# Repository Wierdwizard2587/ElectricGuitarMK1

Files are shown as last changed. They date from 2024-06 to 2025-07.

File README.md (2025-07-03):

# Electronic Guitar MK1

> A self-built, digitally-enhanced electric guitar featuring onboard effects, audio output and removable battery supply all integrated within a custom made Guitar.

---

## TL;DR Overview

- DIY portable electric guitar with integrated digital effects and modular power/audio system  
- Final version features Teensy 4.0, onboard FX, rotary encoder UI, OLED display, amp/speaker output, battery or DC power, and RGB lighting  
- Entire build: woodwork, PCBs, 3D prints, firmware, and more  
- Early prototype (Mk0) failed due to poor electrical design and overcomplex hardware, rebuilt from scratch over 12+ months with newly acquired engineering and fabrication skills  



---

## Specs (MK1)

### Hardware Features

- **Microcontroller:** Teensy 4.0 (600 MHz ARM Cortex M7, 1MB RAM)  
- **Audio Codec:** SGTL5000 via Teensy Audio Shield Rev D2  
- **Display:** 2.42" 128x64 OLED  
- **UI:** 4x rotary encoders (Adafruit I2C) with push buttons  
- **Output Options:**
  - 1W LM386 speaker amp + 8Ω speaker  
  - 3.5mm headphone jack  
  - 1/4" AUX output  
- **SD Card:** for saving and loading effect presets  



### Physical Design

- Custom red cedar guitar body with Strat-style neck and 22 frets  
- SSH passive pickup layout with 5-way selector  
- CNC acrylic panels for access and wiring  
- Modular 3D-printed brackets for internals  
- Magnetic battery bay  



### Power System

- **Battery:** 4S 18650 3500mAh Li-ion (16.8V max)  
- **BMS:** With overcharge/discharge protection  
- **Power Switching:** Automatically defaults to DC jack if plugged in  
- **Regulation:** L7805 LDO for logic, raw voltage for amp  
- **Runtime:** ~12 hours full load; much longer with optimized settings  



### RGB Lighting

- 6x WS2812B addressable LEDs  
- Controlled via UI with adjustable patterns and brightness  
- 5V from Teensy board, expandable via breakout  
- Mounted in a custom 3D enclosure with acrylic cover  
- See [Demo](https://github.com/Wierdwizard2587/ElectricGuitarMK1/raw/main/Progress%20Photos/Woodworking/IMG_9428.MOV)

### Design Decisions

- Abandoned analog FX + digipots due to impractical voltage/current handling  
- Digital FX chain implemented using Teensy Audio Library and CODEC  
- Custom single-layer PCB with JST headers for modularity  
- UI system built around I2C rotary encoders and OLED display  
- 3D-printed brackets standardized component mounting across internal assemblies  

### Tools and Processes

#### PCB Manufacturing

- **Chemical Etching:** Photoresist UV method with ferric chloride; scrapped due to accuracy and double-sided complexity  
- **CNC Milling:** Used FlatCAM to generate G-code, 3018 CNC and Candle for trace and drill cuts  

#### SMD Soldering

- **Stencil:** CNC-cut mylar sheets for paste application  
- **Soldering:** SMD components placed and reflowed on hot plate  



#### CAD and Design

- **KiCAD:** For schematic capture and board layout  
- **FreeCAD:** For PCB enclosure, LED mount, Guitar Body, Acrylic Plates/Panels and Router Jigs  

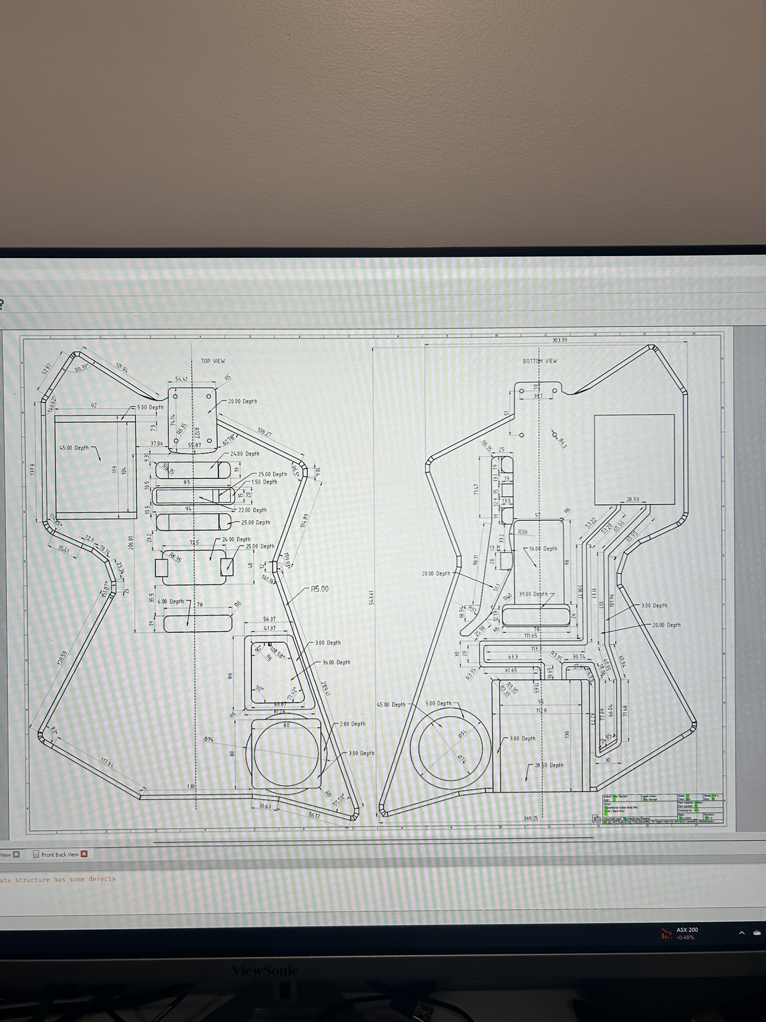
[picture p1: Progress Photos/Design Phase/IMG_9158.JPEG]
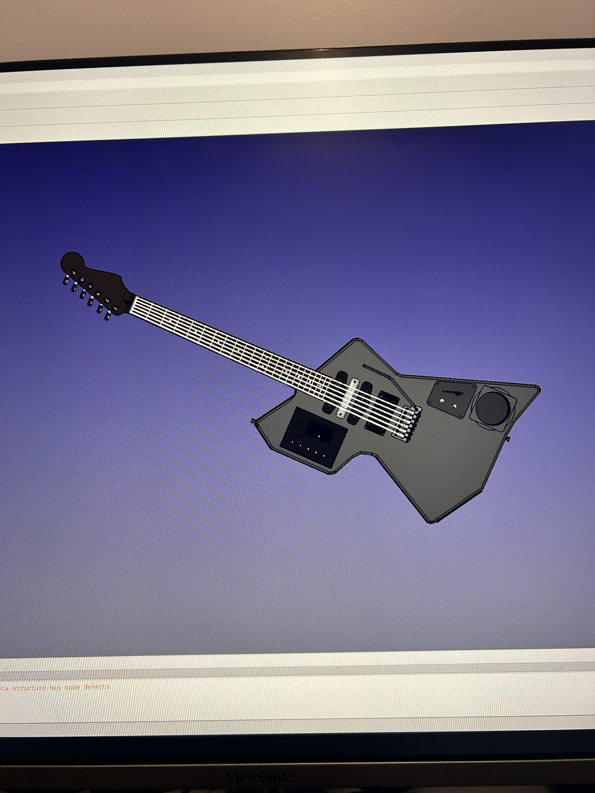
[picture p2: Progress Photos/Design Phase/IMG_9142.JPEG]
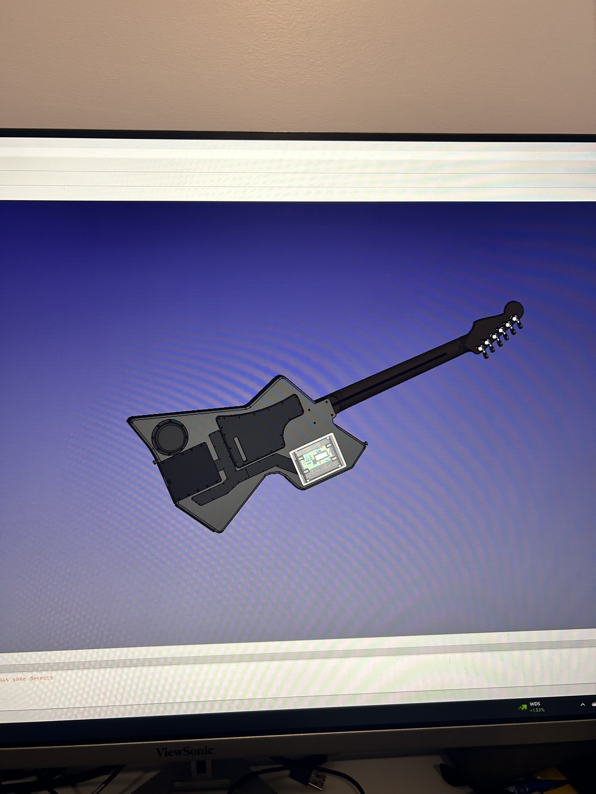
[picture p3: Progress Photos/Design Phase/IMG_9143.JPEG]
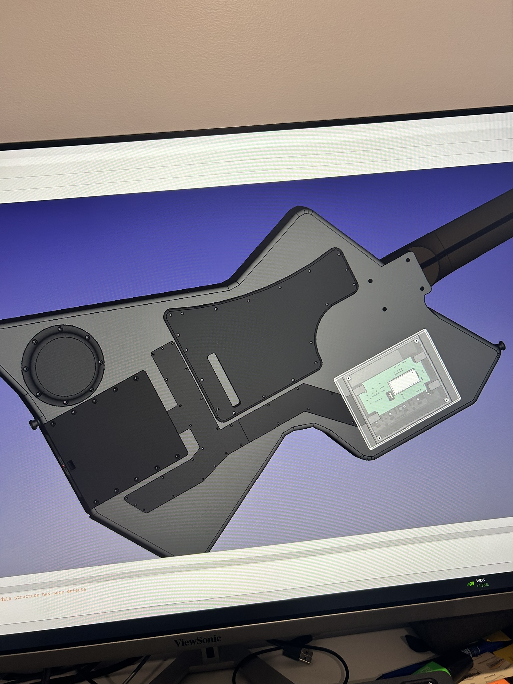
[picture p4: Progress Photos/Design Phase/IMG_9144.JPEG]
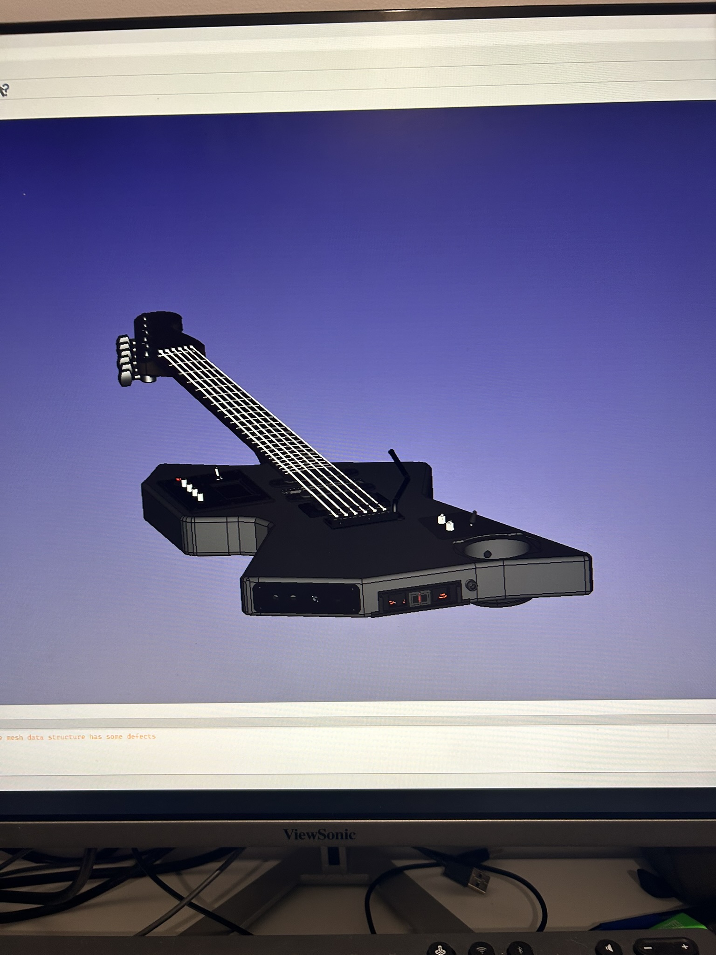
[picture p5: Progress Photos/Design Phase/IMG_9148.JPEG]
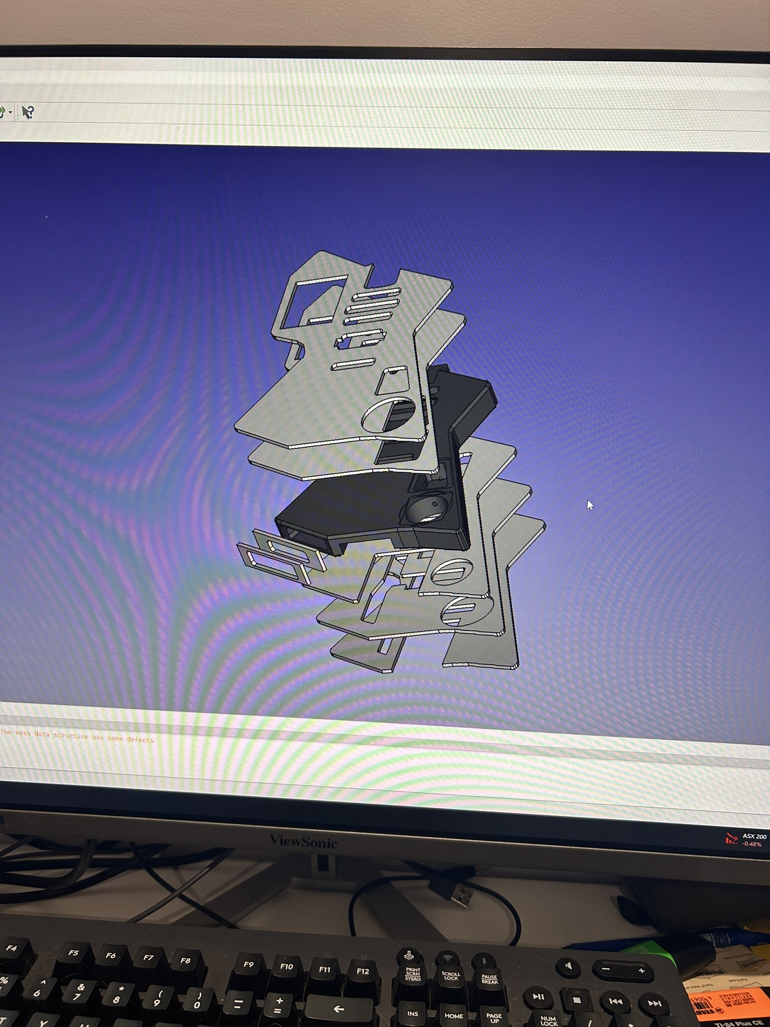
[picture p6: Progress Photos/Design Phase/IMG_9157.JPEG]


---

## Mk0 — The Failed First Attempt

The Mk0 was an ambitious retrofit of a cheap Stratocaster copy, originally sourced second-hand for $20 AUD. At the time, I had no electrical engineering knowledge and was only experienced with basic Arduino and Raspberry Pi projects.

### Body and Structural Work
- The original guitar was re-routed to fit electronics, resulting in reduced structural integrity and balance
- Body was repainted and cleaned up with minor woodworking skills from high school
- Attempted to house a Raspberry Pi, amplifier board, fans, wiring and more. all glued to plywood mounts inside the guitar



### Electronics and Power Mistakes
- Raspberry Pi 3B+ used for DSP software and effects switching via Linux keybinds
- 10x SPST buttons mapped to GPIO pins, wired manually without debounce or shielding
- Cooling: a heatsink and fan were mounted directly into the guitar body, protruding through the top
- Power: attempted to use a Makita 18V battery regulated by a voltage divider made from two 10W resistors (which exploded)
- Eventually switched to an XL6009 buck converter, mounted haphazardly on wood



### Audio and Shielding Failures
- Output sound had constant noise and interference, making the guitar unplayable
- Tried shielding the cavity with copper tape and spray enamel, but issues persisted
- Lack of analog audio knowledge led to poor layout and grounding, introducing hum and feedback

### Realization and Reset
- The experience made clear the importance of proper voltage regulation, shielding, grounding, and modular design
- Mk0 taught me the value of planning, measurement, and using the right components for audio and power
- In October 2023, I decided to scrap the build and committed to rebuilding everything from scratch

---

## The Learning Curve

To succeed with Mk1, I developed and refined skills across multiple disciplines:

- **Electrical theory and circuit design**
  - Learned core principles like Ohm’s Law, impedance, decoupling, signal paths, and analog vs digital tradeoffs by experimenting with breadboarded op-amp FX circuits and 555 timer modules.

- **Breadboarding, debugging, and perfboarding**
  - Built multiple guitar pedal-style analog effects, troubleshooting noise, biasing, and layout issues. Early soldering mistakes taught me good pad heating, proper joint inspection, and signal path discipline.

- **Custom PCB manufacturing**

  - *Chemical etching:* Photoresist and ferric chloride techniques worked for simple single-sided boards, but alignment and etch consistency were poor for complex layouts.

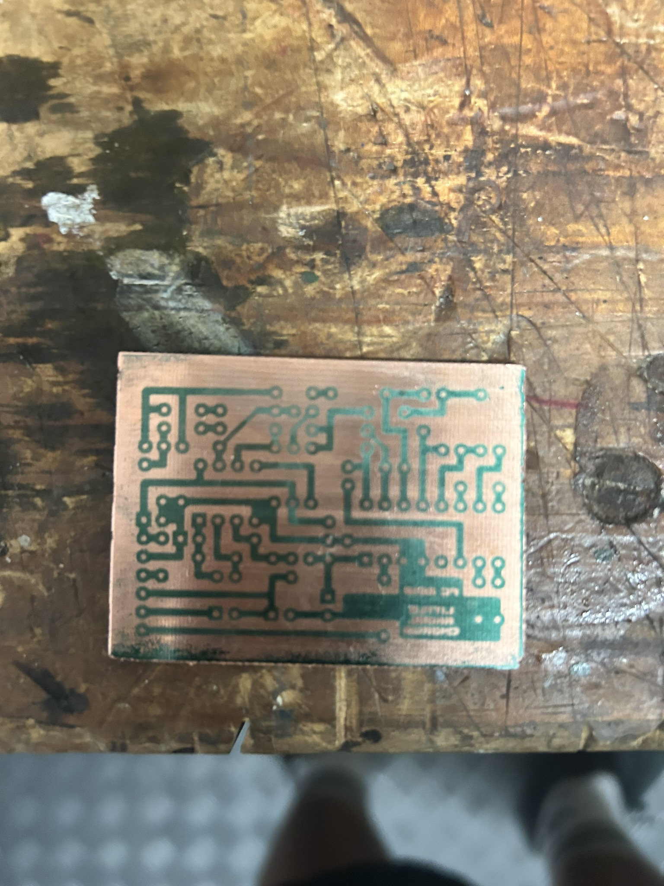
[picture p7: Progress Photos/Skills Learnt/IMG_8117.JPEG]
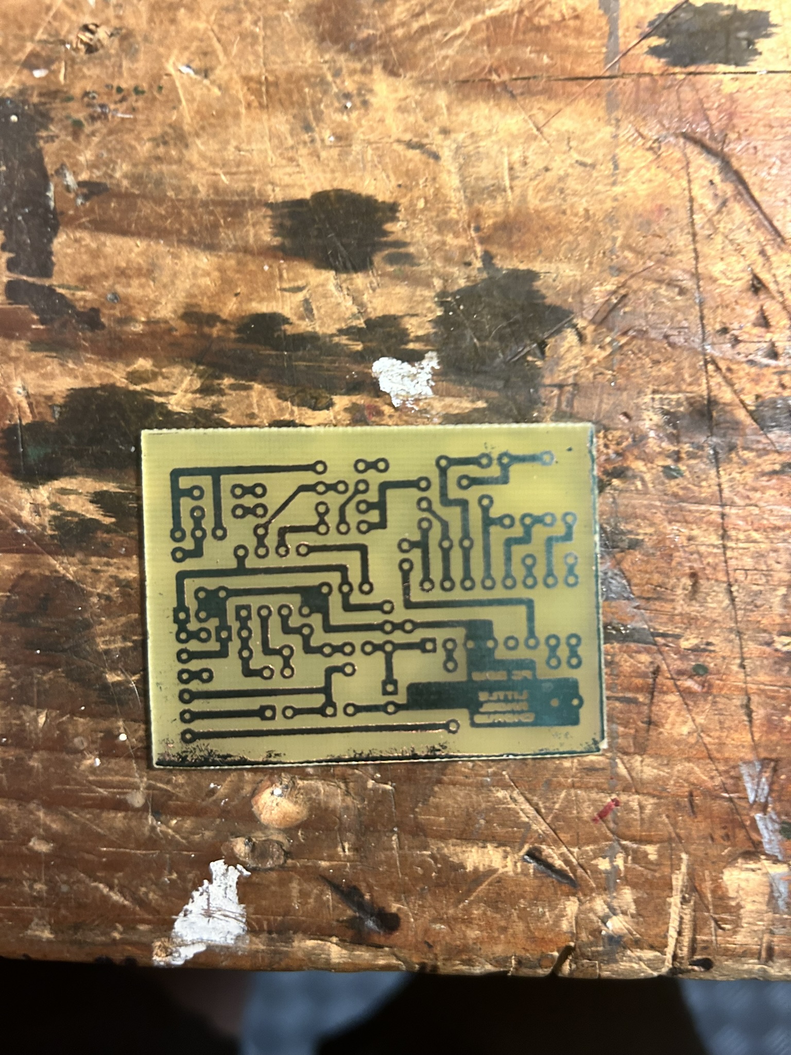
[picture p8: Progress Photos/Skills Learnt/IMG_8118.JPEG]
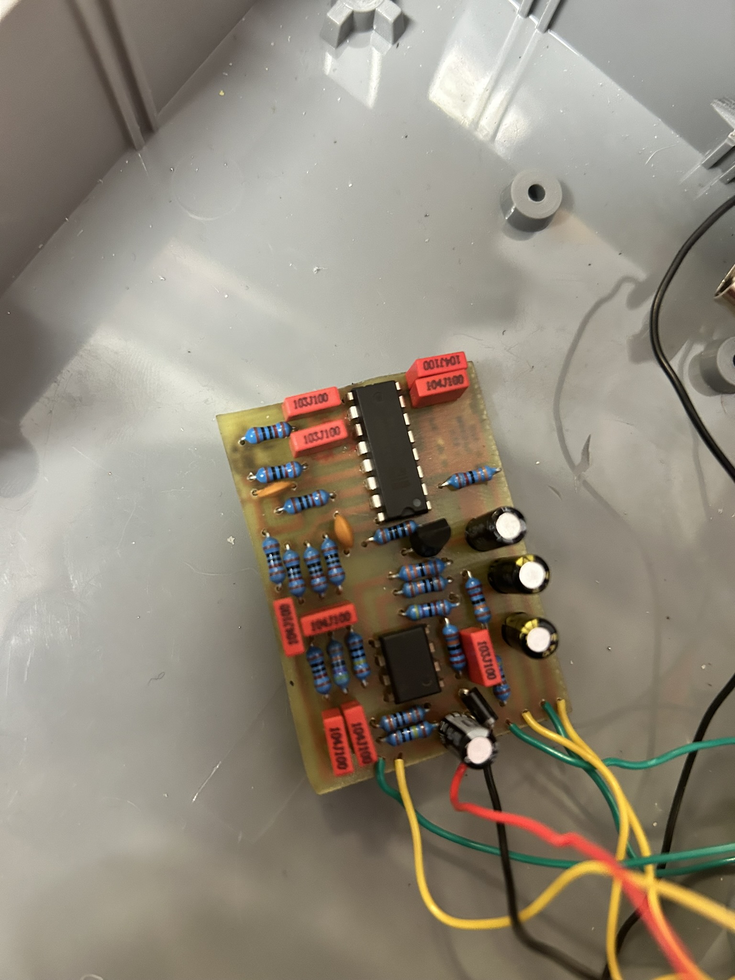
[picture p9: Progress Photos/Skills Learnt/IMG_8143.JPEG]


https://github.com/user-attachments/assets/e00821a1-996f-4fed-b84c-7d602e0a9be1

  - *CNC milling:* FlatCAM used to generate G-code from KiCAD Gerbers. I used a 3018 CNC with Candle to reliably cut traces and drill holes. Ultimately switched to ordered boards for reliability.

https://github.com/user-attachments/assets/3b78b966-fe12-4d0b-8b32-34254987f5ec

- **SMD workflow and hot plate reflow soldering**
  - Designed and cut my own mylar stencils for solder paste, allowing for precise paste application and fast assembly of SMD components on the hot plate.

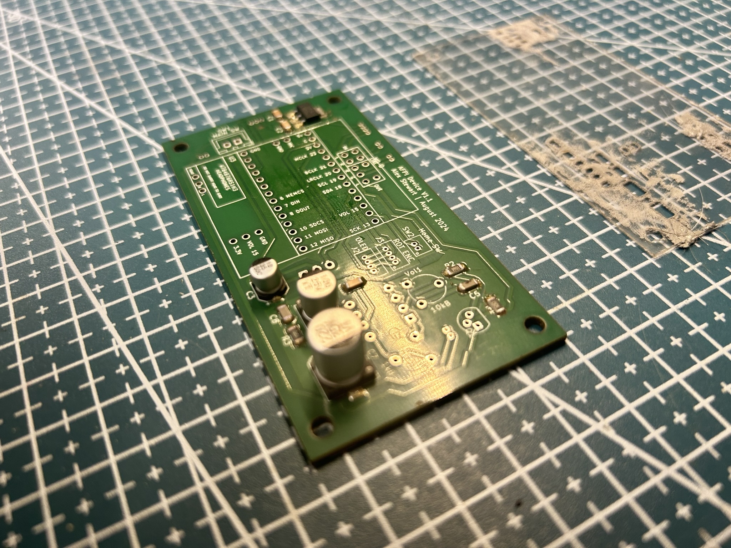
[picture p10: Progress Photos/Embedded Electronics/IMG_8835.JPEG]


- **Power systems and battery safety**
  - Studied Li-ion cell characteristics, pack balancing, protection circuits, and BMS behavior. Designed a 4S pack system with safe cutoff and swappable magnetic connection.

- **CAD and fabrication**
  - *KiCAD:* Used to design full schematics and board layouts with JST headers and part footprints.

  - *FreeCAD:* Modeled body routing templates, control panel shapes, bracket mounting, and tolerance-critical neck fits.

- **CNC woodworking and mechanical precision**
  - Created tight-fitting neck pockets and pickup cutouts with minimal play, ensuring mechanical stability and alignment.
 
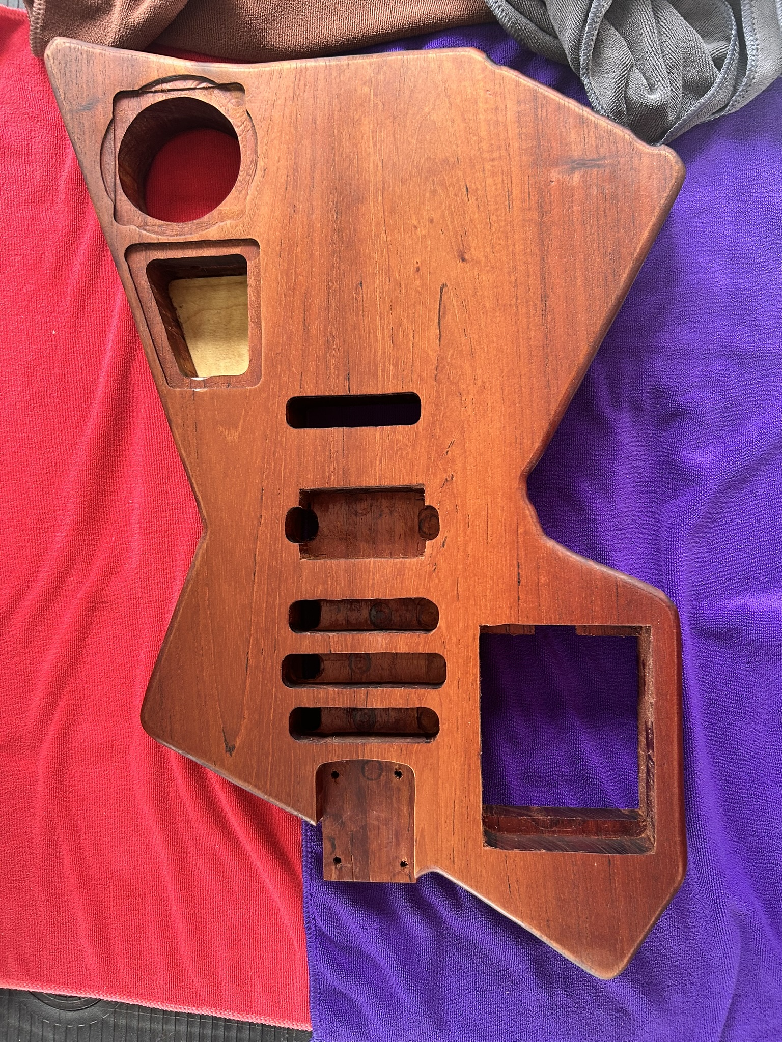
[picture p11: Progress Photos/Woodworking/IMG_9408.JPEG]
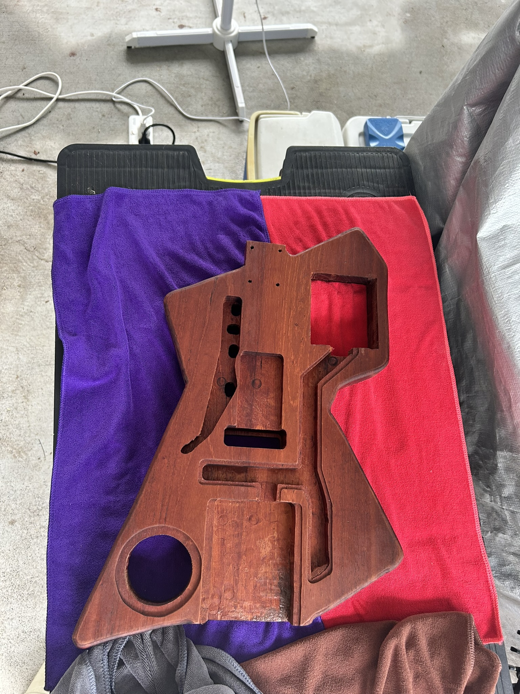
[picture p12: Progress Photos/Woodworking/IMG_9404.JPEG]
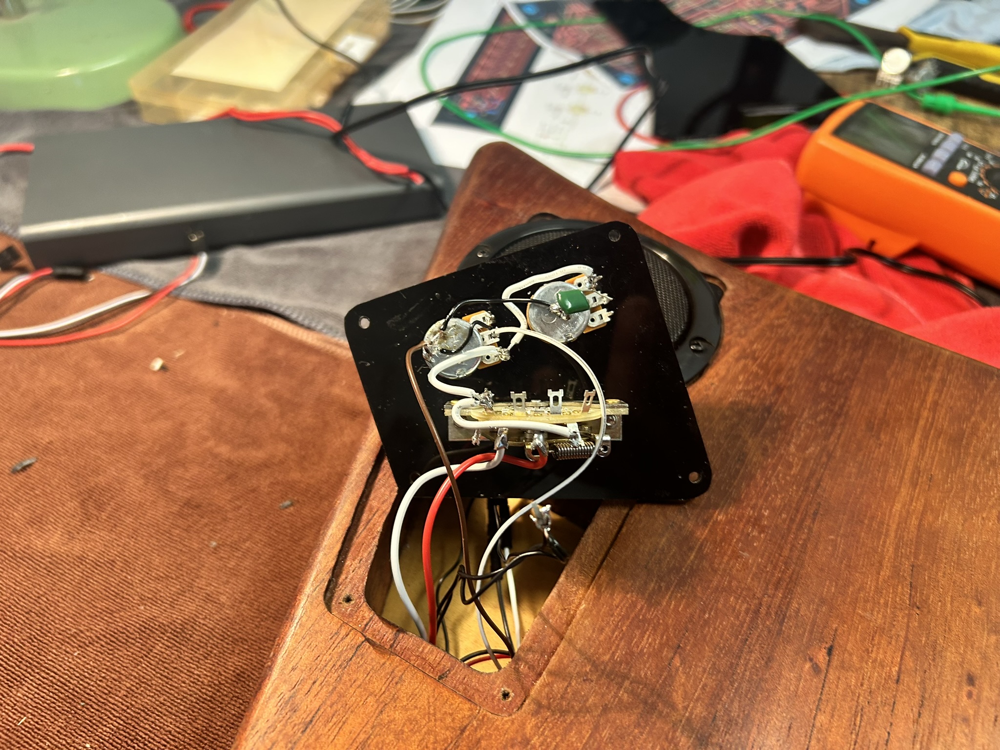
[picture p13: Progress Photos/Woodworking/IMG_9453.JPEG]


Each step of the learning process fed directly into the reliability and performance of the final Mk1 design.

---

## Final Words

This project started with a failed experiment and turned into a comprehensive learning journey in electrical engineering, embedded systems, and digital fabrication. Every element—hardware, software, and mechanical—was designed, built, and tested from scratch with the goal of making a fully integrated, self-contained electric guitar. I am very proud of what I was able to accomplish and am very excited to now use and build this new knowledge and gained abilitys to even bigger and better things!

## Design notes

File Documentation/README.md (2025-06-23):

# The Electronic Guitar MK1

## Introduction
During the second half of 2023, I began experimenting with a concept of an 'all in one portable electric guitar'. The device would contain built in electronics for digital audio effects and signal modulation with an optional audio output between a 1 watt amplifier and speaker, headphone amp with 3.5mm jack, or a 1/4" jack for aux out for further modulation and amplification, all of which powered by either a removable rechargable battery or 2.5mm DC jack. My first attempt at this concept to put it simply was a failure, but a neccesary one. read [here]((#electric-guitar-mk0-first-attempt)) for the full

## My Prior Background
I had started my Computer Science degree at the start of 2023 and before that had fiddled around with arduino and ESP32 Microcontroller projects, creating basic circuits and novice C programming with some very basic electrical theory, however this project was nothing like I had ever attempted. I also had some experience with woodworking through high school and personal jobs in the shed at home, but the craftmanship I needed for this task was also not ready. While my background was rather unimpressive, I was determined to complete this project myself by any means. This of course meant a great deal of learning and problem solving, and over the next 1.5 years (august 2023 - december 2024) I did sought out to do just that. 







## Features
The features of this Guitar are seperated into the following sections:

### AFPI Features:
  - **Teensy 4.0 microcontroller:**
    - ARM Cortex M7 600MHz 
    - 2mB Flash
    - 1mB RAM
    - 40 GPIO pins
    - 100mA @ 5V
   
    <br> 
  - **Teensy Audio Shield Rev D2:**
    - SGTL5000 Audio Codec
    - integrated Headphone Amp
    - SD Card Slot

    <br>
  - **Power regulation**
    - Recieves power input from battery/DC jack
    - L7805 LDO regulator to reduce voltage to 5V for Digital Circuit components
    - uses regular voltage from input for speaker amp for a louder sound

    <br> 
  - **Adafruit IC2 Quad Rotary Encoder Board:**
    - Communication to Microcontroller via IC2 protocol
    - 1x4 20 position rotary encoders with push down buttons
   
     <br> 
  - **2.42 inch 128*64 OLED Display Module:**
    - SSD1306 OLED display library
   
    <br> 
  - **1 watt Speaker amplifier:**
    - lm386 op amp
    - trimmable Volume and Gain for installation
    - based on Ruby Amp design

  - Firmware switchable audio output between Built in speaker, Headphones or Aux out
  - Aux in 3.5mm jack for playing external audio from other devices
  - SD card memory to recall saved user settings for effects and other settings











### Power Supply Features:
  - Power supply from either DC 2.5mm Barrel Connector OR 3500mAh battery
  - switches to wired power supply over the battery automatically when plugged in

  - **DC Input:**
    - 2.5mm DC 
    - 7V to 18V input

  - **Removable 3500mAh Battery:**
    - 4S 18650 3.7V Li ion Battery cell arrangement
    - 16.8 Nominal Voltage
    - 10.5V over-discharge and 17V over-charge protection
    - magnetic connecting pins between battery casing and built-in battery slot in guitar
    - ~12hrs run time when operating speaker on maximum volume, full LED brightness and OLED brightness.
    - Run time increases greatly when limiting brightness and audio settings slightly
    - Capability to provide Battery charge to Microcontroller in future modifications



### RGB Lighting Features:
  - 1x6 row of WS2812B 5050 SMD NeoPixel RGB LED's
  - each LED uniquely addressable via IC2 Protocol, allowing for any colour and brightness on each LED
  - Control the LEDs settings and the preset effect styles selectable through the User Interface
  - 5V operating Voltage and data supplied from AFPI to RGB lighting PCB
  - RGB PCB including extra Data Output for modular expansion of lighting to other areas of the Guitar
  - RGB PCB encased in a 3d printed mounting bracket to fit in the body, as well as to attach clear acrylic cover plate

https://github.com/Wierdwizard2587/ElectricGuitarMK1/raw/refs/heads/main/Progress%20Photos/Woodworking/IMG_9428.MOV

### Physical Design Features:
  - Custom designed Body shape
  - Red Ceder wood for body
  - CNC milled Acrylic Top and Back plates for switch plates and wire route coverings
  - 3D printed Components for mounting electrical components into Body as modular sections



### Guitar specific Features:
  - SSH passive pickup layout, with pins available for active pickups
  - 22 Fret stratocaster syle neck
  - 5 way pickup selector switch layout
  - 1x master Volume potentiometer
  - 1x master Gain potentiometer

## Electric Guitar MK0 (first attempt) 
I first came up with this concept around July 2023, where a regeular guitar could be retro fitted with electronics to create a cheap, simple portable electric guitar. Oh how wrong i was. With some moderate experience in playing with arduino's and Raspberry Pi's, a good bit of wood working experience with dad, and no electrical engineering experience, I set out on accomplishing my goal.



For the Guitar itself i had a chinese strat laying around that i found second hand at an Op shop for 20$ that i never used, because obviously it sounded terrible. The electronics were barely working, it was missing a tuning peg and just sounded terrible! but after cleaning it up, re wiring it with new cheap pickups and new tuning pegs, it was somewhat playable. i then totally destroyed the guitar by then routing out long wire tracks and spots for components among other things. I reckon it was less then half the weight of its former self when i was done with it. I repainted The boddy and neck Black and moved on to the electronics.




For the Audio processing and effect portion of the guitar i chose a raspberry Pi 3 B+, not for any spec reasons, but because it was just laying around. after fiddling around with some DSP applications for linux i chose one that had multiple effect presets and keybinded them each. I then got 10 SPST buttons and wired each individual one to 10 different GPIO pins very inefficiently. these buttons then used a simple script to map each button to a key press to toggle the presets, that was the entire interface portion of the Guitar. The processing requirements for the DSP really created a cooling problem for the guitar which i 'solved' by mounting a large heatsink and fan to the processor, which required a large hole to be cut out of the guitar body, not only to accomodate the Pi itself, but also to fit the fan raised by the large heat pipes. 



For power delivery, about the only thing to stay remotely similar to the final guitar was to have a DC jack and a Battery, however instead of a custom battery, I made use of a makita 18v tool battery and just got a mount from ebay, which wasnt a terrible idea as using a pre existing battery would make it easier, however we are a ryobi family! i had to borrow a mates battery which got definetly annoying when he needed it for work. 

Now this is where it gets really embarrasing. my lack of electrical engineering knowledge led me down the research path of how i can regulate the voltage down to 5v for the Raspberry Pi, and i discovered the voltage divider circuit which obviously is not the way to solve my problem due to the incredible inneficiency and the lack of any actual regulation of voltage, but 18yr old me thought it did. so strapped 2x 10Watt resistors into a very poor arrangement to lower the voltage, which most definetely wasn't done correctly and one of them blew up. this lead me to try the DCDC converter XL6009 which was better. But again, I was mounting all this on bare ply wood with hot glue, it was such a poor design approach from me. I included an audio amplifier module for 2 speakers at 5w 4ohm each.

After testing it out together, all i got was terrible noise from the pickups, resulting in an unplayable device. I wrapped the interior with copper tape and sprayed in with a non conductive enamel coat to prevent shorts. This was done to prevent EMI which i though was the issue, however looking back on it, there were definetely other issues at play relating to my poor designing techniques and a million other things. 




This all took place between July 2023 to October 2023 and after repeated failures to get the guitar to sound remotely like a guitar, I decided to remember what worked, what didnt and i scrapped my current progress and started from scratch. I vowed to create as much of the guitar myself so i could fully grasp what was taking place within the product. whether it be circuit boards, programming, woodworking and CNC work, I then embarked on a 1 year long journey to create the Electronic Guitar no matter the cost, and no matter what problems stood in my way as this became personal. I would take my time researching not only different components, tools, techniques and practises, but also the basis of managing a project. From the design progress, cost management and other essential skills, I used my determination to succeed (My goal was to get it finished by July 2024, I was far off).

## Skills learnt

## Technical In Depth

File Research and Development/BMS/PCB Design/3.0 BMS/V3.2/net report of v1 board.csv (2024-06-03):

Net Code | Net Name | Pad Count | Via Count | Via Length | Track Length | Die Length | Net Length | F.Cu | B.Cu
001 | Batt + | 11 | 2 | 3.2000 mm | 93.7471 mm | 0.0000 mm | 96.9471 mm | 72.3739 mm | 21.3732 mm
002 | Batt - | 4 | 0 | 0.0000 mm | 42.4740 mm | 0.0000 mm | 42.4740 mm | 42.4740 mm | 0.0000 mm
003 | Chgr operating 12V+ | 4 | 0 | 0.0000 mm | 34.8560 mm | 0.0000 mm | 34.8560 mm | 34.8560 mm | 0.0000 mm
004 | Chgr sgl 15V+ | 3 | 0 | 0.0000 mm | 49.2855 mm | 0.0000 mm | 49.2855 mm | 49.2855 mm | 0.0000 mm
005 | 5v attiny out | 6 | 0 | 0.0000 mm | 93.5043 mm | 0.0000 mm | 93.5043 mm | 93.5043 mm | 0.0000 mm
006 | Net-(Q2-B) | 2 | 0 | 0.0000 mm | 4.3180 mm | 0.0000 mm | 4.3180 mm | 4.3180 mm | 0.0000 mm
007 | DCG SW VCC | 2 | 0 | 0.0000 mm | 2.9492 mm | 0.0000 mm | 2.9492 mm | 2.9492 mm | 0.0000 mm
008 | Reg Batt 9v | 4 | 2 | 3.2000 mm | 74.9748 mm | 0.0000 mm | 78.1748 mm | 50.0106 mm | 24.9642 mm
009 | CGE SW VCC | 2 | 2 | 3.2000 mm | 65.4986 mm | 0.0000 mm | 68.6986 mm | 20.7501 mm | 44.7485 mm
010 | Net-(Q7-B) | 2 | 0 | 0.0000 mm | 4.6160 mm | 0.0000 mm | 4.6160 mm | 4.6160 mm | 0.0000 mm
011 | Battery Vref | 3 | 0 | 0.0000 mm | 37.4979 mm | 0.0000 mm | 37.4979 mm | 37.4979 mm | 0.0000 mm
012 | Batt SW VCC | 2 | 0 | 0.0000 mm | 35.3685 mm | 0.0000 mm | 35.3685 mm | 35.3685 mm | 0.0000 mm
013 | Net-(R12-Pad2) | 3 | 2 | 3.2000 mm | 40.3498 mm | 0.0000 mm | 43.5498 mm | 11.4621 mm | 28.8877 mm
014 | Net-(U4-P2) | 2 | 0 | 0.0000 mm | 12.9343 mm | 0.0000 mm | 12.9343 mm | 12.9343 mm | 0.0000 mm
015 | 15v+ CHG VCC | 8 | 0 | 0.0000 mm | 45.5027 mm | 0.0000 mm | 45.5027 mm | 45.5027 mm | 0.0000 mm
016 | Net-(U4-P1) | 2 | 0 | 0.0000 mm | 12.1084 mm | 0.0000 mm | 12.1084 mm | 12.1084 mm | 0.0000 mm
017 | Net-(D1-A) | 3 | 0 | 0.0000 mm | 13.4361 mm | 0.0000 mm | 13.4361 mm | 13.4361 mm | 0.0000 mm
018 | Net-(U3-FB) | 4 | 0 | 0.0000 mm | 17.9684 mm | 0.0000 mm | 17.9684 mm | 17.9684 mm | 0.0000 mm
020 | OUT 9V+ | 2 | 0 | 0.0000 mm | 15.4306 mm | 0.0000 mm | 15.4306 mm | 15.4306 mm | 0.0000 mm
021 | Net-(B1-B1+) | 3 | 1 | 1.6000 mm | 119.5845 mm | 0.0000 mm | 121.1845 mm | 7.5880 mm | 111.9964 mm
022 | Net-(B1-B1-) | 5 | 1 | 1.6000 mm | 203.4040 mm | 0.0000 mm | 205.0040 mm | 8.1461 mm | 195.2580 mm
023 | Net-(B2-B1-) | 5 | 1 | 1.6000 mm | 73.8197 mm | 0.0000 mm | 75.4197 mm | 49.6937 mm | 24.1261 mm
024 | Net-(B3-B1-) | 5 | 0 | 0.0000 mm | 223.5093 mm | 0.0000 mm | 223.5093 mm | 223.5093 mm | 0.0000 mm
025 | Net-(B4-B1-) | 3 | 0 | 0.0000 mm | 151.4014 mm | 0.0000 mm | 151.4014 mm | 151.4014 mm | 0.0000 mm
028 | Charge supplied VCC | 2 | 0 | 0.0000 mm | 28.0132 mm | 0.0000 mm | 28.0132 mm | 28.0132 mm | 0.0000 mm
032 | Net-(U4-P0) | 2 | 2 | 3.2000 mm | 82.4156 mm | 0.0000 mm | 85.6156 mm | 61.7874 mm | 20.6282 mm
033 | GND | 19 | 10 | 16.0000 mm | 304.4670 mm | 0.0000 mm | 320.4670 mm | 182.9421 mm | 121.5249 mm
034 | charger GND bypass | 2 | 0 | 0.0000 mm | 2.3711 mm | 0.0000 mm | 2.3711 mm | 2.3711 mm | 0.0000 mm
035 | Net-(Q1-G) | 4 | 2 | 3.2000 mm | 45.6061 mm | 0.0000 mm | 48.8061 mm | 15.3627 mm | 30.2434 mm
036 | Net-(SW1A-B) | 2 | 0 | 0.0000 mm | 18.6588 mm | 0.0000 mm | 18.6588 mm | 18.6588 mm | 0.0000 mm

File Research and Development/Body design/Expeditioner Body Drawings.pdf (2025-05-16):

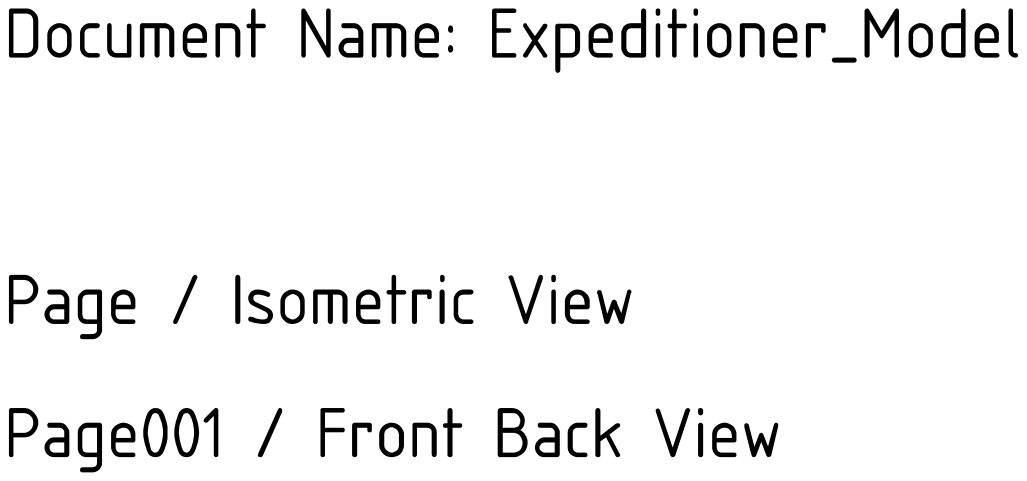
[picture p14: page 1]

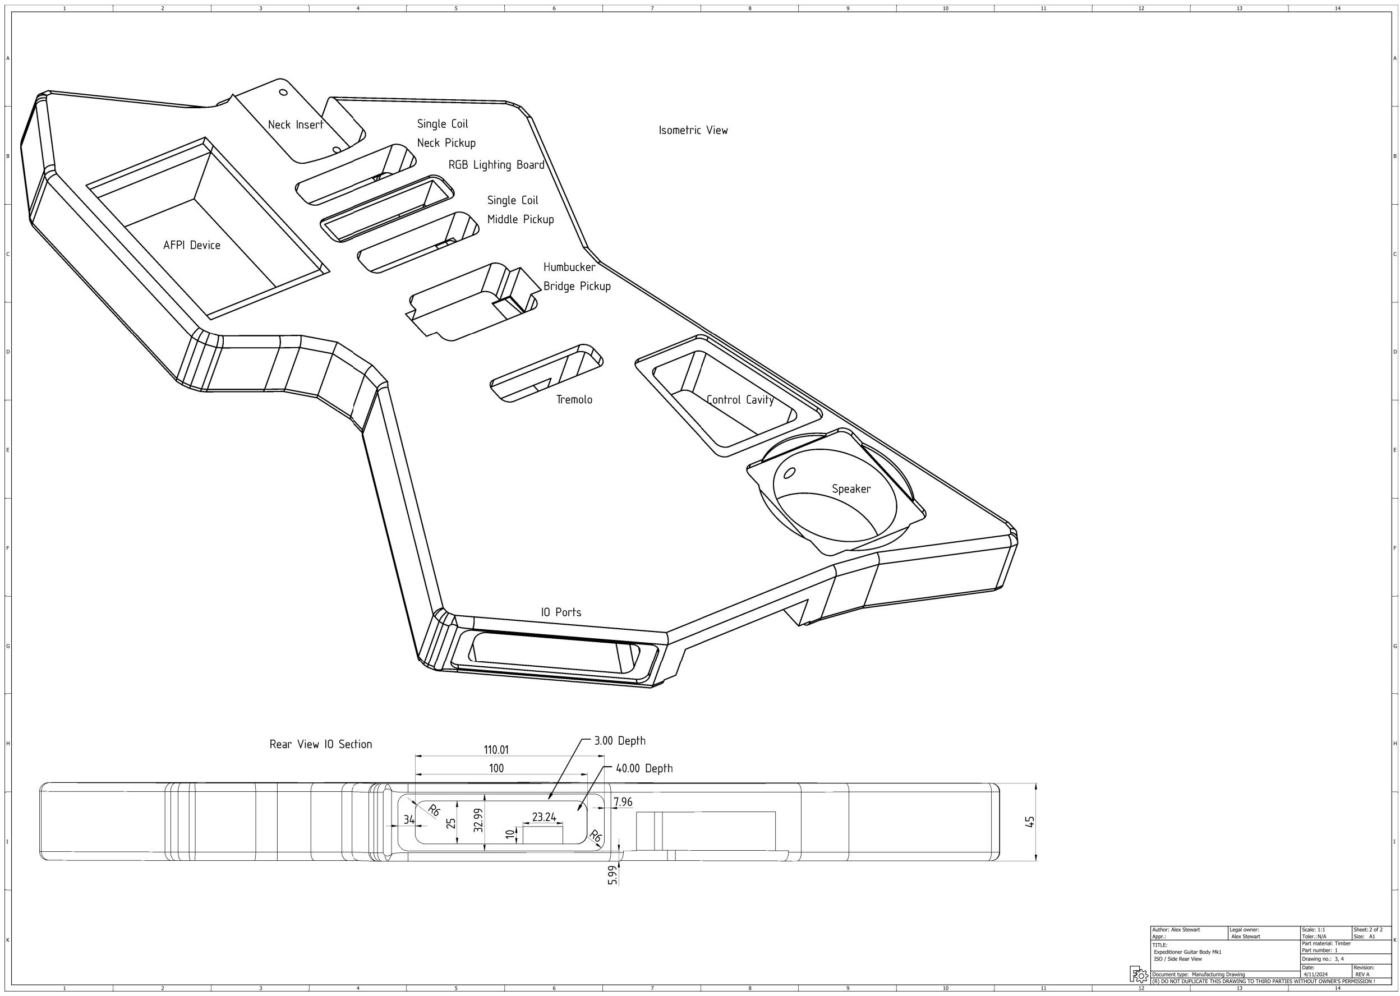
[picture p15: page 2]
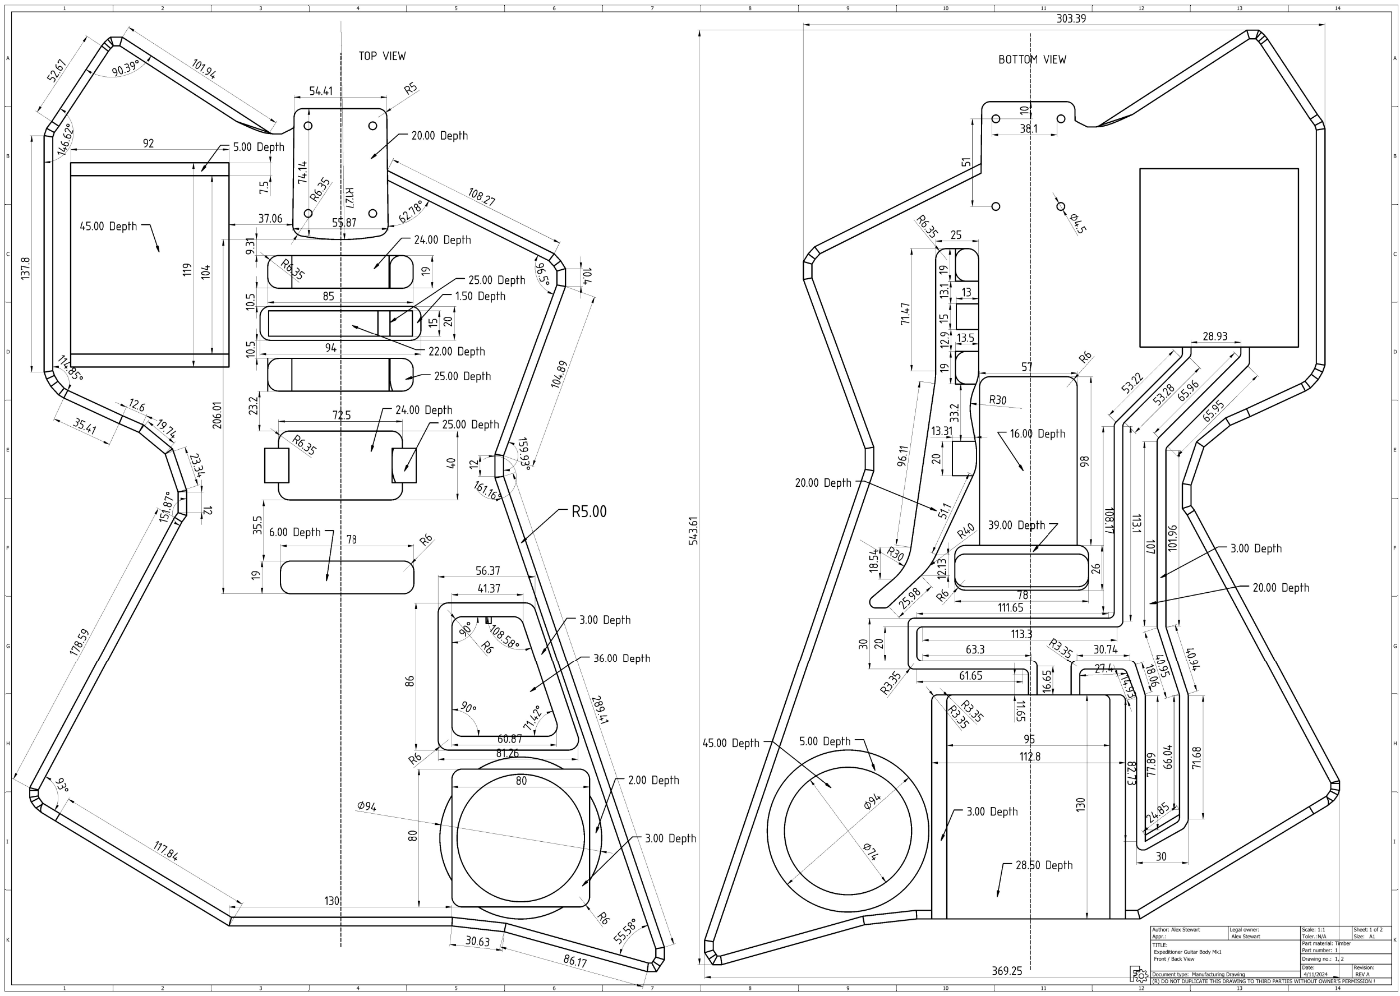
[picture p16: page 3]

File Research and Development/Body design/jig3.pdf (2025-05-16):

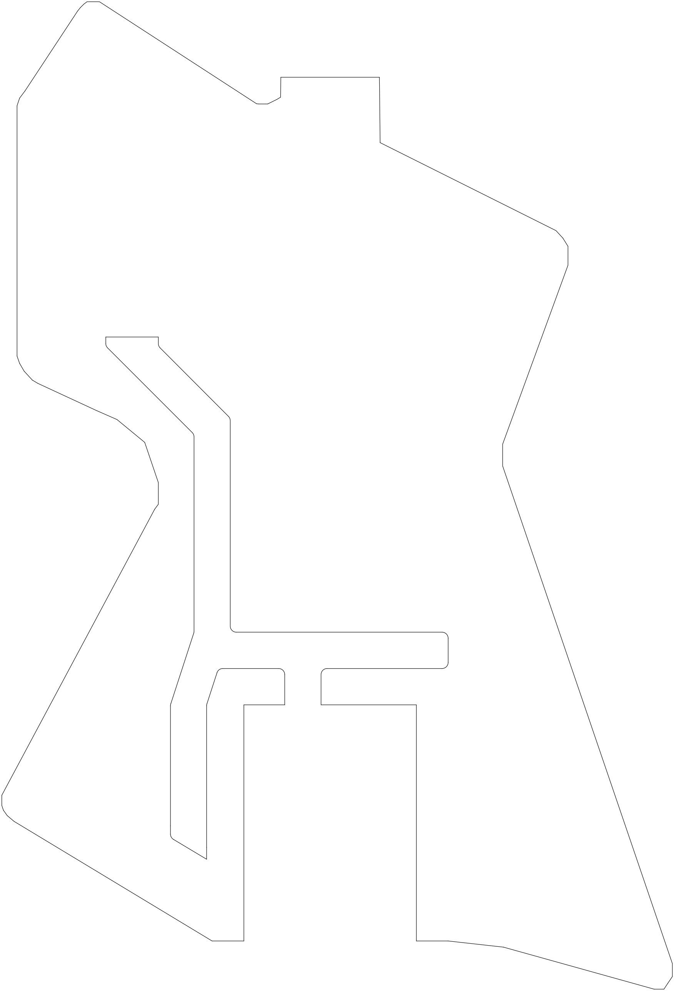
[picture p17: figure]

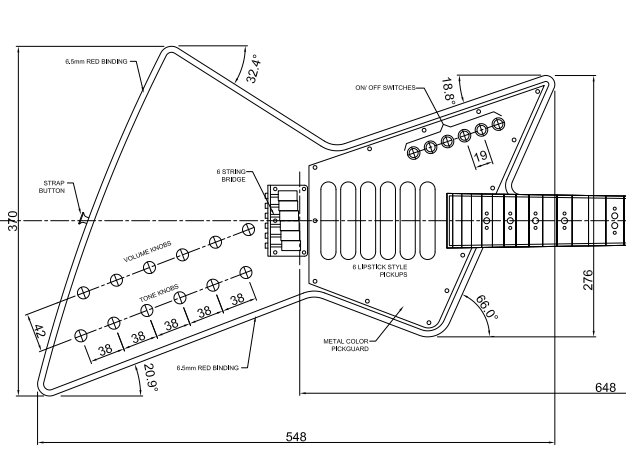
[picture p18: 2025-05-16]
Research and Development/Body design/3d models and docs/bettie model doc snippet.png

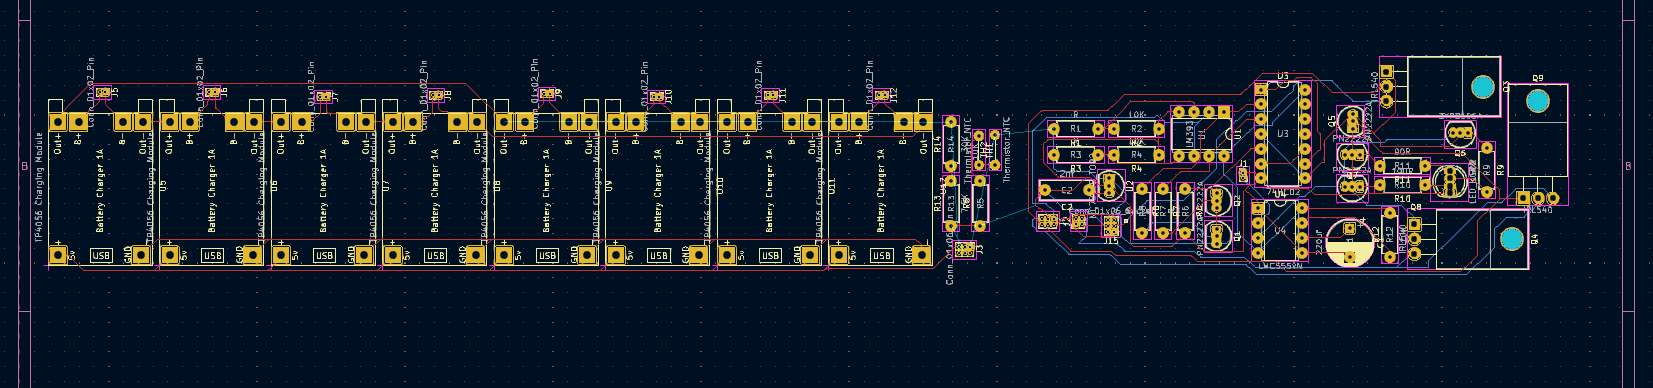
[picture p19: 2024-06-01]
Research and Development/BMS/PCB Design/1.0 BMS/1ST attempt bms pcb layout.png

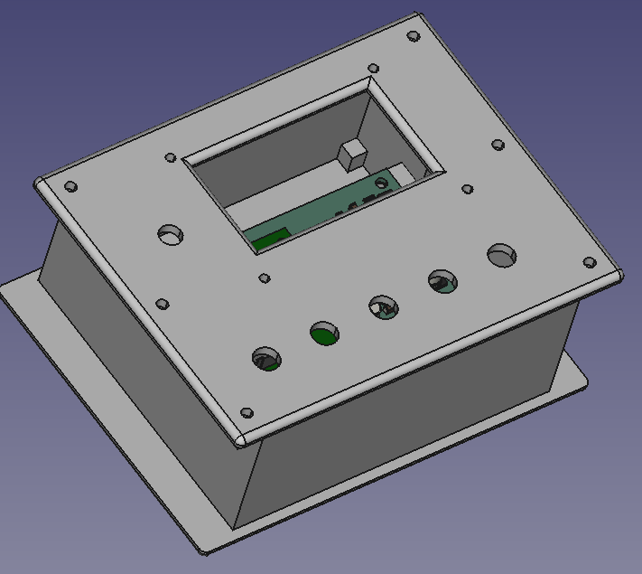
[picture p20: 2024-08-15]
Research and Development/Interface Section/AFPI/Enclosure Design/AFPI Final Documents/Enclosure Images/top view without peripherals.png

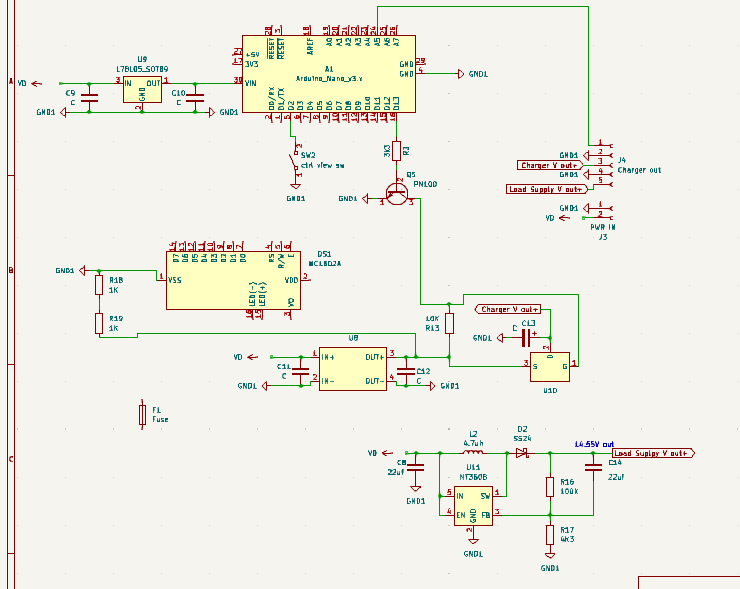
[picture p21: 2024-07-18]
Research and Development/BMS/PCB Design/3.0 BMS/V3.2/charger design v1.png

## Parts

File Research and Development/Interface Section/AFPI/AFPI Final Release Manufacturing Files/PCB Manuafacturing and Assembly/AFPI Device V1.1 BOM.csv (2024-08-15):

Id | Designator | Footprint | Quantity | Designation | Supplier and ref
1 | C1 | C_1206_3216Metric | 1 | 330nf
2 | C5,C8 | C_1206_3216Metric | 2 | 47n
3 | C2 | C_1206_3216Metric | 1 | 100nf
4 | Gain1 | Potentiometer_Piher_PT-6-V_Vertical | 1 | 1kB
5 | SW1 | JST_XH_B2B-XH-A_1x02_P2.50mm_Vertical | 1 | MAIN SW
6 | J2 | JST 1.25mm THT 01x04 | 1 | OLED
7 | Vol1 | Potentiometer_Piher_PT-6-V_Vertical | 1 | 10kB
8 | R1 | R_1206_3216Metric | 1 | 1M5
9 | C6 | CP_Elec_6.3x7.7 | 1 | 100u
10 | J3 | JST 1.25mm THT 01x04 | 1 | ROT ENC
11 | C3 | CP_Elec_5x5.4 | 1 | 10uf 35V
12 | U1 | SOT-223 | 1 | L7805
13 | C7 | CP_Elec_8x10.5 | 1 | 220u
14 | R2 | R_1206_3216Metric | 1 | 3k9
15 | R3 | R_1206_3216Metric | 1 | 10R
16 | SW2 | JST 1.25mm THT 01x02 | 1 | Home SW
17 | U3 | Teensy 4.0 audioshield | 1 | Teensy4.0_AudioShield_REVD
18 | U2 | DIP-8_W7.62mm | 1 | LM386
19 | C4 | C_1206_3216Metric | 1 | 100n
20 | Q1 | TO-92 | 1 | MPF102
21 | J9 | JST 1.25mm THT 01x02 | 1 | BACK I
22 | J6 | JST 1.25mm THT 01x02 | 1 | SP O
23 | J1 | JST_XH_B3B-XH-A_1x03_P2.50mm_Vertical | 1 | Batt I
24 | J5 | JST 1.25mm THT 01x02 | 1 | HP O
25 | J8 | JST 1.25mm THT 01x04 | 1 | LINE I/PKP V
26 | J7 | JST 1.25mm THT 01x02 | 1 | AU O
27 | J4 | JST 1.25mm THT 01x03 | 1 | RGB O

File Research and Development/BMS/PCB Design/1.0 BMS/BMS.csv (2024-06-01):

Source: | C:\Users\acste\Desktop\BMS\BMS\BMS.kicad_sch
Date: | 2/04/2024 11:28:19 AM
Tool: | Eeschema 7.0.9
Generator: | C:\Program Files\KiCad\7.0\bin\scripting\plugins/bom_csv_grouped_by_value.py
Component Count: | 35
Collated Components:
Item | Qty | Reference(s) | Value | LibPart | Footprint | Datasheet | DNP
1 | 1 | C1 | 220uf | Device:C_Polarized | Capacitor_THT:CP_Radial_D8.0mm_P5.00mm | ~
2 | 1 | C2 | 2nf | Device:C |  | ~
3 | 1 | D1 | LED_KGRB | Device:LED_KGRB | LED_THT:LED_D5.0mm-4_RGB | ~
4 | 1 | J1 | Screw_Terminal_01x02 | Connector:Screw_Terminal_01x02 |  | ~
5 | 1 | J2 | Conn_01x04_Pin | Connector:Conn_01x04_Pin |  | ~
6 | 1 | J3 | Conn_01x03_Pin | Connector:Conn_01x03_Pin |  | ~
7 | 1 | J4 | Conn_01x06_Pin | Connector:Conn_01x06_Pin |  | ~
8 | 1 | K1 | SANYOU_SRD_Form_C | Relay:SANYOU_SRD_Form_C | Relay_THT:Relay_SPDT_SANYOU_SRD_Series_Form_C | http://www.sanyourelay.ca/public/products/pdf/SRD.pdf
9 | 5 | Q1, Q2, Q5, Q7, Q8 | PN2222A | Transistor_BJT:PN2222A | Package_TO_SOT_THT:TO-92_Inline | https://www.onsemi.com/pub/Collateral/PN2222-D.PDF
10 | 1 | Q3 | IRL540 | Transistor_FET:IRF540N | Package_TO_SOT_THT:TO-220-3_Vertical | http://www.irf.com/product-info/datasheets/data/irf540n.pdf
11 | 1 | Q6 | ZVP2106A | Transistor_BJT:PN2222A | Package_TO_SOT_THT:TO-92_Inline | https://www.onsemi.com/pub/Collateral/PN2222-D.PDF
12 | 5 | R1, R3, R6, R7, R8 | R | Device:R | Resistor_THT:R_Axial_DIN0207_L6.3mm_D2.5mm_P7.62mm_Horizontal | ~
13 | 4 | R2, R4, R5, R12 | 10K | Device:R | Resistor_THT:R_Axial_DIN0207_L6.3mm_D2.5mm_P7.62mm_Horizontal | ~
14 | 1 | R9 | 150R | Device:R | Resistor_THT:R_Axial_DIN0207_L6.3mm_D2.5mm_P7.62mm_Horizontal | ~
15 | 1 | R10 | 100R | Device:R | Resistor_THT:R_Axial_DIN0207_L6.3mm_D2.5mm_P7.62mm_Horizontal | ~
16 | 1 | R11 | 90R | Device:R | Resistor_THT:R_Axial_DIN0207_L6.3mm_D2.5mm_P7.62mm_Horizontal | ~
17 | 1 | R13 | 30K | Device:R | Resistor_THT:R_Axial_DIN0207_L6.3mm_D2.5mm_P7.62mm_Horizontal | ~
18 | 1 | R14 | 7.5K | Device:R | Resistor_THT:R_Axial_DIN0207_L6.3mm_D2.5mm_P7.62mm_Horizontal | ~
19 | 2 | TH1, TH2 | Thermistor_NTC | Device:Thermistor_NTC | Resistor_THT:R_Axial_DIN0204_L3.6mm_D1.6mm_P5.08mm_Vertical | ~
20 | 1 | U1 | LM393 | Comparator:LM393 | Package_DIP:DIP-8_W7.62mm | http://www.ti.com/lit/ds/symlink/lm393.pdf
21 | 1 | U2 | MC78L05_TO92 | Regulator_Linear:MC78L05_TO92 | Package_TO_SOT_THT:TO-92_Inline | https://www.onsemi.com/pub/Collateral/MC78L00A-D.PDF
22 | 1 | U3 | 74HC02 | 74xx:74HC02 | Package_DIP:DIP-14_W7.62mm | http://www.ti.com/lit/gpn/sn74hc02
23 | 1 | U4 | LMC555xN | Timer:LMC555xN | Package_DIP:DIP-8_W7.62mm | http://www.ti.com/lit/ds/symlink/lmc555.pdf

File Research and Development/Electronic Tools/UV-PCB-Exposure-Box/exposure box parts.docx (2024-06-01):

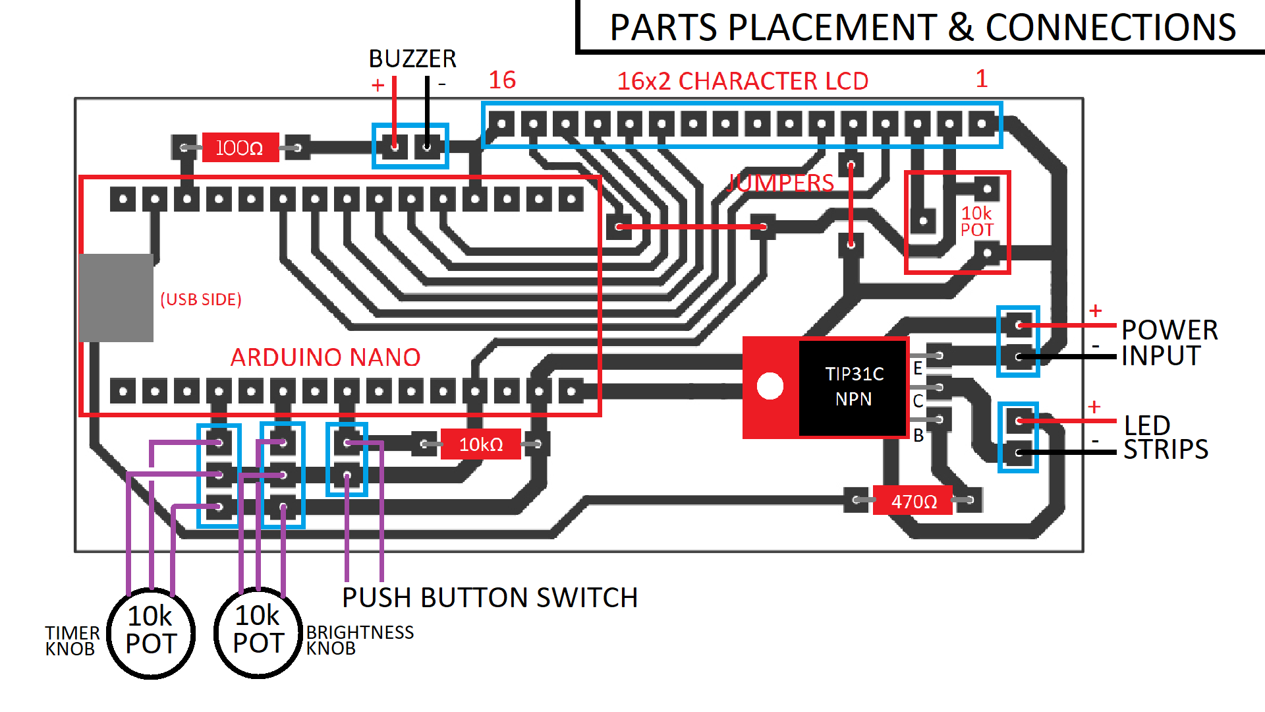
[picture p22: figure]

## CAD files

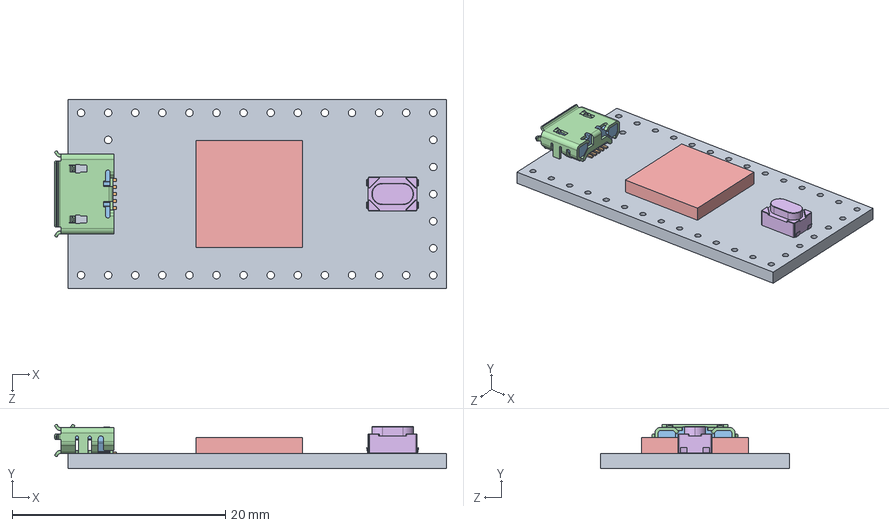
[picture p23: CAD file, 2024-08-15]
Research and Development/Interface Section/AFPI/Enclosure Design/3D Models/Teensy 4.0/Teensy_4.0_Assembly.STEP
36.8 x 4.12 x 17.7 mm
Teensy_4.0_PCB
Micro USB-B Female 5Pin SMD
NXP iMXRT1062
SKRPACE010 v4

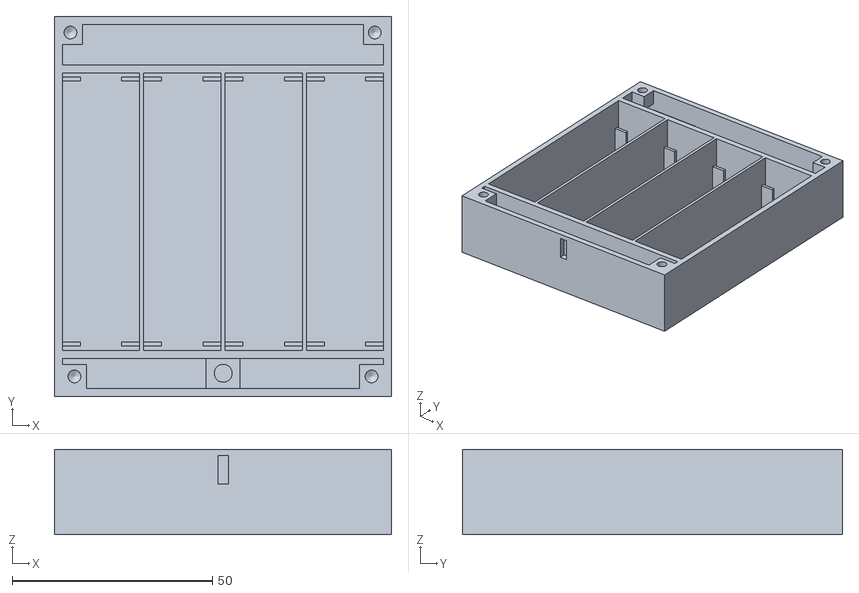
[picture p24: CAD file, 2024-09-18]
Research and Development/BMS/FInal Battery Design/battery design stl files/Tests/main body test.stl
84.2 x 94.9 x 21.3

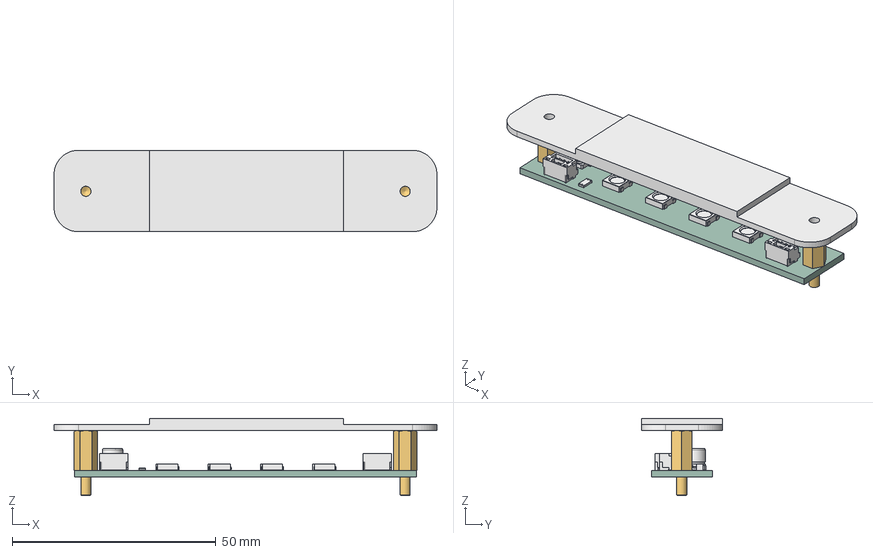
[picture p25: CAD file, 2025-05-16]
Research and Development/Interface Section/RGB Lighting comps/Lighting board and cover Plate assembly.FCStd
94.0 x 20.0 x 19.0 mm
_autosave-RGB LED Mounting Board PCB003
M2.5_MF_TORRETTA
M2.5_MF_TORRETTA001

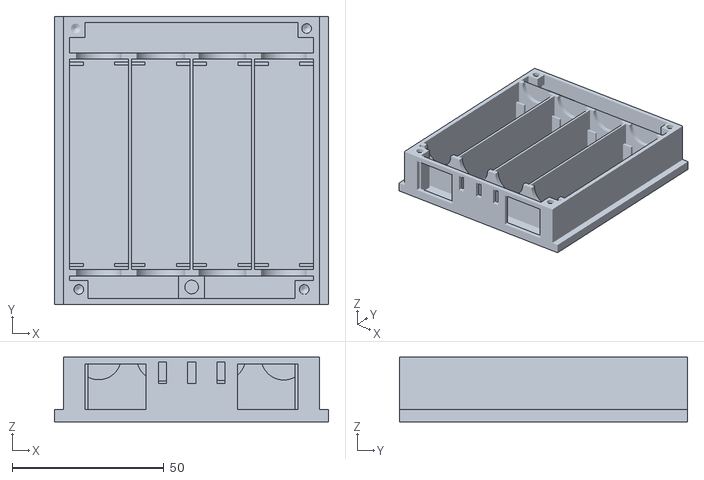
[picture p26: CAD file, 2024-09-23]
Research and Development/BMS/FInal Battery Design/battery design stl files/Battery v1.1/Final Battery Design v1.1-Batterymain enclosure.stl
90.2 x 94.9 x 21.3

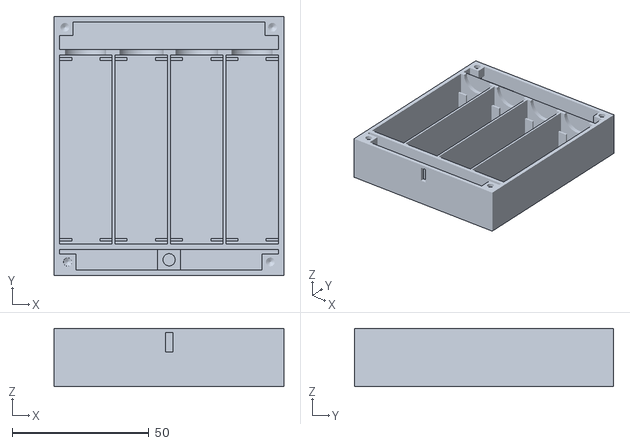
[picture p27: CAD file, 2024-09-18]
Research and Development/BMS/FInal Battery Design/battery design stl files/Tests/main body test 2.stl
84.2 x 94.9 x 21.3

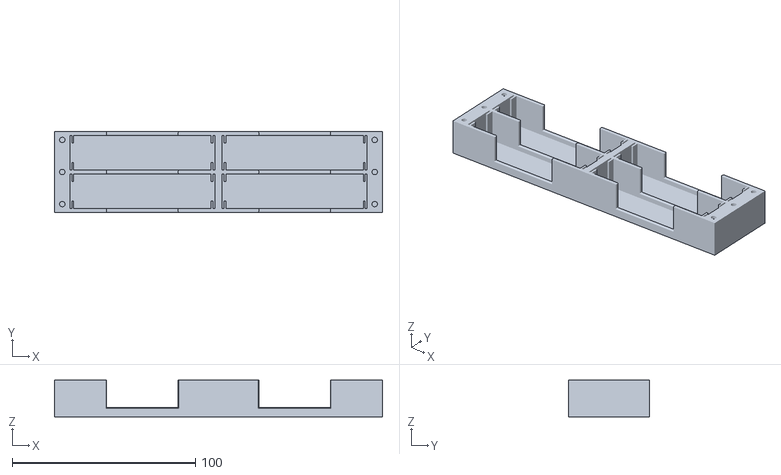
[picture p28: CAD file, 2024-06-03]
Research and Development/BMS/enclosure modelling/Battery Cell Mount Designs - not-utilised-Anymore/Battery holder initial designing/First base layer print attempt.stl
179.0 x 44.0 x 20.0

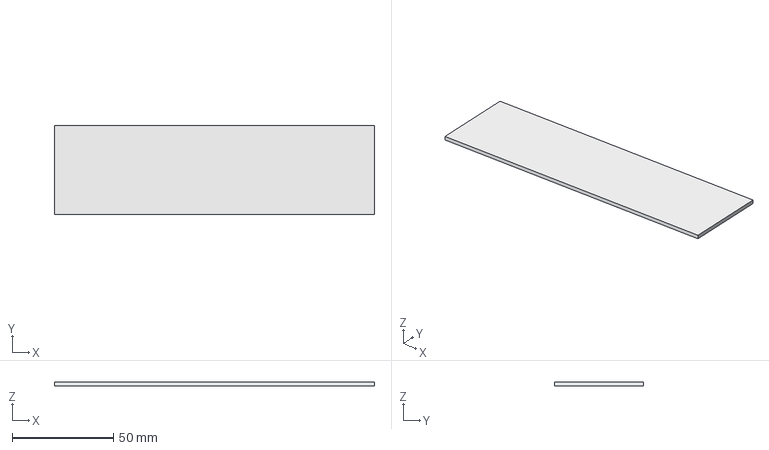
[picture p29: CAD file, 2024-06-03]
Research and Development/BMS/enclosure modelling/Battery Cell Mount Designs - not-utilised-Anymore/design attempt 1/design attempt 1.1.FCStd
158.0 x 44.0 x 2.00 mm

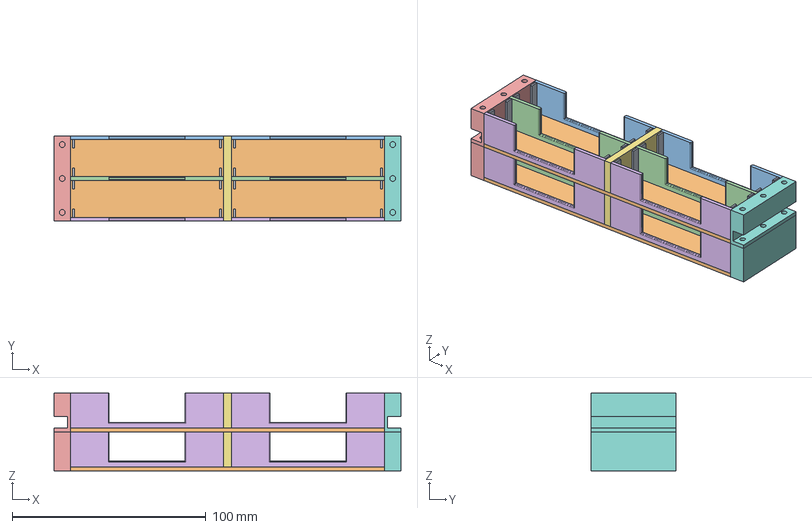
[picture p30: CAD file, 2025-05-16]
Research and Development/BMS/enclosure modelling/Battery Cell Mount Designs - not-utilised-Anymore/Design attempt 2 - final/battery design.FCStd
179.0 x 44.0 x 40.0 mm
Terminal walls
BASE
back row
middle row
floor and Sides
front row
central divider
RHS and heat holes
Terminal walls001
BASE001
back row001
middle row001
floor and Sides001
front row001
central divider001
RHS and heat holes001

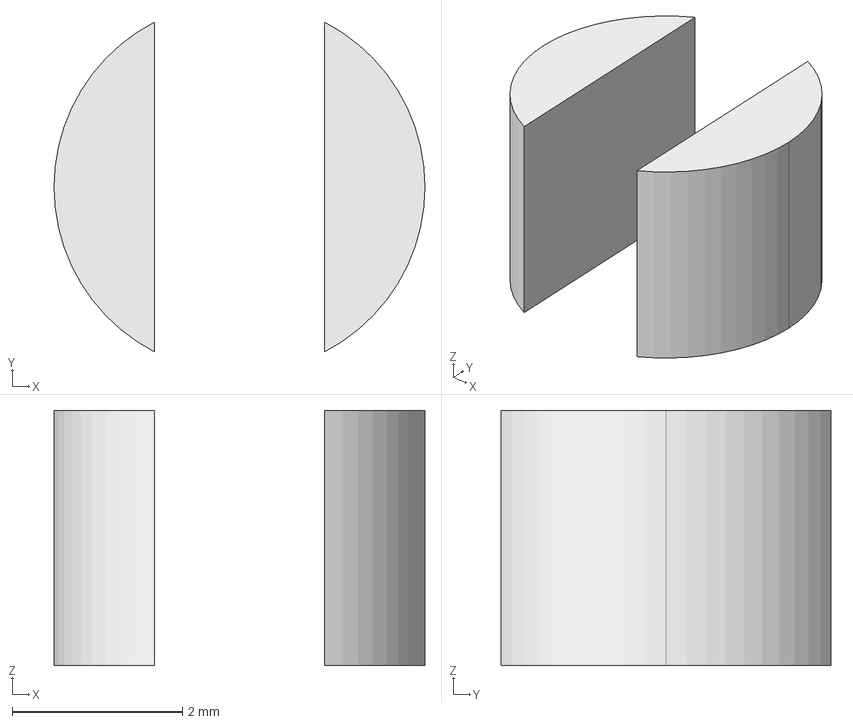
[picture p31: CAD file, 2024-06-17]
Research and Development/BMS/enclosure modelling/rocker switch head V2.FCStd
4.36 x 3.87 x 3.00 mm

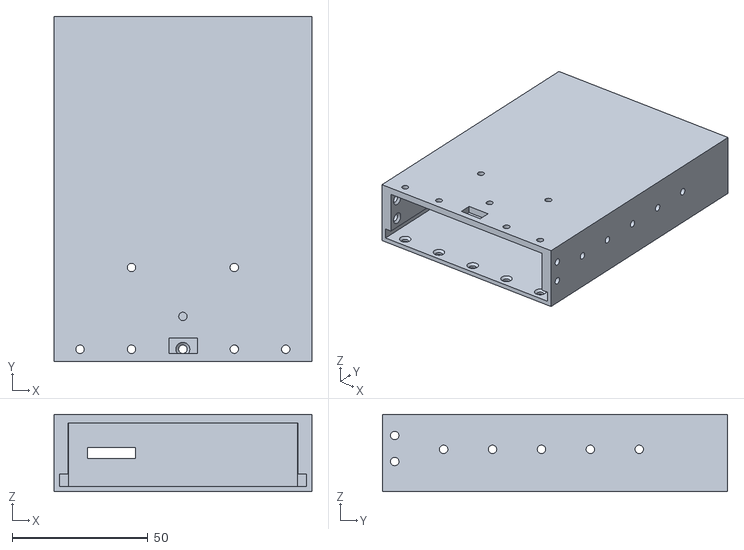
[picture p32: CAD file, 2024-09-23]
Research and Development/BMS/FInal Battery Design/battery design stl files/Batt Sleeve v1/batt guitar internal sleeve v1.stl
94.8 x 127.0 x 28.5

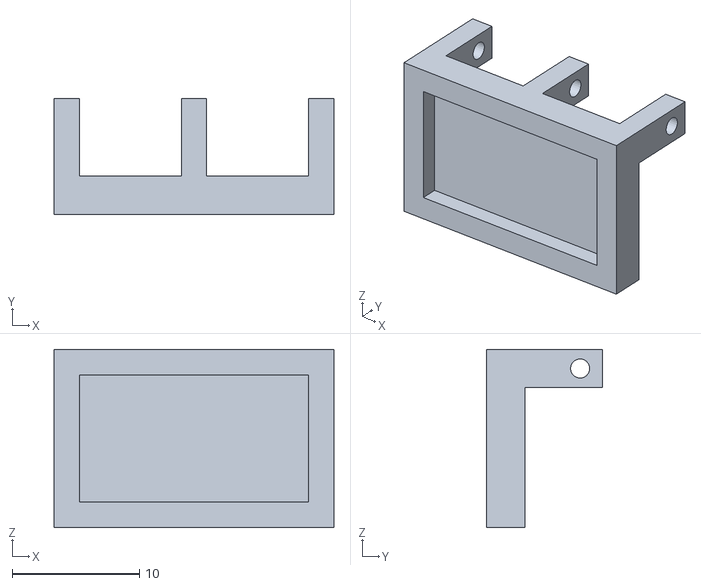
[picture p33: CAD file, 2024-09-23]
Research and Development/BMS/FInal Battery Design/battery design stl files/Battery v1.1/handle lock.stl
22.0 x 9.10 x 14.0

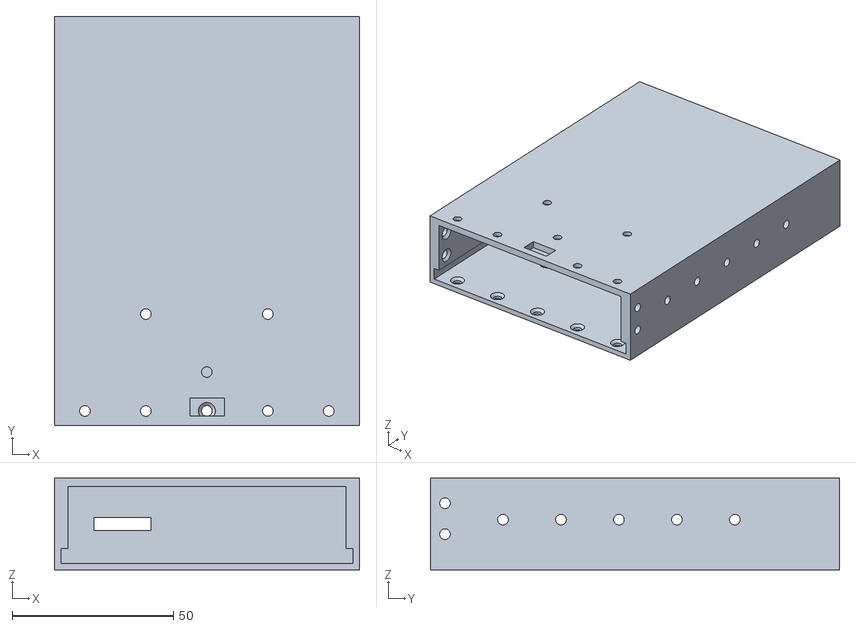
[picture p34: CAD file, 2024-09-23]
Research and Development/BMS/FInal Battery Design/battery design stl files/sleeve v1.1/batt sleeve v1.1.stl
94.8 x 127.0 x 28.5

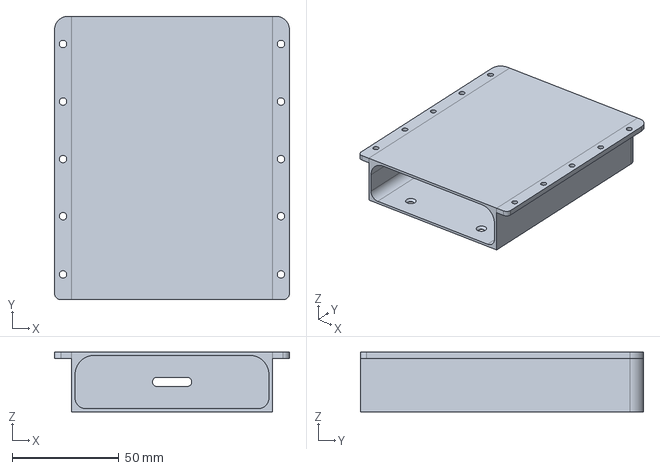
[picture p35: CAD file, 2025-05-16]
Research and Development/BMS/FInal Battery Design/Battery V2.FCStd
110.3 x 133.0 x 28.0 mm

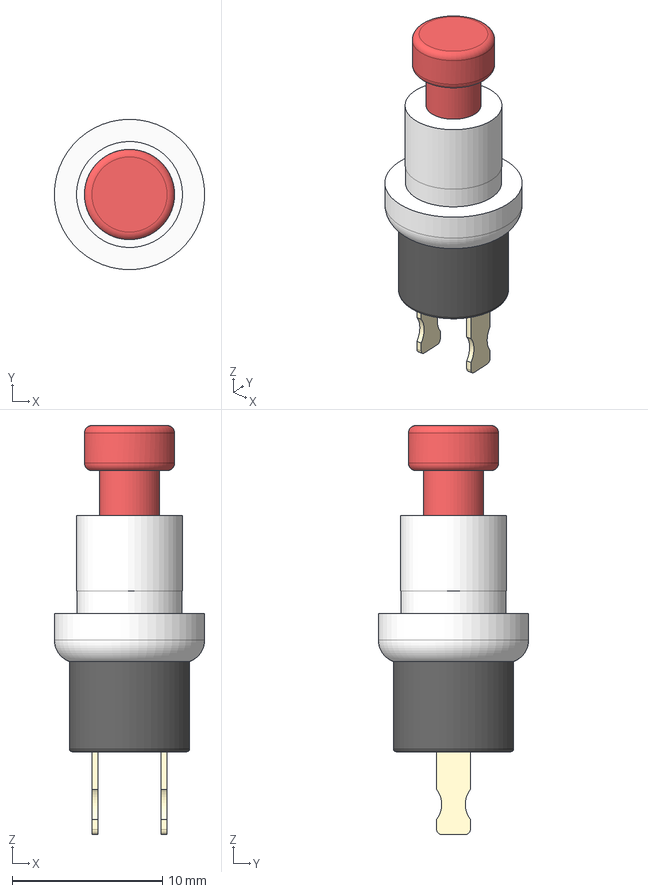
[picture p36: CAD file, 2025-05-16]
Research and Development/Body design/3d models and docs/spst button/Push Button.stp
10.0 x 10.0 x 27.2 mm

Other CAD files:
Research and Development/BMS/FInal Battery Design/battery design stl files/Tests/batt internal sleeve test.stl
Research and Development/BMS/FInal Battery Design/Final Design V2/Battery V2-Battery Sleeve V2Body018.stl
Research and Development/Body design/body and neck scaled 3d models/Expeditioner Model-Body Mk 1.stl
Research and Development/Body design/body Components Tool Paths/Back plate 1 tool path.FCStd
Research and Development/BMS/FInal Battery Design/Final Battery Design-batt sleeve v2sleeve enclosure top plate.step
Research and Development/BMS/FInal Battery Design/Final Battery Design-batt sleeve v2sleeve enclosure top plate.stl
Research and Development/BMS/FInal Battery Design/Final Battery Design-batt sleeve v2sleeve enclosure v2.step
Research and Development/BMS/FInal Battery Design/Final Battery Design-batt sleeve v2sleeve enclosure v2.stl
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

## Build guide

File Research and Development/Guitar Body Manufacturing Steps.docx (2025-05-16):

# Guitar Body Manufacturing Steps

# 1.0 Cut Rough Body Shape

1. Wood Slab Cut it to 600x450mm with 45mm thickness
2. Place Jig 2 over body and trace out shape
3. Use Band Saw to cut out shape
4. Sand any major irregularities on body edge

# 2.0 Jig 1

1. Clamp Down Jig 1 onto Body Blank and prepare router, its bits and chisels, ensure chisels are sharpened. Readjust clamps when necessary ensuring continuity of Jig Placement
2. Route Out Neck Pocket 20mm deep
3. Route out AFPI mounting Lip Pocket 5mm deep
4. Use chisel to finish corners of the mounting lip
5. Route out Pickups main pocket 24mm deep
6. Route Out RGB Board Cover Plate Pocket 1.5mm Deep
7. Route Out Tremelo Top Side 6mm deep
8. Route Out speaker Grille lip 2mm Deep
9. Route Out Control Cavity 36mm Deep

# 3.0 Jig 2

1. Clamp Down Jig 2 after Jig 1 is completed, ensuring the jig holes line up as they should
2. Route out pickup wire holes 25mm deep
3. Route out speaker mounting plate Pocket 3mm Deep
4. Route out control cavity plate mounting lip pocket 3mm Deep
5. Route RGB board Pocket Hole 22mm Deep
6. Route out AFPI main Pocket Through the other side
7. Use chisel to clean up corners of AFPI pocket

# 4.0 Jig 3

1. Clamp Down Jig 3 on the underside after Jig 2 is completed.
2. Route exterior edges of neck pocket to fit jig.
3. Drill neck pocket holes
4. Route Battery Plate pocket 3mm depth
5. Route Speaker Magnet Hole through
6. Route Pickup wire channel 20mm deep
7. Route Tremolo underside 39mm deep

# 5.0 Jig 4

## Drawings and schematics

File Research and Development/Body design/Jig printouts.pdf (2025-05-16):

Document Name: Expeditioner_Model

Page / Isometric View
Page001 / Front Back View
Page002 / Page002
Page003 / Page003
Page004 / Page004

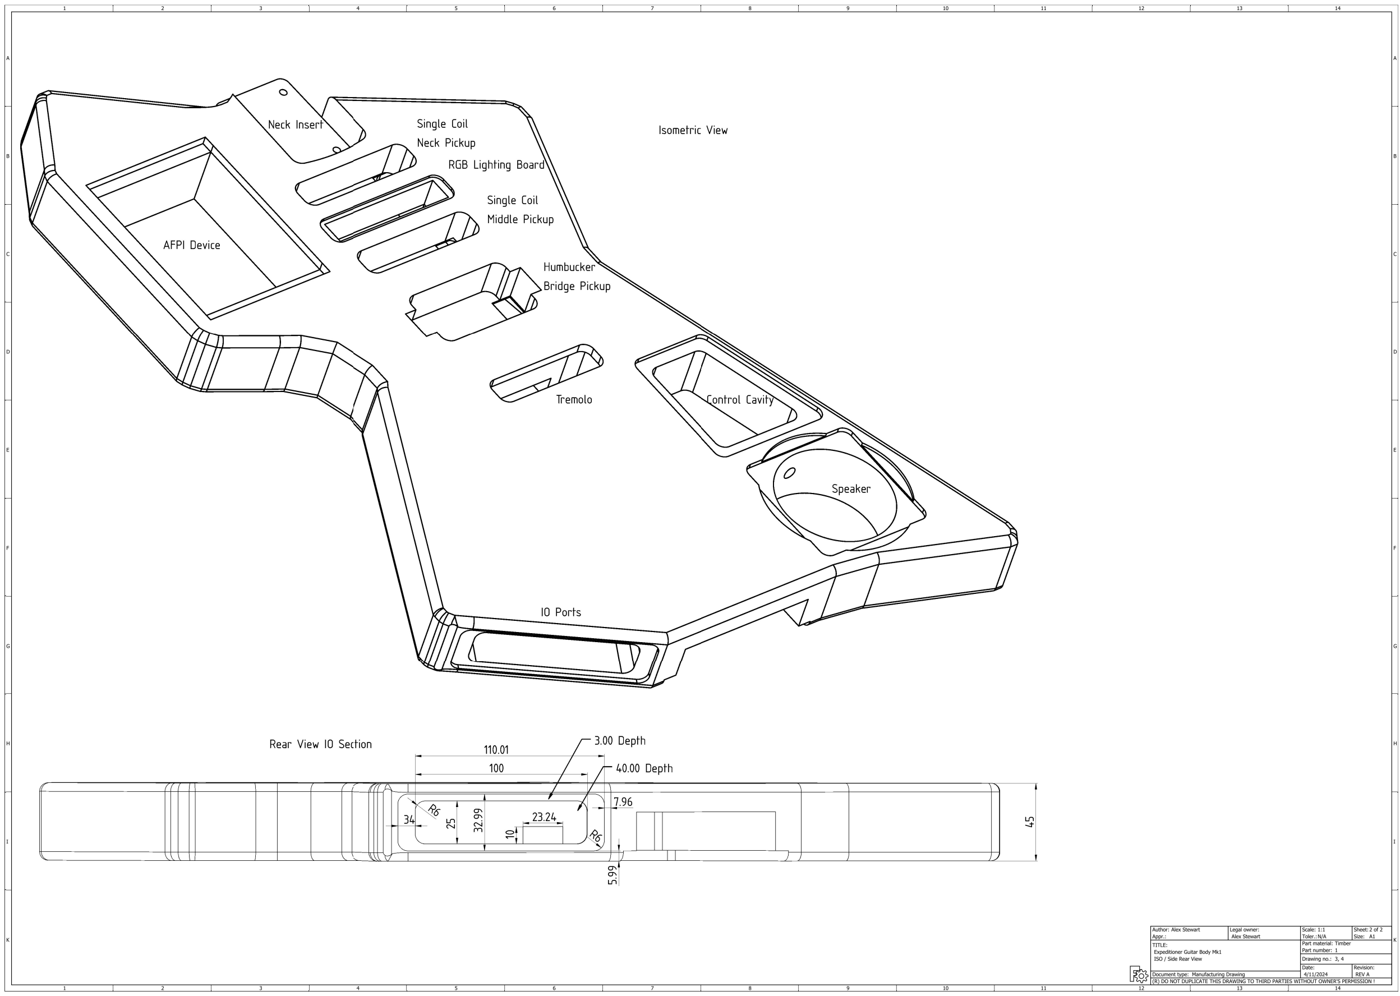
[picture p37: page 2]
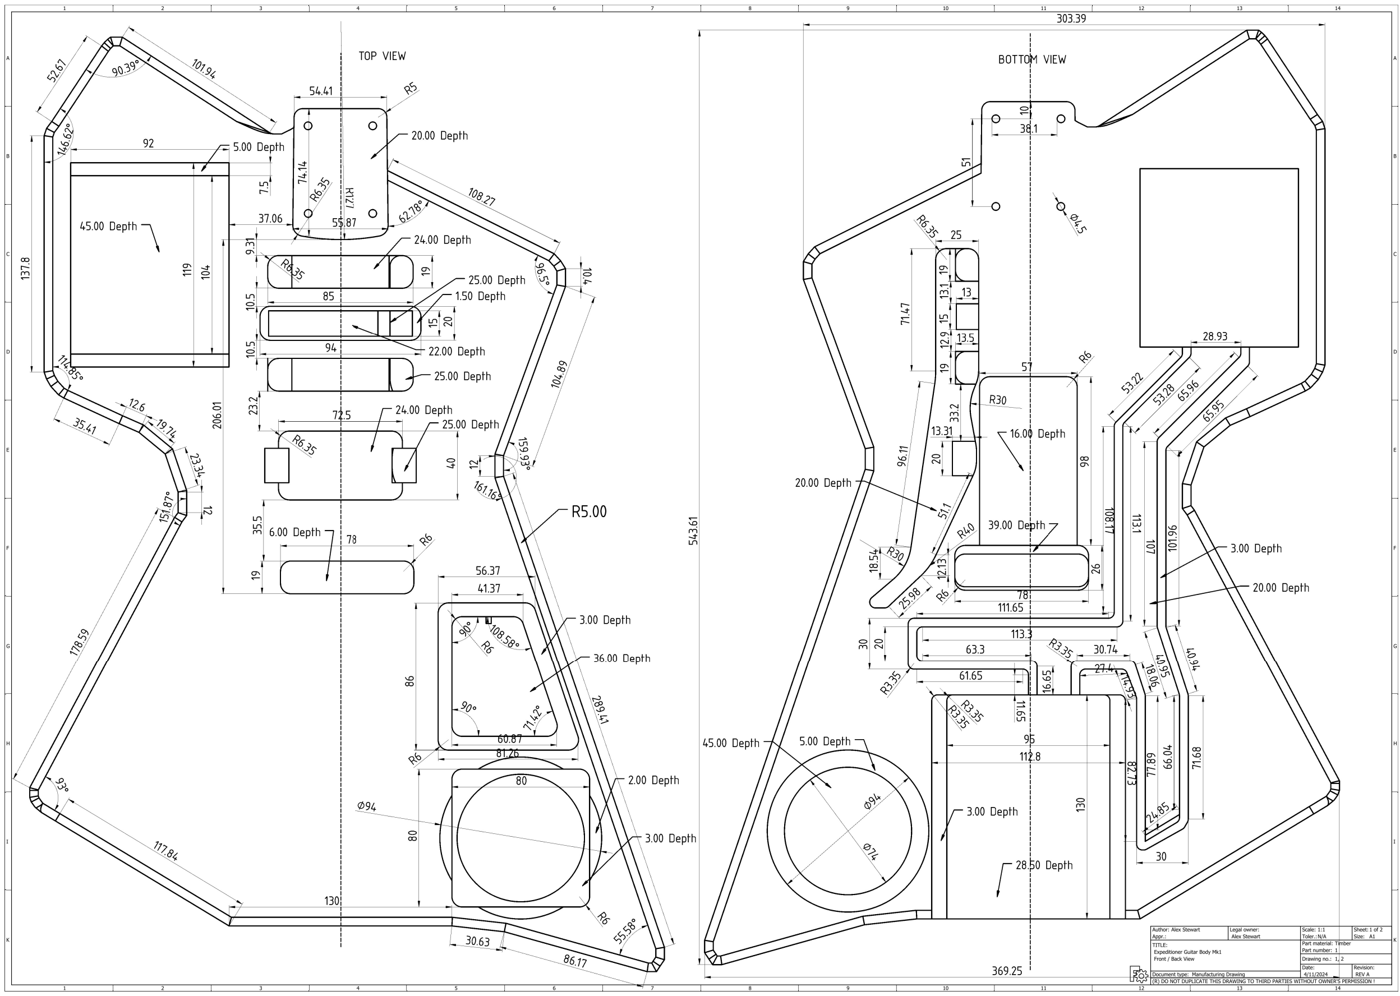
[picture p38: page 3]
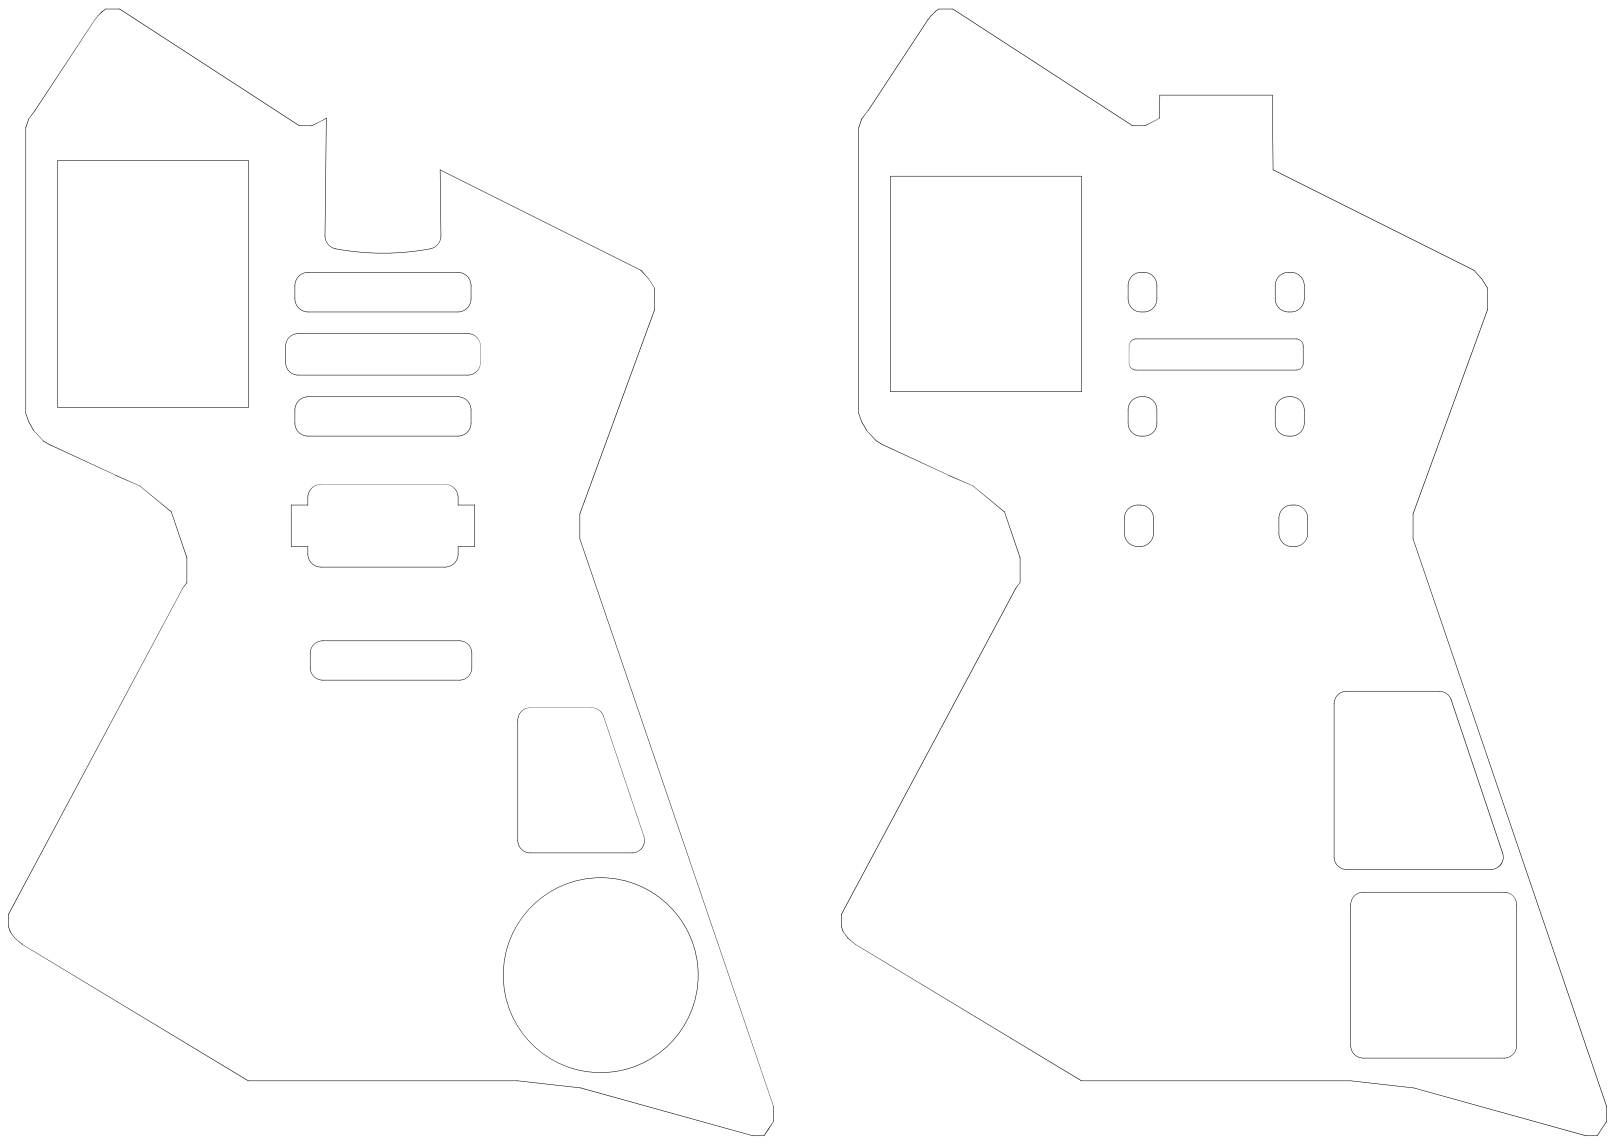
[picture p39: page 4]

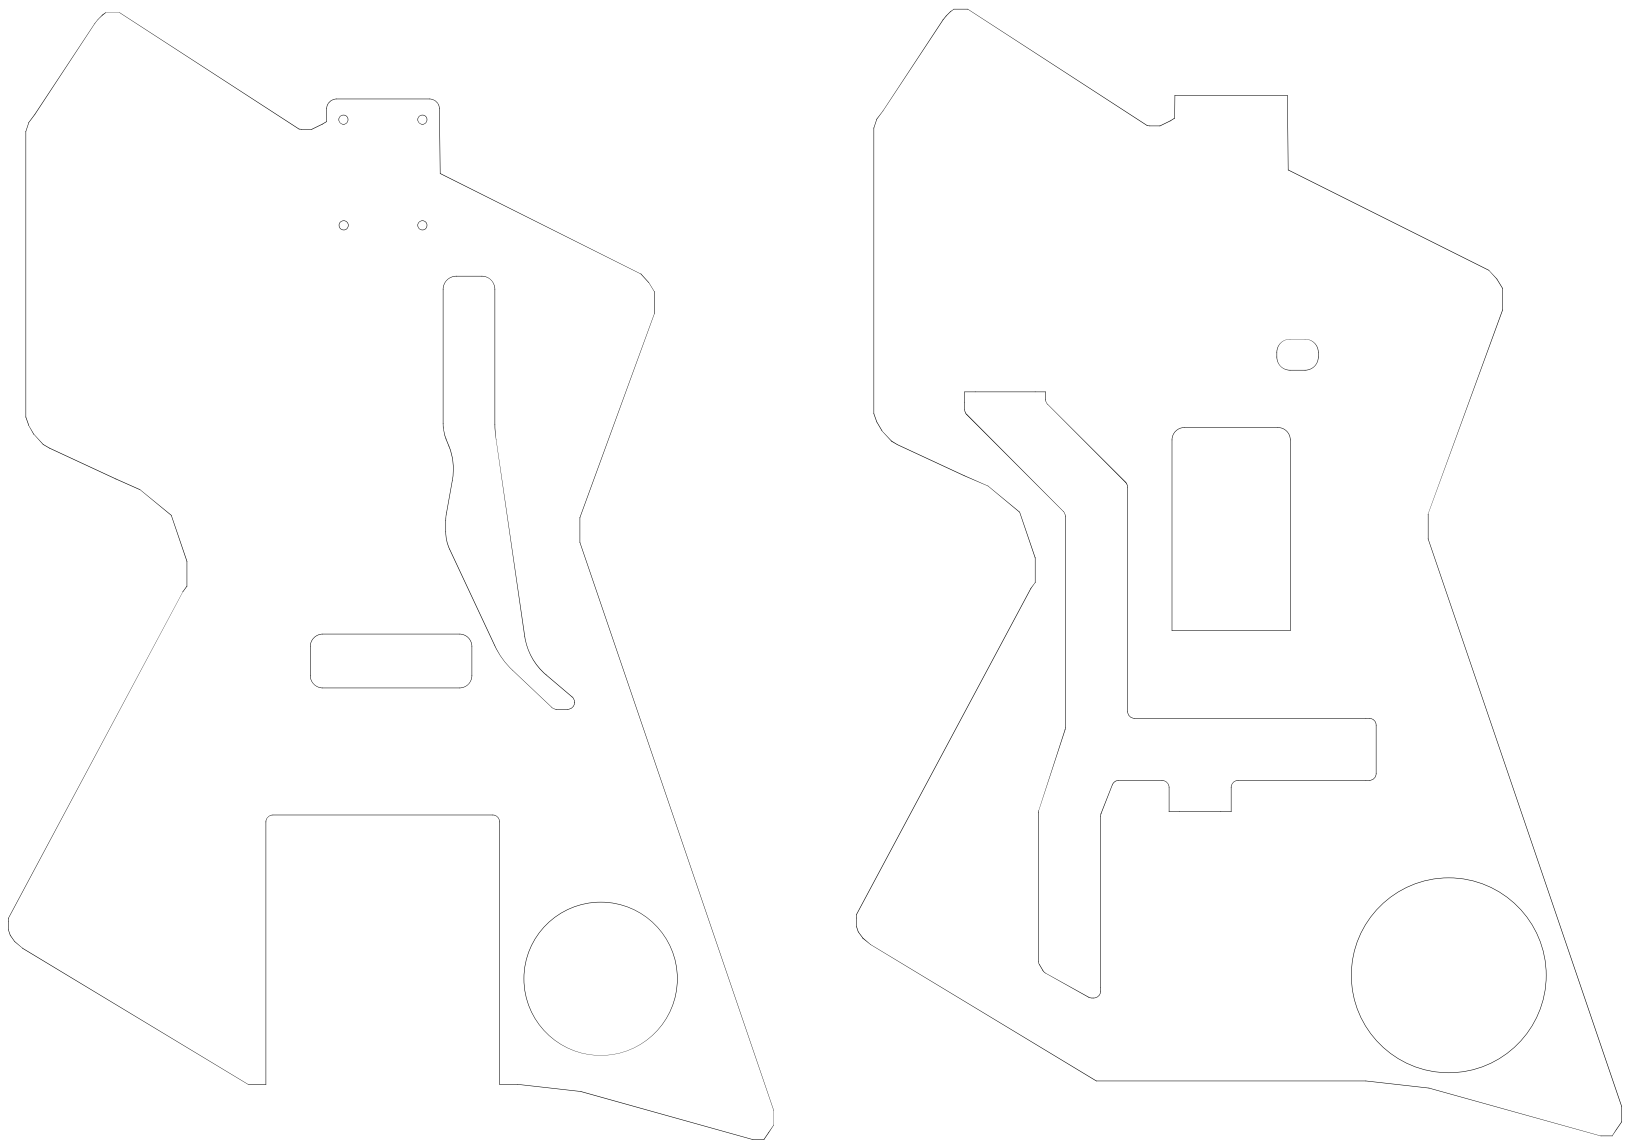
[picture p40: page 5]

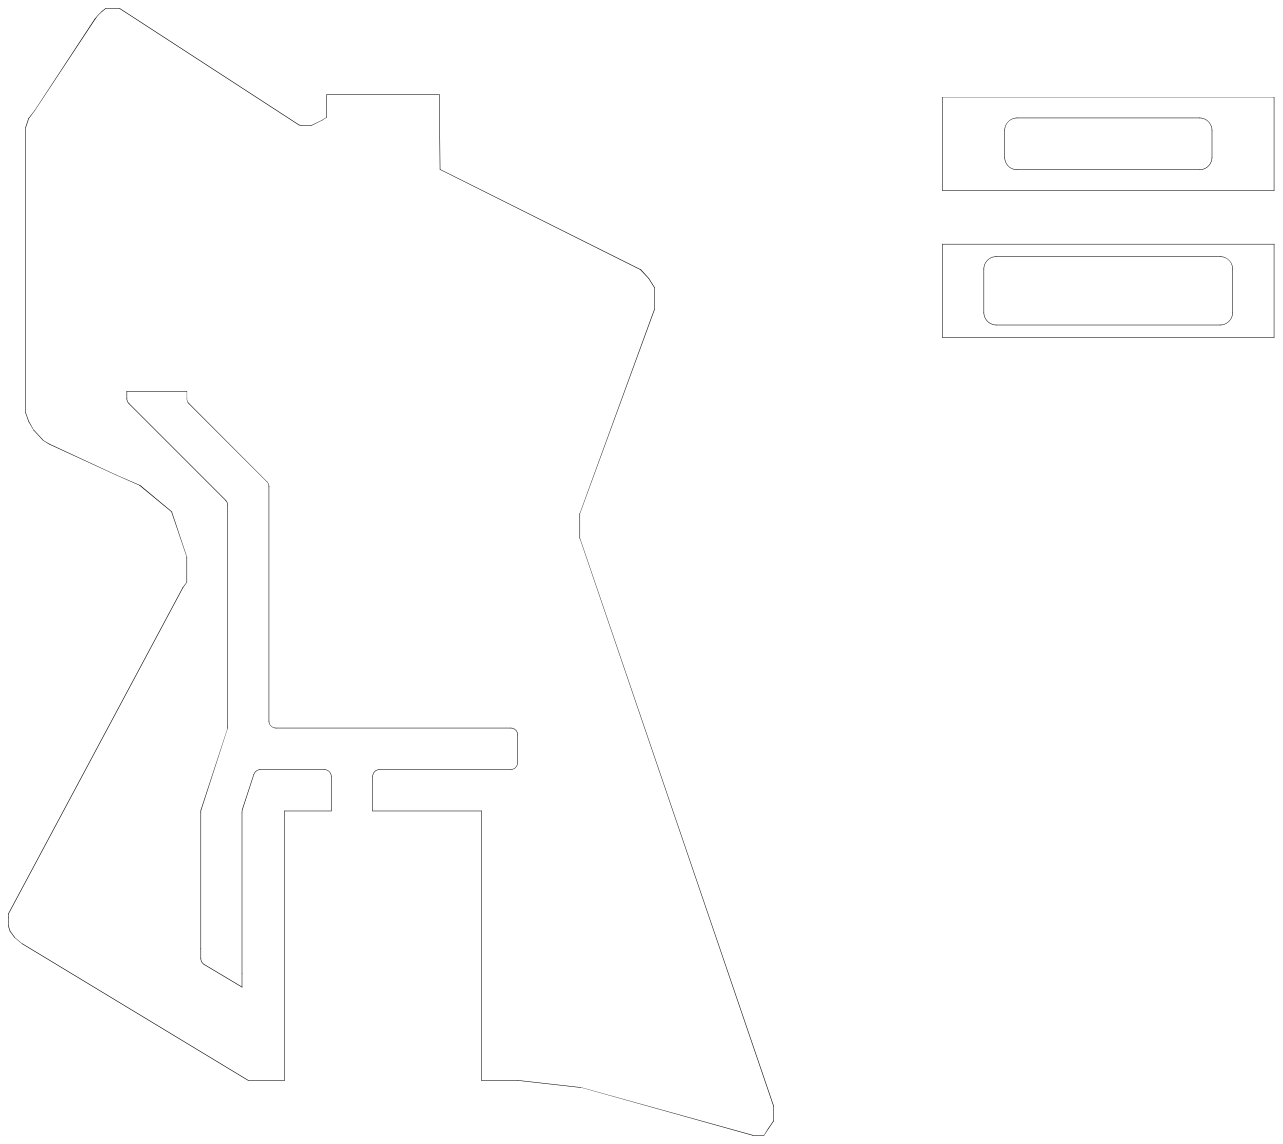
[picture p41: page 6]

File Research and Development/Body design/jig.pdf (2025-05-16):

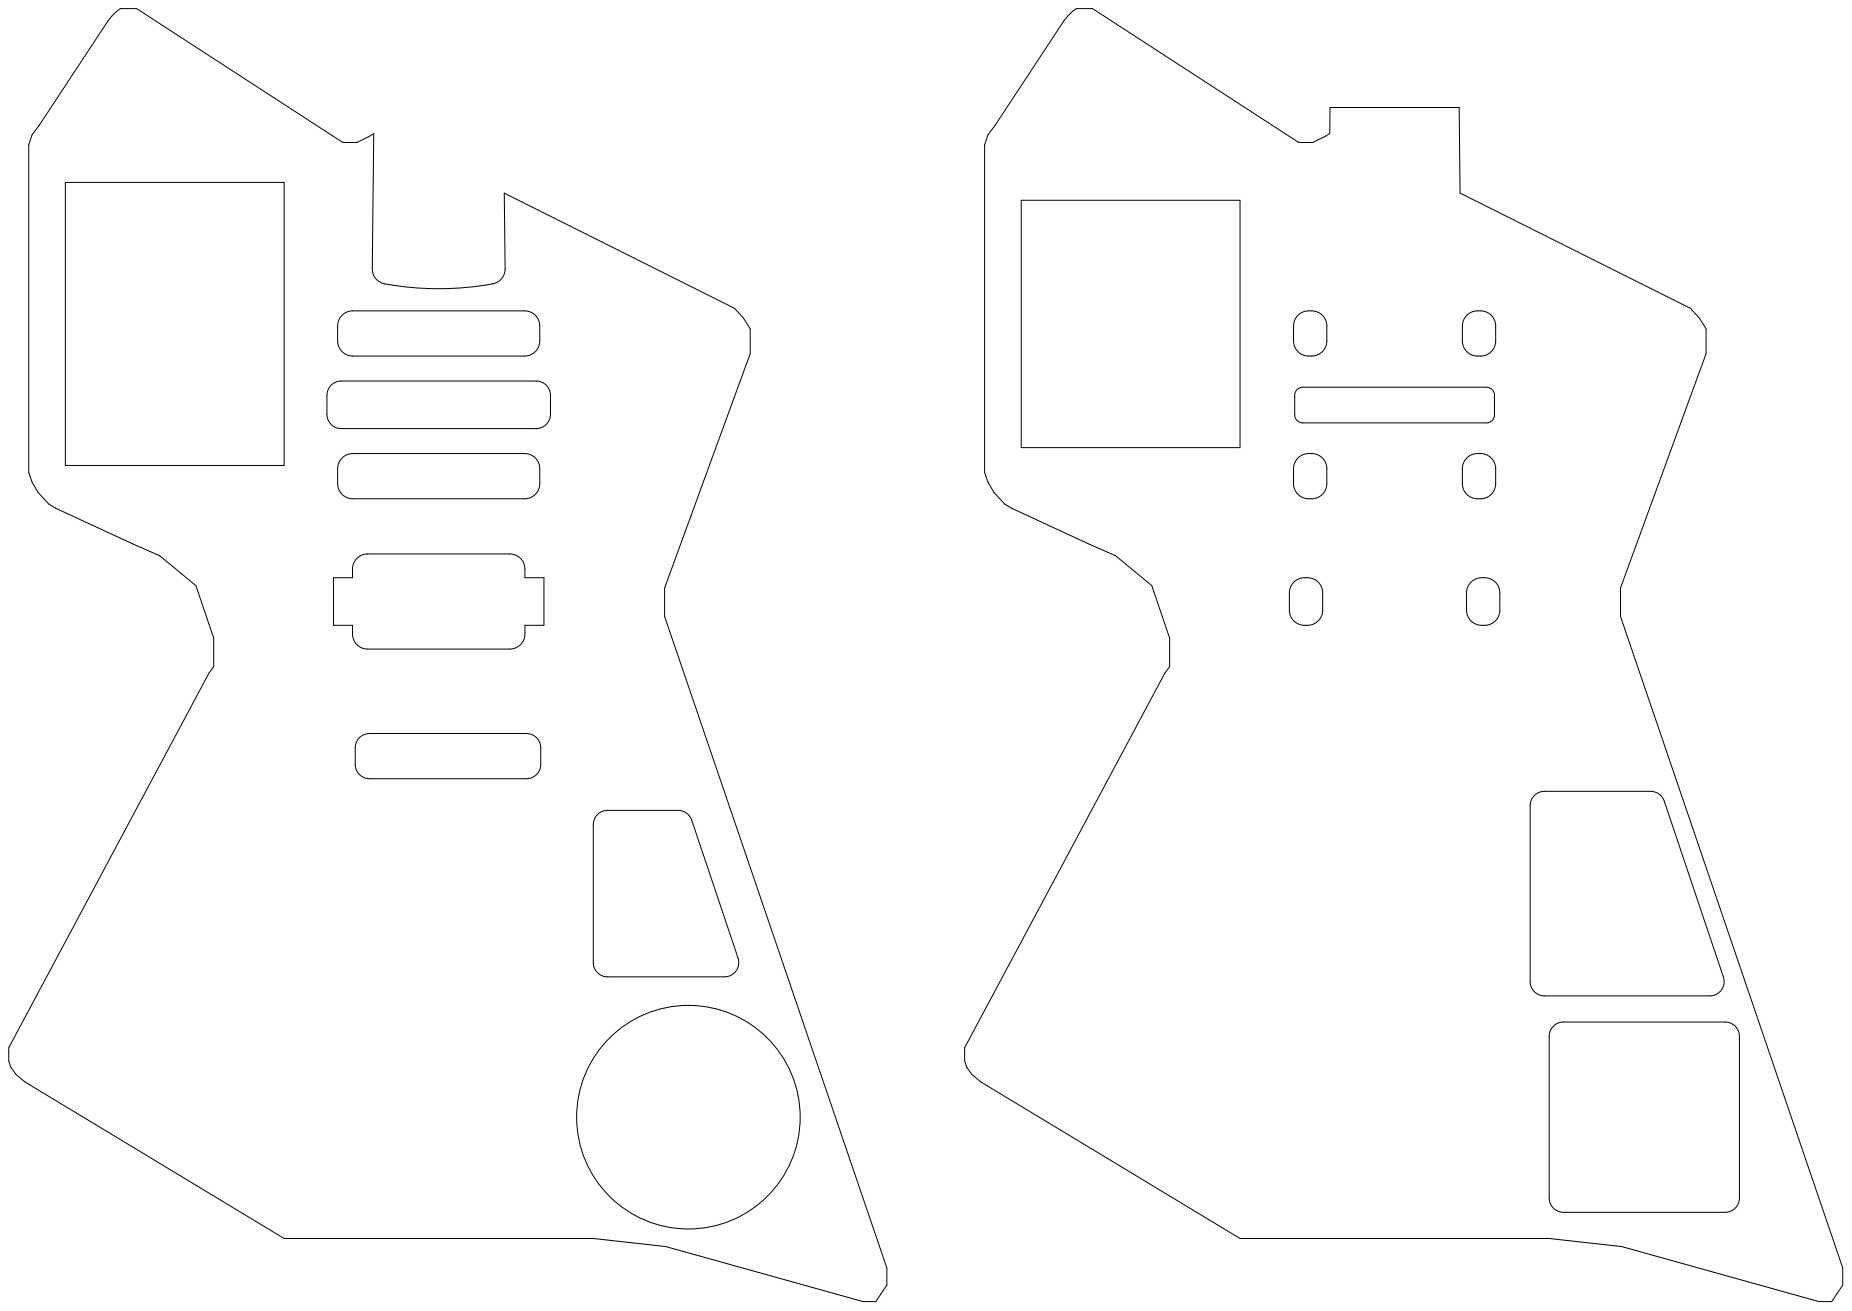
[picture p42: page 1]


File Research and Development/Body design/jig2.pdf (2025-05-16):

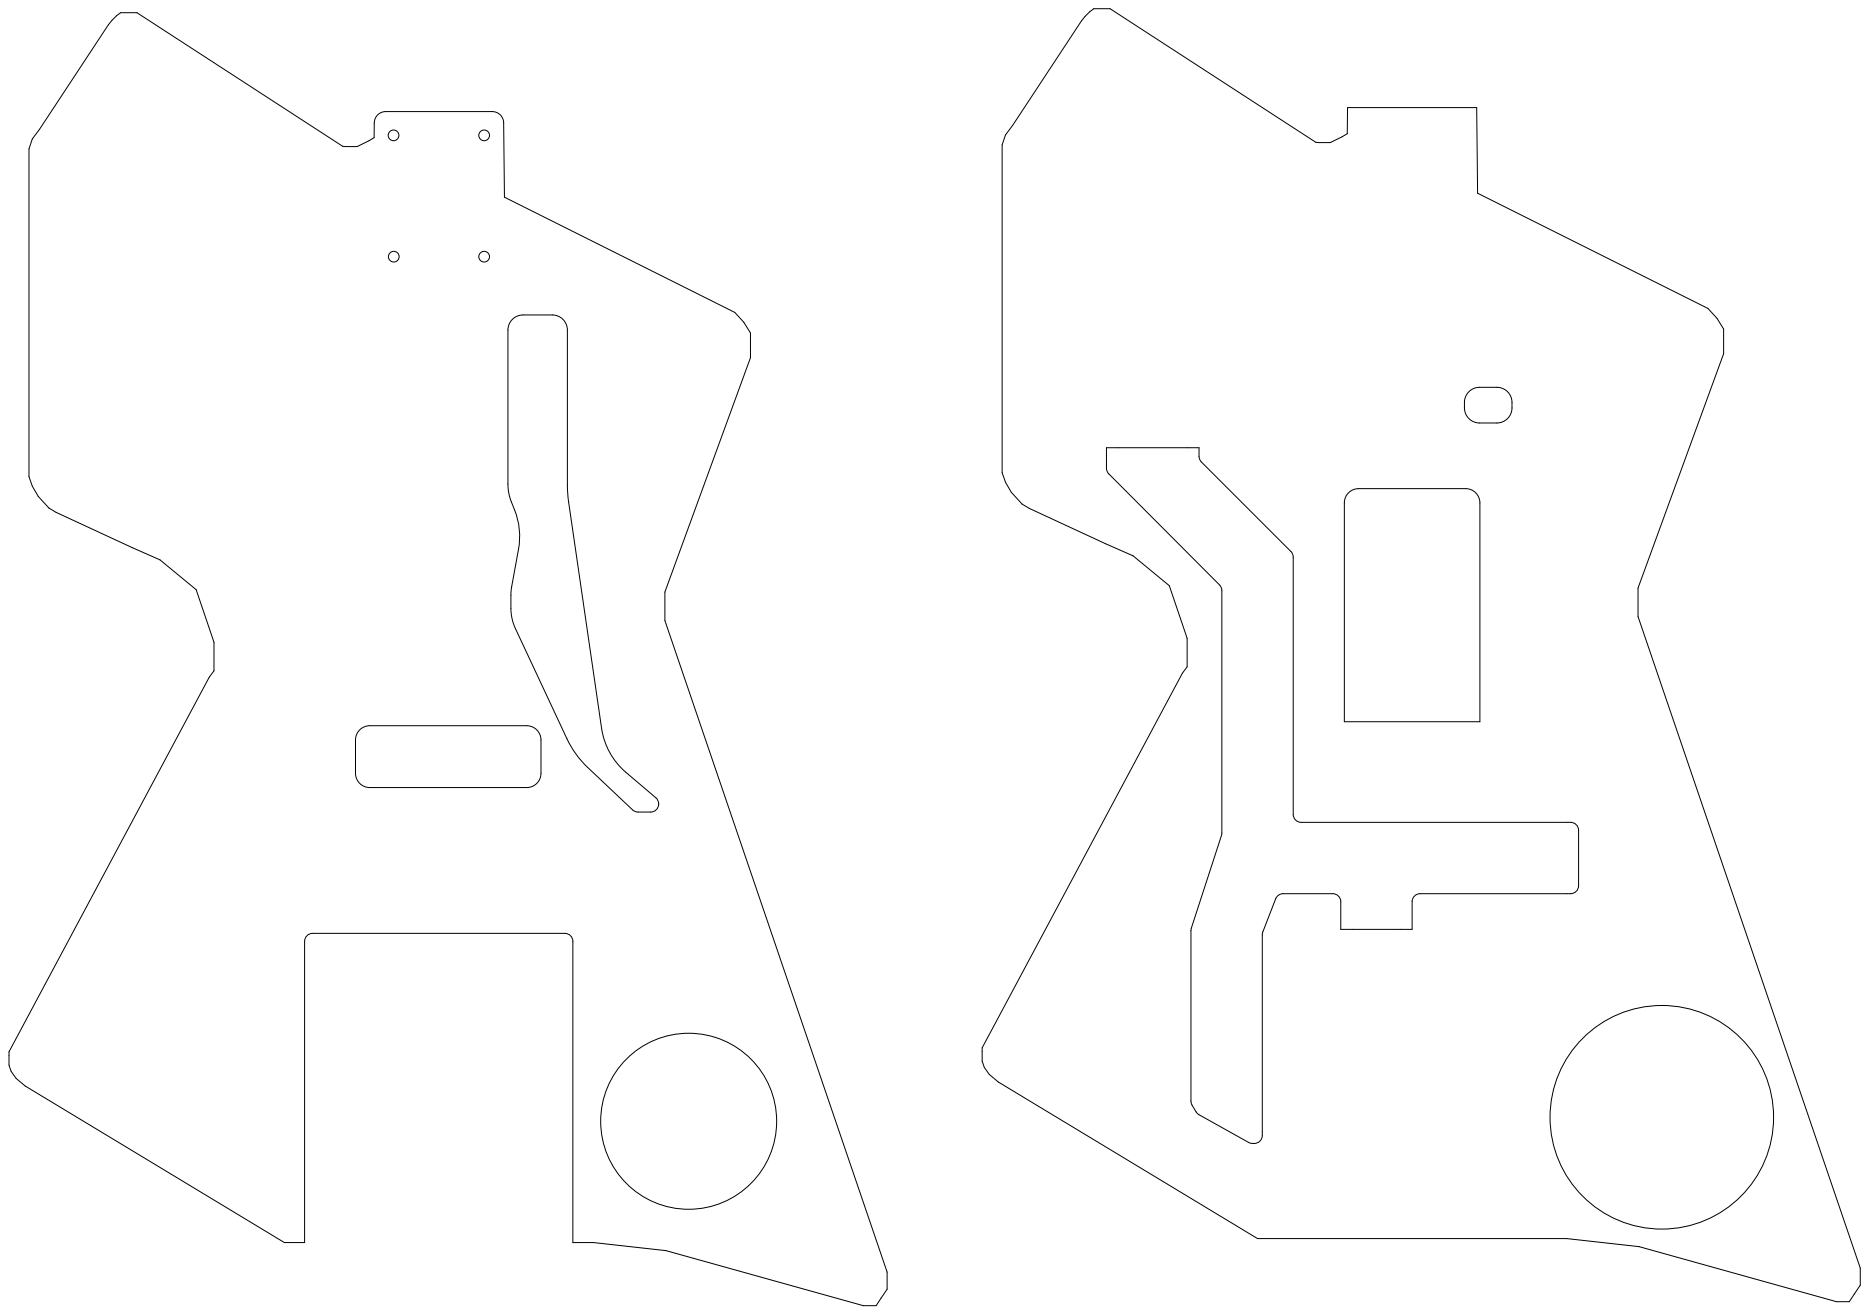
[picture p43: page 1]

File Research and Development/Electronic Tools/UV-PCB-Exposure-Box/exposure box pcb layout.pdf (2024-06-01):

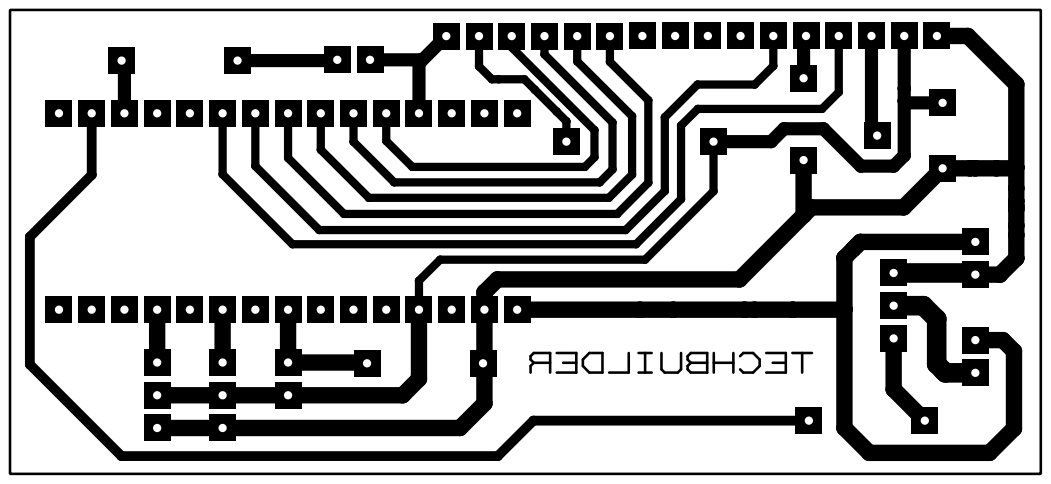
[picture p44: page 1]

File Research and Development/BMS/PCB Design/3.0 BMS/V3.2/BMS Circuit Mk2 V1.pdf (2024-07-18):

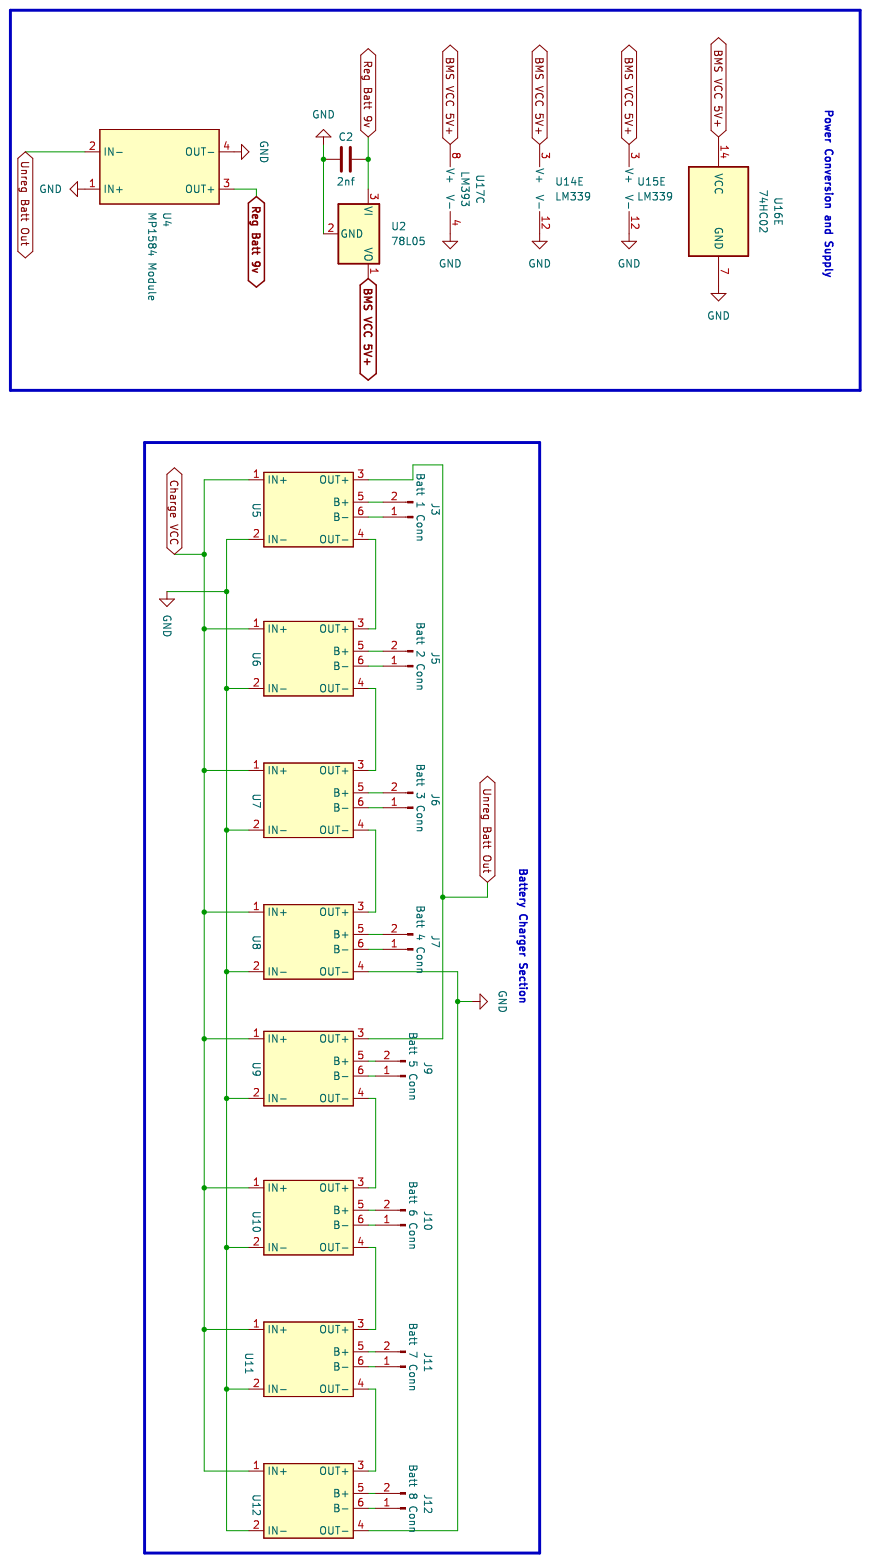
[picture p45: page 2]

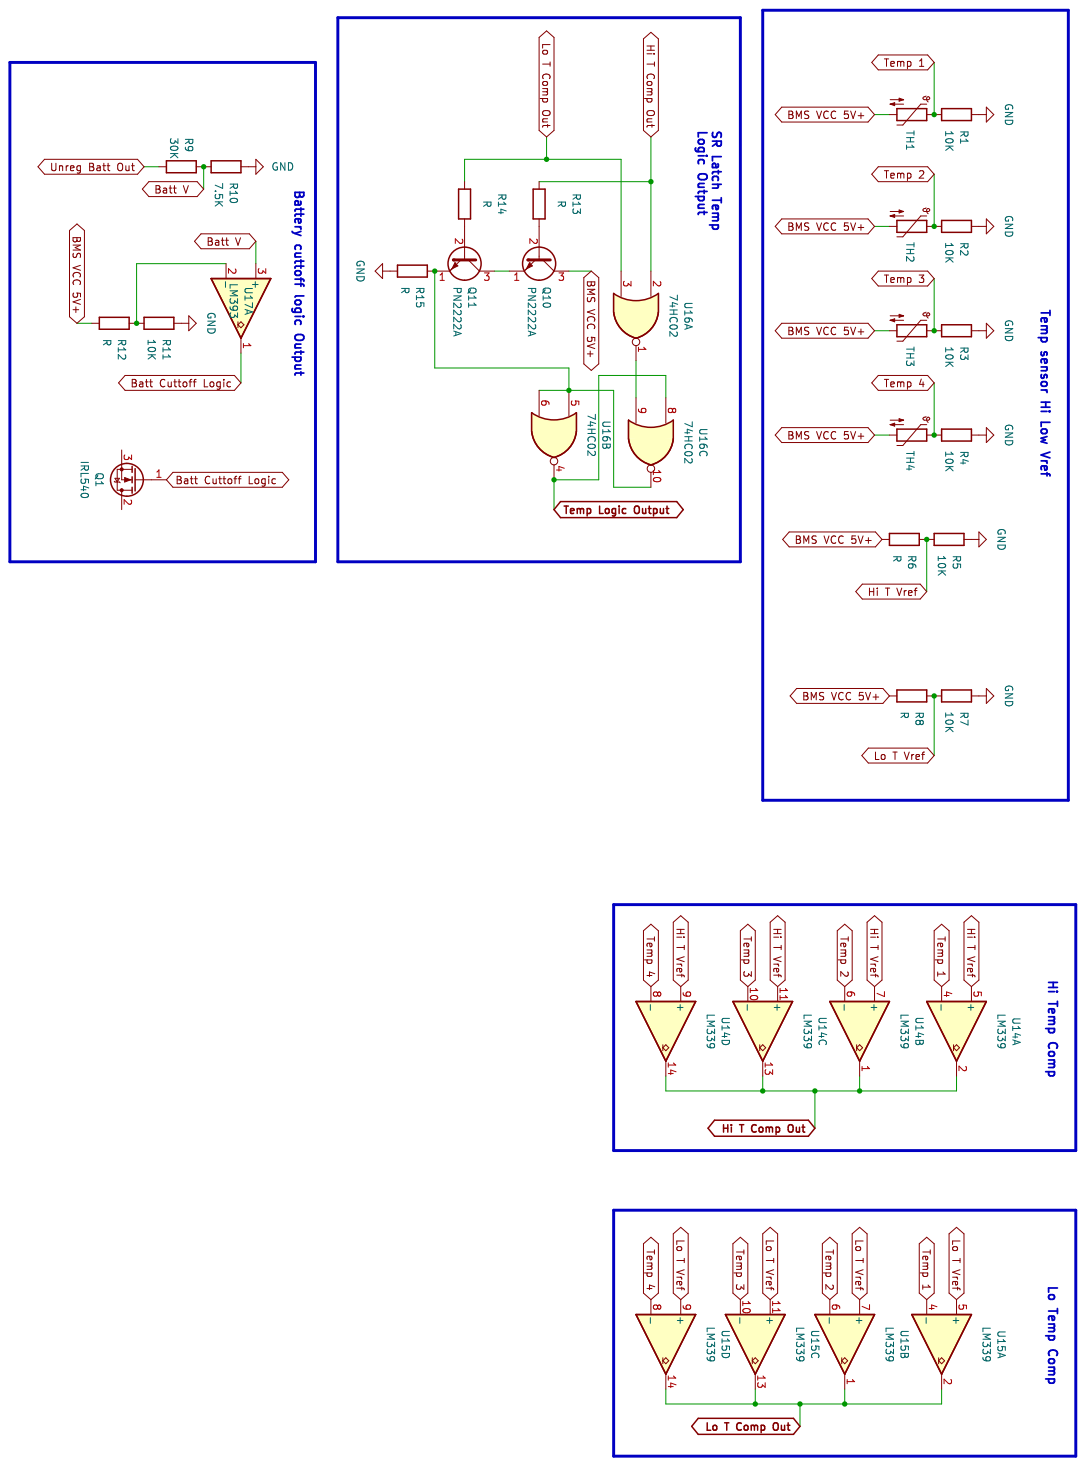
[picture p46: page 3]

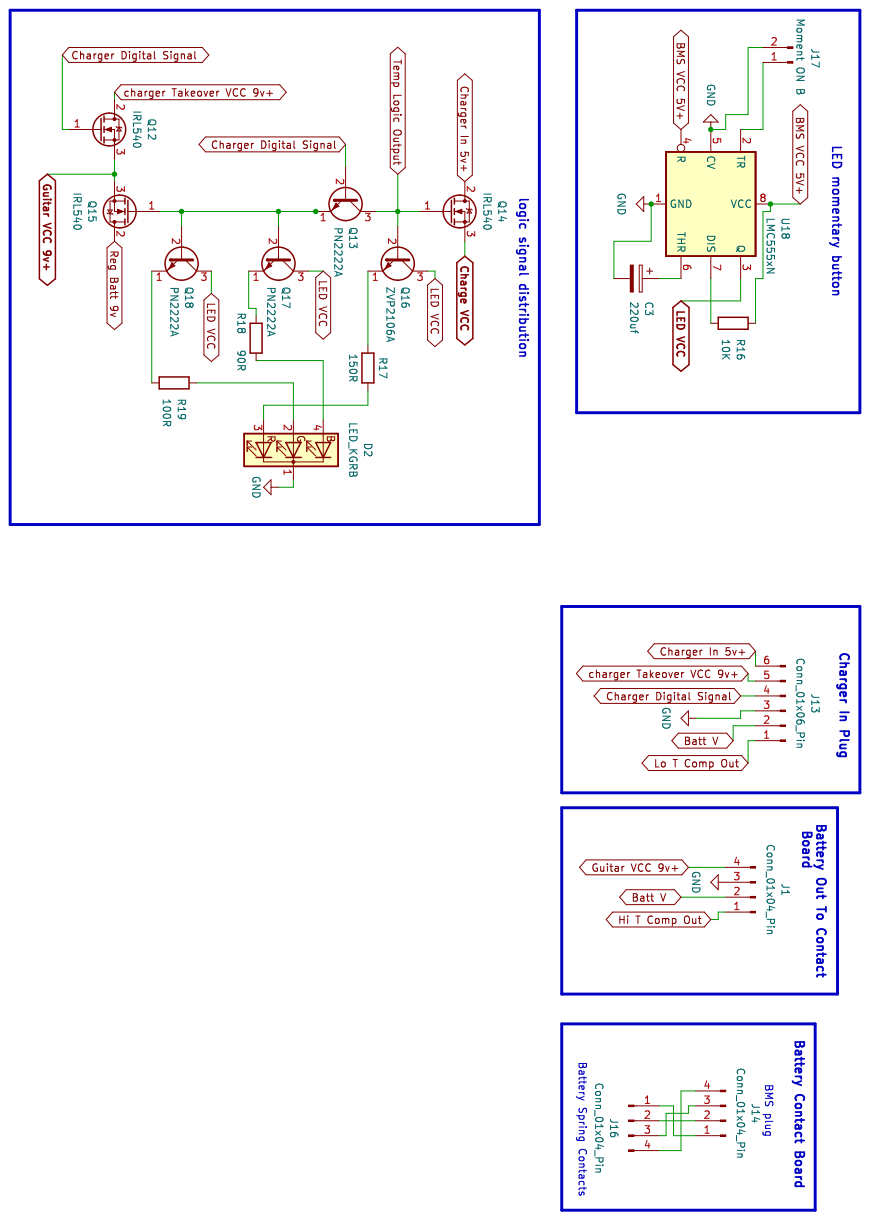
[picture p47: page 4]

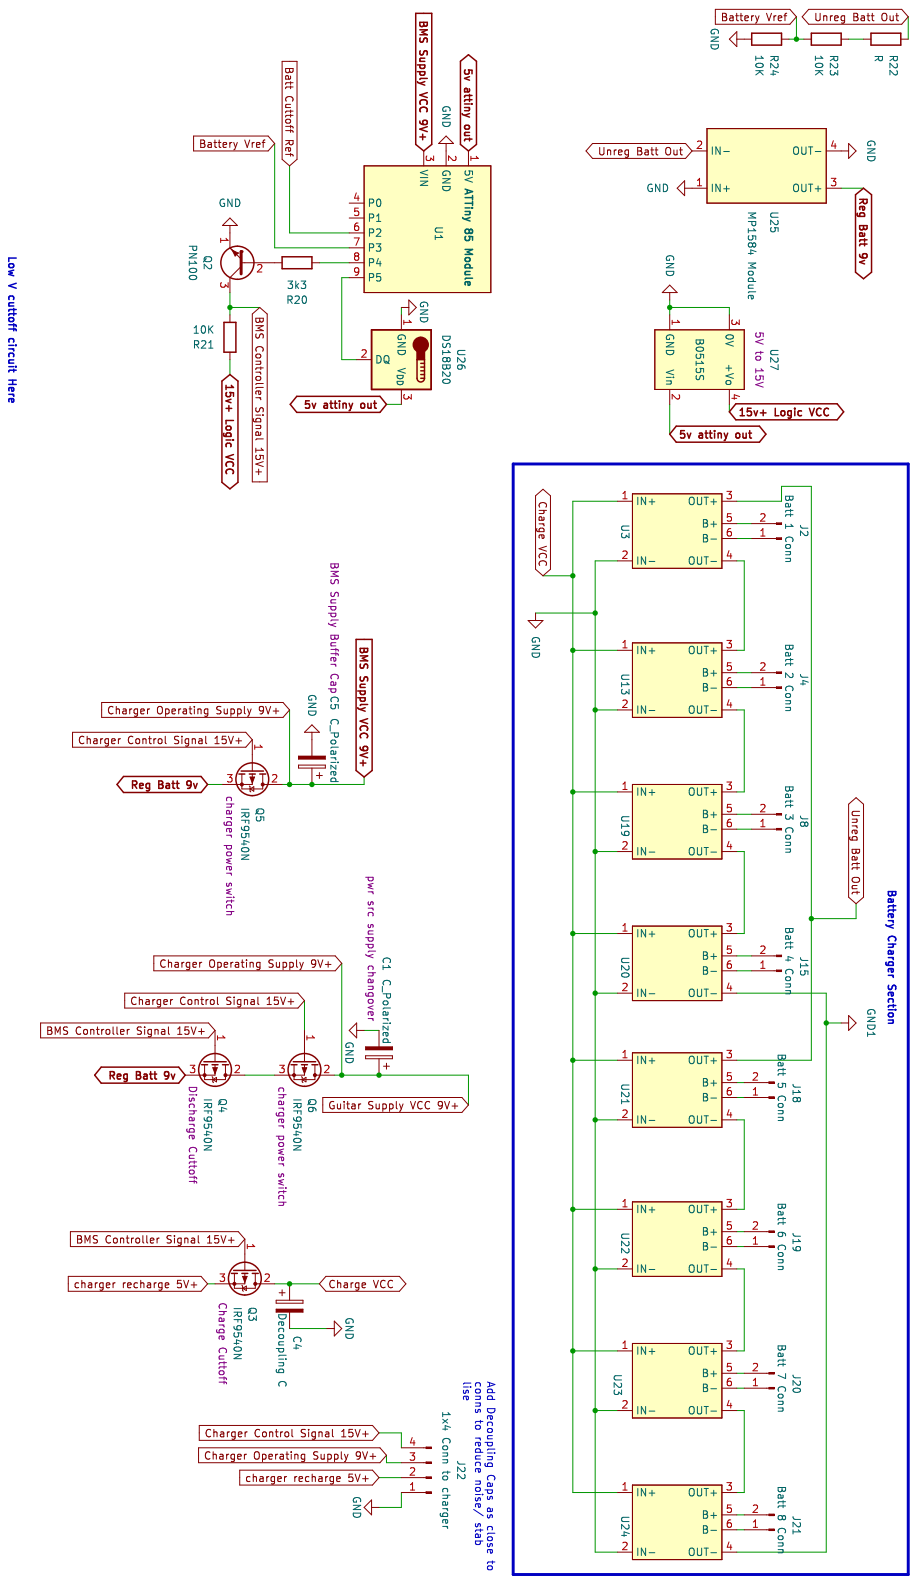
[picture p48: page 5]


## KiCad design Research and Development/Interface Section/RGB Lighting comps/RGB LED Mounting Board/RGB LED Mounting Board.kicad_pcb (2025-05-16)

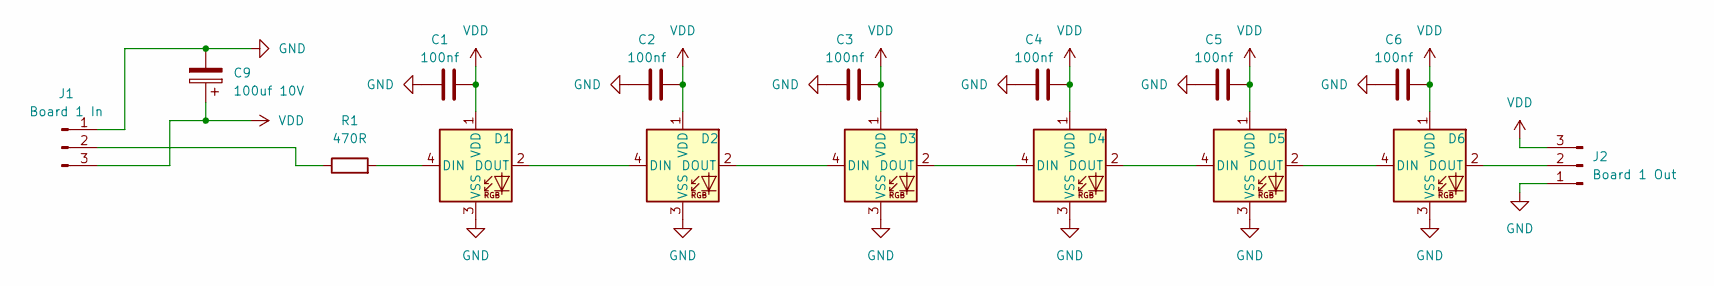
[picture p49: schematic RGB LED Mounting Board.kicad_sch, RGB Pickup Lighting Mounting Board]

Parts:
C1, C2, C3, C4, C5, C6: 100nf; C_1206_3216Metric
C9: 100uf 10V; CP_Elec_5x5.4
D1, D2, D3, D4, D5, D6: WS2812B; LED_WS2812B_PLCC4_5.0x5.0mm_P3.2mm
J1: Board 1 In; JST_GH_BM03B-GHS-TBT_1x03-1MP_P1.25mm_Vertical
J2: Board 1 Out; JST_GH_BM03B-GHS-TBT_1x03-1MP_P1.25mm_Vertical
R1: 470R; R_1206_3216Metric

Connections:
GND: C1.1, C2.1, C3.1, C4.1, C5.1, C6.1, C9.2, D1.3 (VSS), D2.3 (VSS), D3.3 (VSS), D4.3 (VSS), D5.3 (VSS), D6.3 (VSS), J1.1, J2.1
unnamed: D1.4 (DIN), R1.2
unnamed: D1.2 (DOUT), D2.4 (DIN)
unnamed: D2.2 (DOUT), D3.4 (DIN)
unnamed: D3.2 (DOUT), D4.4 (DIN)
unnamed: D4.2 (DOUT), D5.4 (DIN)
unnamed: D5.2 (DOUT), D6.4 (DIN)
unnamed: D6.2 (DOUT), J2.2
unnamed: J1.2, R1.1
VDD: C1.2, C2.2, C3.2, C4.2, C5.2, C6.2, C9.1, D1.1 (VDD), D2.1 (VDD), D3.1 (VDD), D4.1 (VDD), D5.1 (VDD), D6.1 (VDD), J1.3, J2.3

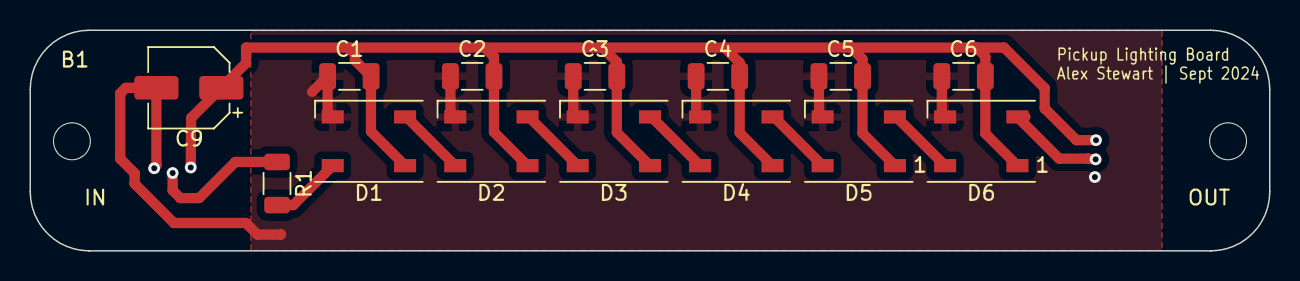
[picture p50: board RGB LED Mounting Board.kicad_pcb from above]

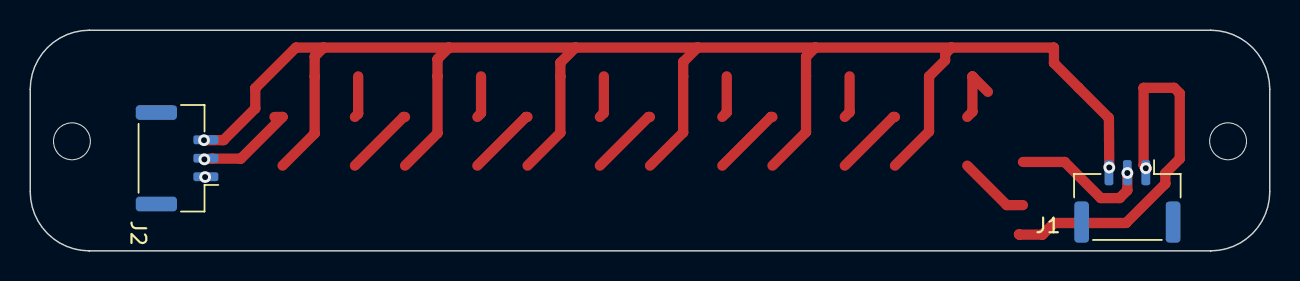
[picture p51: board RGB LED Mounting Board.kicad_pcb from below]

Board: 2 copper layers, 84.0 x 14.9 mm, 16 parts (2 on the bottom side), 10 nets.

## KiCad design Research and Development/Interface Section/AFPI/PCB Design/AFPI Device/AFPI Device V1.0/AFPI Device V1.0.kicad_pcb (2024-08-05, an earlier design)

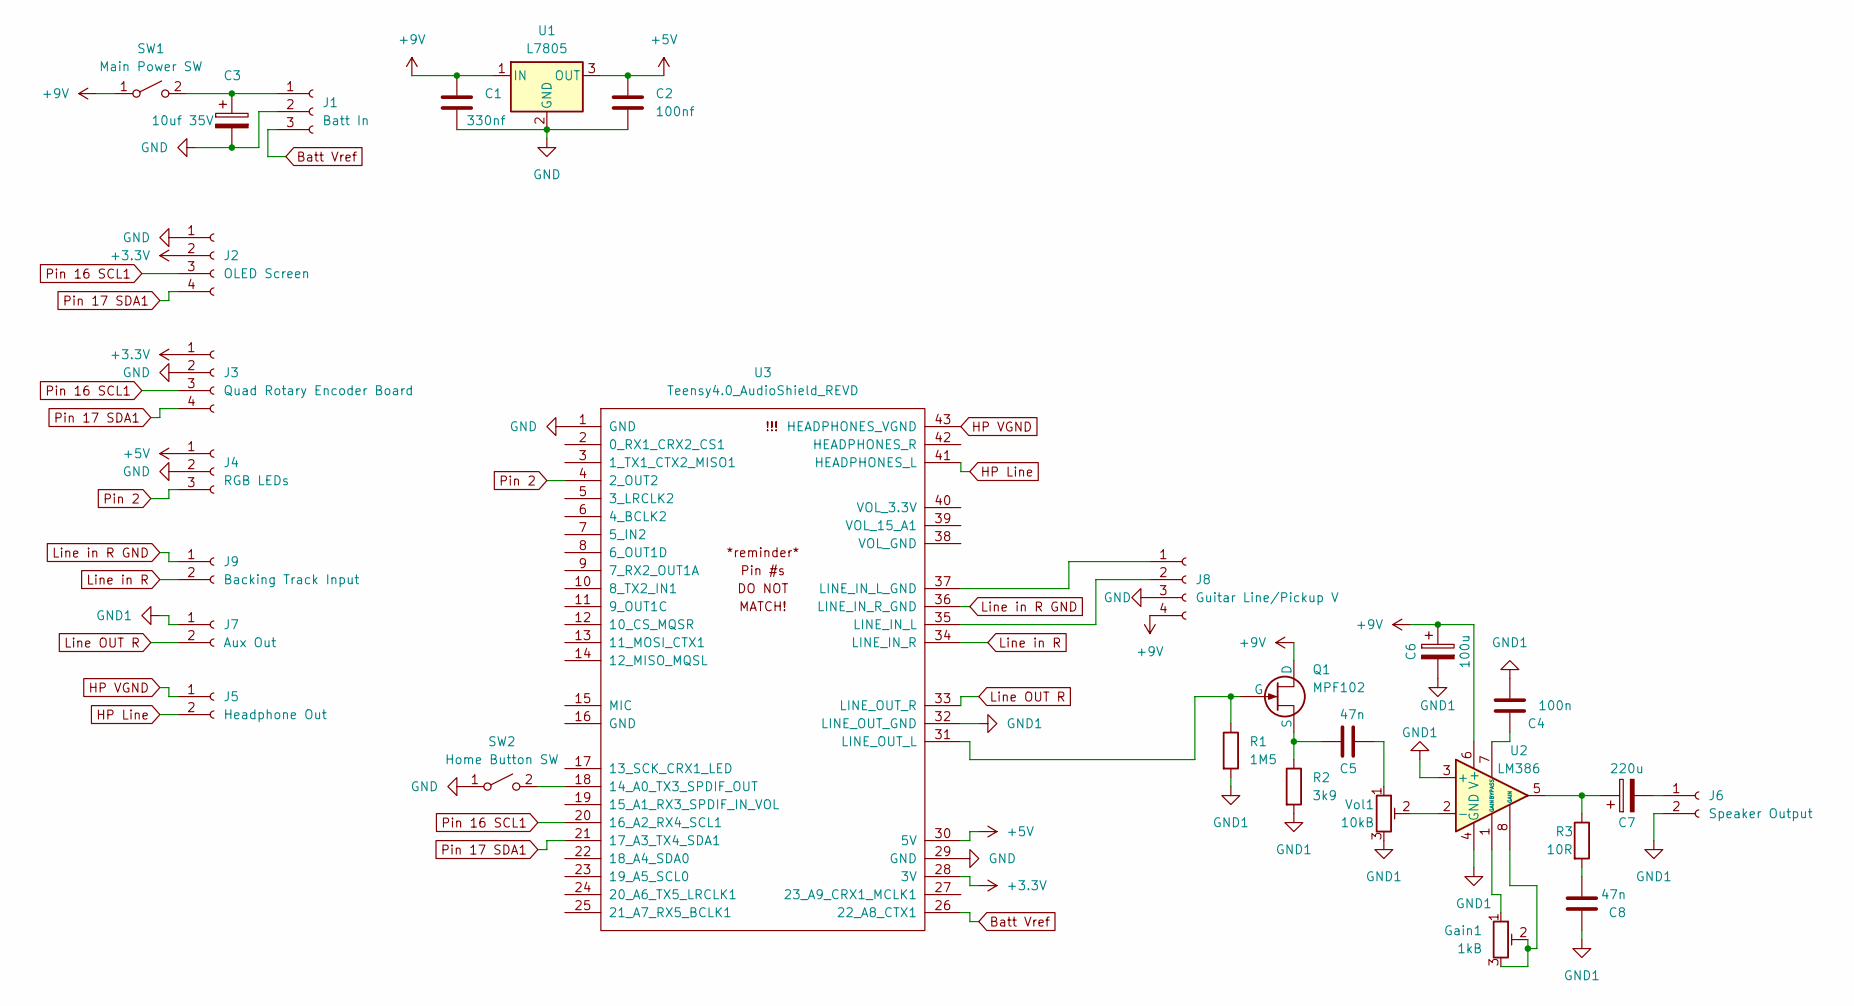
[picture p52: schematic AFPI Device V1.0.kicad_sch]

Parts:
C1: 330nf; C_1206_3216Metric
C2: 100nf; C_1206_3216Metric
C3: 10uf 35V; CP_Elec_5x5.4
C4: 100n; C_1206_3216Metric
C5, C8: 47n; C_1206_3216Metric
C6: 100u; CP_Elec_6.3x7.7
C7: 220u; CP_Elec_8x10.5
Gain1: 1kB; Potentiometer_Piher_PT-6-V_Vertical
J1: Batt In; JST_XH_B3B-XH-A_1x03_P2.50mm_Vertical
J2: OLED Screen; JST_GH_BM04B-GHS-TBT_1x04-1MP_P1.25mm_Vertical
J3: Quad Rotary Encoder Board; JST_GH_BM04B-GHS-TBT_1x04-1MP_P1.25mm_Vertical
J4: RGB LEDs; JST_GH_BM03B-GHS-TBT_1x03-1MP_P1.25mm_Vertical
J5: Headphone Out; JST_GH_BM02B-GHS-TBT_1x02-1MP_P1.25mm_Vertical
J6: Speaker Output; JST_GH_BM02B-GHS-TBT_1x02-1MP_P1.25mm_Vertical
J7: Aux Out; JST_GH_BM02B-GHS-TBT_1x02-1MP_P1.25mm_Vertical
J8: Guitar Line/Pickup V; JST_GH_BM04B-GHS-TBT_1x04-1MP_P1.25mm_Vertical
J9: Backing Track Input; JST_GH_BM02B-GHS-TBT_1x02-1MP_P1.25mm_Vertical
Q1: MPF102; TO-92
R1: 1M5; R_1206_3216Metric
R2: 3k9; R_1206_3216Metric
R3: 10R; R_1206_3216Metric
SW1: Main Power SW; JST_XH_B2B-XH-A_1x02_P2.50mm_Vertical
SW2: Home Button SW; JST_GH_BM02B-GHS-TBT_1x02-1MP_P1.25mm_Vertical
U1: L7805; TO-220-3_Horizontal_TabDown
U2: LM386; DIP-8_W7.62mm
U3: Teensy4.0_AudioShield_REVD; Teensy 4.0 audioshield
Vol1: 10kB; Potentiometer_Piher_PT-6-V_Vertical

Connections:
+3.3V: J2.2, J3.1, U3.28 (3V)
+5V: C2.1, J4.1, U1.3 (OUT), U3.30 (5V)
+9V: C1.1, C6.1, J8.4, Q1.1 (D), SW1.1 (A), U1.1 (IN), U2.6 (V+)
Batt Vref: J1.3, U3.26 (22_A8_CTX1)
GND: C1.2, C2.2, C3.2, J1.2, J2.1, J3.2, J4.2, J8.3, SW2.1 (A), U1.2 (GND), U3.1 (GND), U3.29 (GND)
GND1: C4.2, C6.2, C8.1, J6.2, J7.1, R1.2, R2.2, U2.3 (+), U2.4 (GND), U3.32 (LINE_OUT_GND), Vol1.3
HP Line: J5.2, U3.41 (HEADPHONES_L)
HP VGND: J5.1, U3.43 (HEADPHONES_VGND)
Line OUT R: J7.2, U3.33 (LINE_OUT_R)
Line in R: J9.2, U3.34 (LINE_IN_R)
Line in R GND: J9.1, U3.36 (LINE_IN_R_GND)
unnamed: C5.1, Vol1.1
unnamed: C7.1, R3.1, U2.5
unnamed: C8.2, R3.2
unnamed: Gain1.1, U2.1 (GAIN)
unnamed: Gain1.2, Gain1.3, U2.8 (GAIN)
unnamed: C3.1, J1.1, SW1.2 (B)
unnamed: C7.2, J6.1
unnamed: J8.1, U3.37 (LINE_IN_L_GND)
unnamed: J8.2, U3.35 (LINE_IN_L)
unnamed: Q1.2 (G), R1.1, U3.31 (LINE_OUT_L)
unnamed: C5.2, Q1.3 (S), R2.1
unnamed: SW2.2 (B), U3.18 (14_A0_TX3_SPDIF_OUT)
unnamed: U2.2 (-), Vol1.2
unnamed: C4.1, U2.7 (BYPASS)
Pin 2: J4.3, U3.4 (2_OUT2)
Pin 16 SCL1: J2.3, J3.3, U3.20 (16_A2_RX4_SCL1)
Pin 17 SDA1: J2.4, J3.4, U3.21 (17_A3_TX4_SDA1)

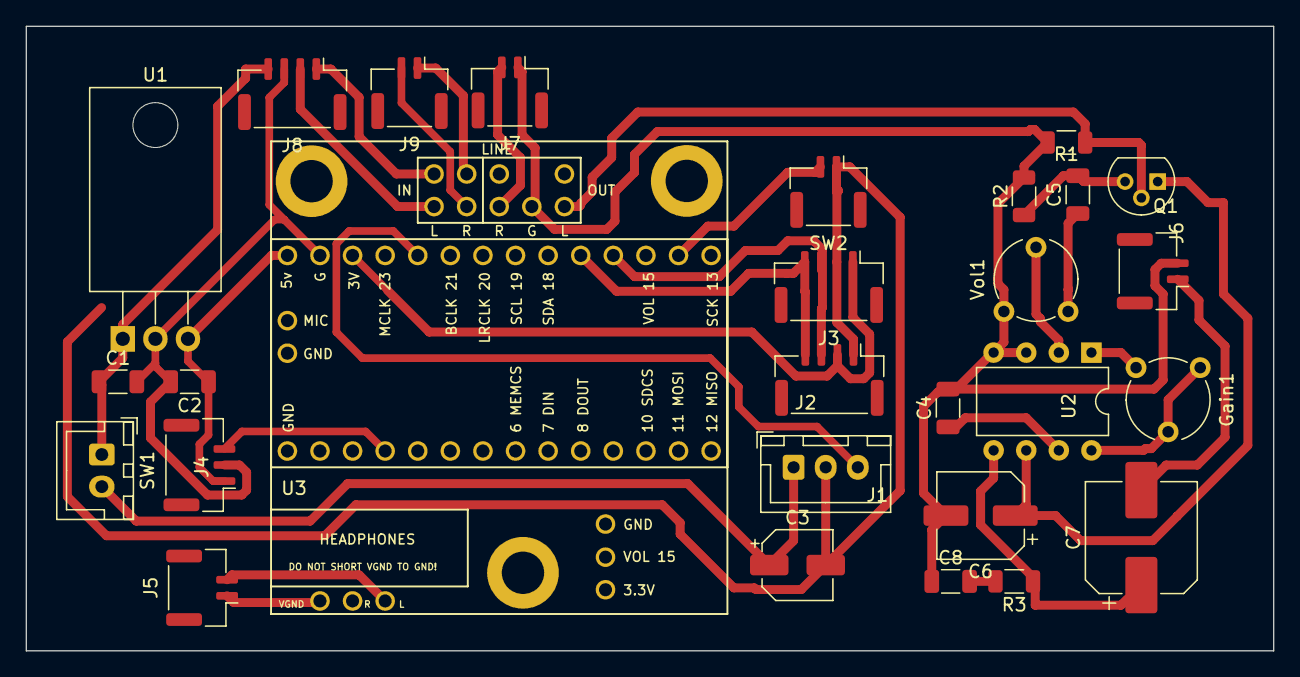
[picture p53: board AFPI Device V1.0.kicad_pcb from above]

Board: 2 copper layers, 97.2 x 48.7 mm, 28 parts (0 on the bottom side), 28 nets.

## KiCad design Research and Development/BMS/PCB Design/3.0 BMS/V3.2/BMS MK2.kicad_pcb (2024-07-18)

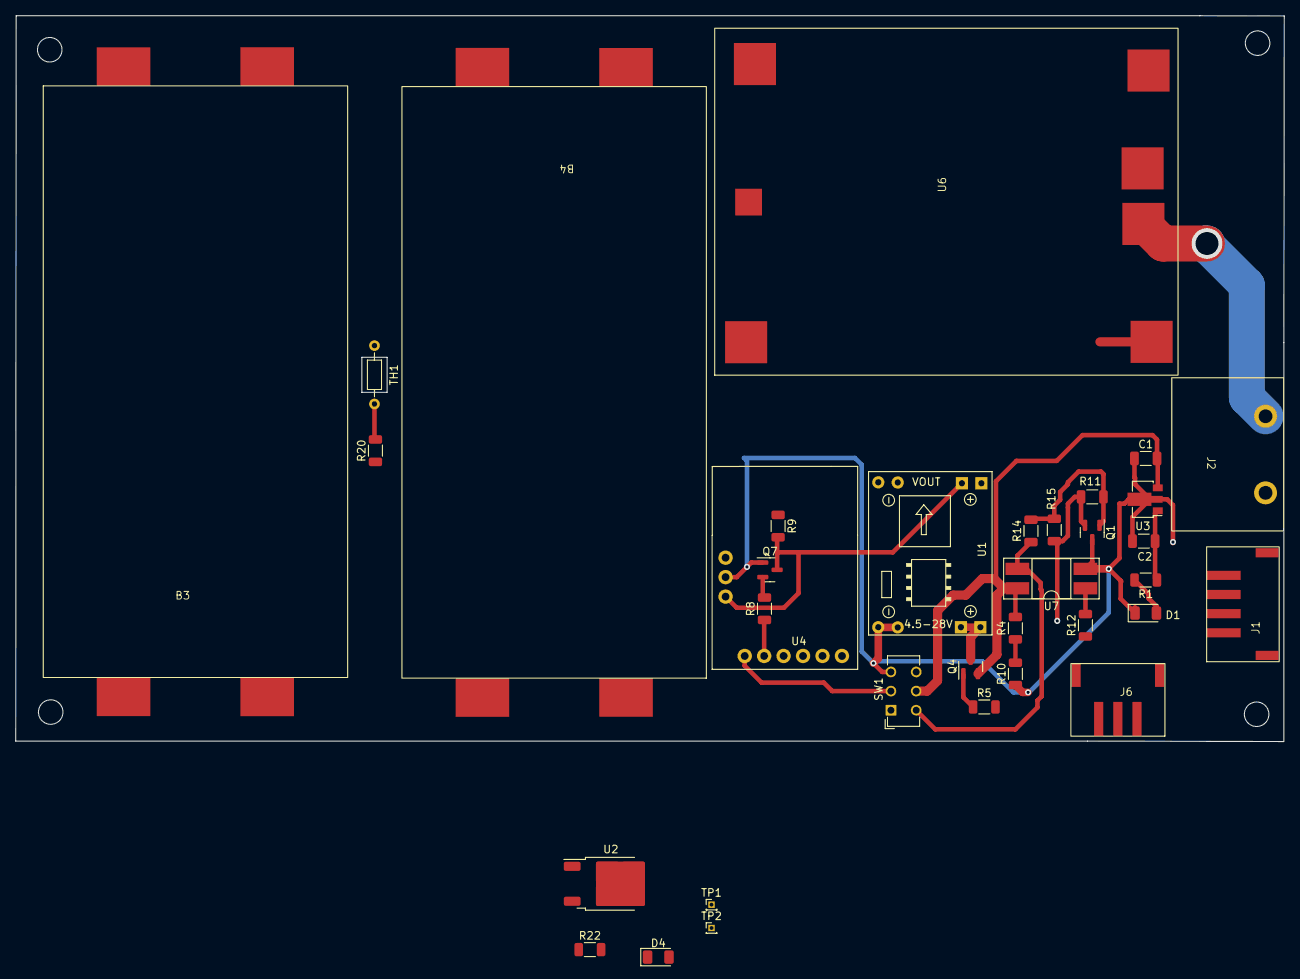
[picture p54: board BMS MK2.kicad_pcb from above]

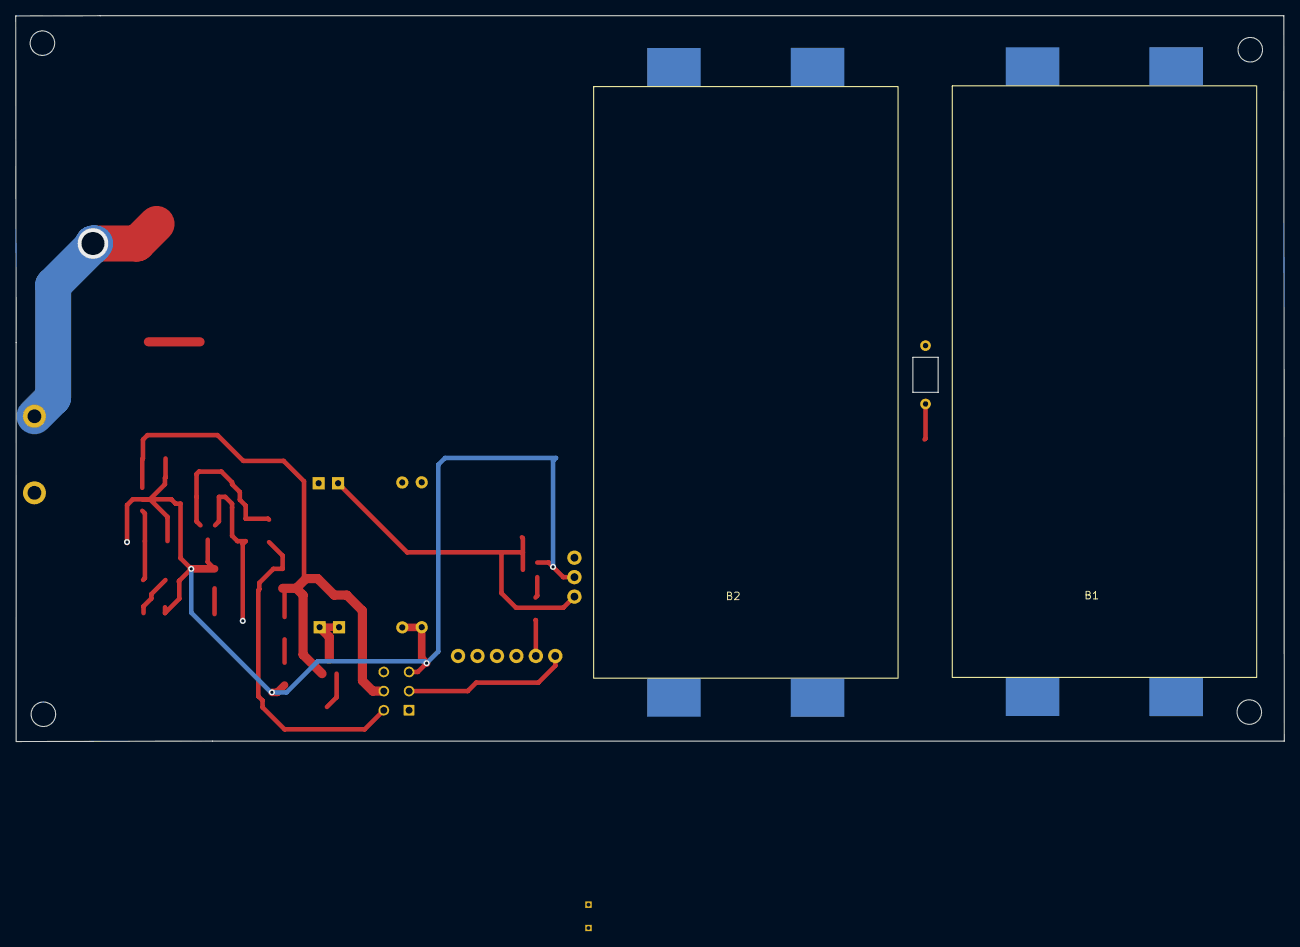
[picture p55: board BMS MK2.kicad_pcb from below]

Board: 2 copper layers, 165.7 x 94.8 mm, 36 parts (2 on the bottom side), 26 nets.

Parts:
B1, B2, B3, B4: 18650 Batt 2S Holder
C1, C2: C; C_1206_3216Metric
D1: ON LED; LED_1206_3216Metric
D4: CHG LED; LED_1206_3216Metric
J1: PWR LOAD OUT; XH 2.54mm 4p vertical header
J2: B CHG IN; kf1000 screw terminal
J6: load chg in; XH 2.54mm 3p smd vertical header
Q1: AO3400A; SOT-23
Q4: AO3407; SOT-23
Q7: PN100; SOT-23
R1, R22: R; R_1206_3216Metric
R4, R9, R10, R14, R15, R20: 10K; R_1206_3216Metric
R5: 1.2K; R_1206_3216Metric
R8: 3k3; R_1206_3216Metric
R11: 100K; R_1206_3216Metric
R12: 430R; R_1206_3216Metric
SW1: SW_DPDT_x2; SW_CuK_JS202011CQN_DPDT_Straight
TH1: Thermistor; R_Axial_DIN0204_L3.6mm_D1.6mm_P7.62mm_Horizontal
TP1: B+; PinHeader_1x01_P1.00mm_Vertical
TP2: B-; PinHeader_1x01_P1.00mm_Vertical
U1: MP1584; SRT_MPT1584EN_Module
U2: AOD409; TO-252-2
U3: L78L05_SOT89; SOT-89-3
U4: ATTiny 85 Module; Digispark attiny85 board
U6: 4s Batt Protect Module; BMS 4S Module
U7: PC817; DIP-4_W8.89mm_SMDSocket_LongPads

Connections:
5v attiny out: R20.1, U4.1 (5V)
+9V: Q7.3 (C), R9.2, U1.3 (OUT+), U4.3 (VIN)
+12V: J6.3, Q4.3 (D), R5.2, U1.1 (IN+)
+BATT: C1.2, Q4.2 (S), R4.2, R22.1, SW1.5 (B), TP1.1, U2.2 (D), U3.3 (IN), U6.1 (P+), U7.4
+VDC: J2.2, U2.3 (S)
-12V: C1.1, C2.1, D1.1 (K), J1.1, J6.2, Q1.3 (D), Q7.1 (E), R10.1, SW1.3 (C), TH1.1, U1.2 (IN-), U1.4 (OUT-), U3.2 (GND), U4.2 (GND), U7.2
-BATT: D4.1 (K), J2.1, Q1.2 (S), R11.1, R15.2, TP2.1, U6.2 (P-)
Batt SW VCC: R12.1, U4.8 (P4)
Battery Vref: J1.3, J6.1, R4.1, R10.2, U4.7 (P3)
CGE SW V+: R9.1, U2.1 (G)
unnamed: B1.1 (B1+), B1.3 (B2+), B2.2 (B1-), B2.4 (B2-), U6.4 (4.2V)
unnamed: B1.2 (B1-), B1.4 (B2-), U6.3 (0V)
unnamed: B2.1 (B1+), B2.3 (B2+), B3.2 (B1-), B3.4 (B2-), U6.5 (8.4V)
unnamed: B3.1 (B1+), B3.3 (B2+), B4.2 (B1-), B4.4 (B2-), U6.6 (12.6V)
unnamed: B4.1 (B1+), B4.3 (B2+), U6.7 (16.8V)
unnamed: D1.2 (A), R1.2
unnamed: D4.2 (A), R22.2
unnamed: Q1.1 (G), R11.2, R14.2, R15.1
unnamed: Q7.2 (B), R8.2
unnamed: R12.2, U7.1
unnamed: SW1.2 (B), U4.4 (P0)
unnamed: R14.1, SW1.4 (A), U7.3
unnamed: C2.2, R1.1, U3.1 (OUT)
unnamed: R8.1, U4.5 (P1)
unnamed: R20.2, TH1.2, U4.6 (P2)
VD: J1.4, Q4.1 (G), R5.1

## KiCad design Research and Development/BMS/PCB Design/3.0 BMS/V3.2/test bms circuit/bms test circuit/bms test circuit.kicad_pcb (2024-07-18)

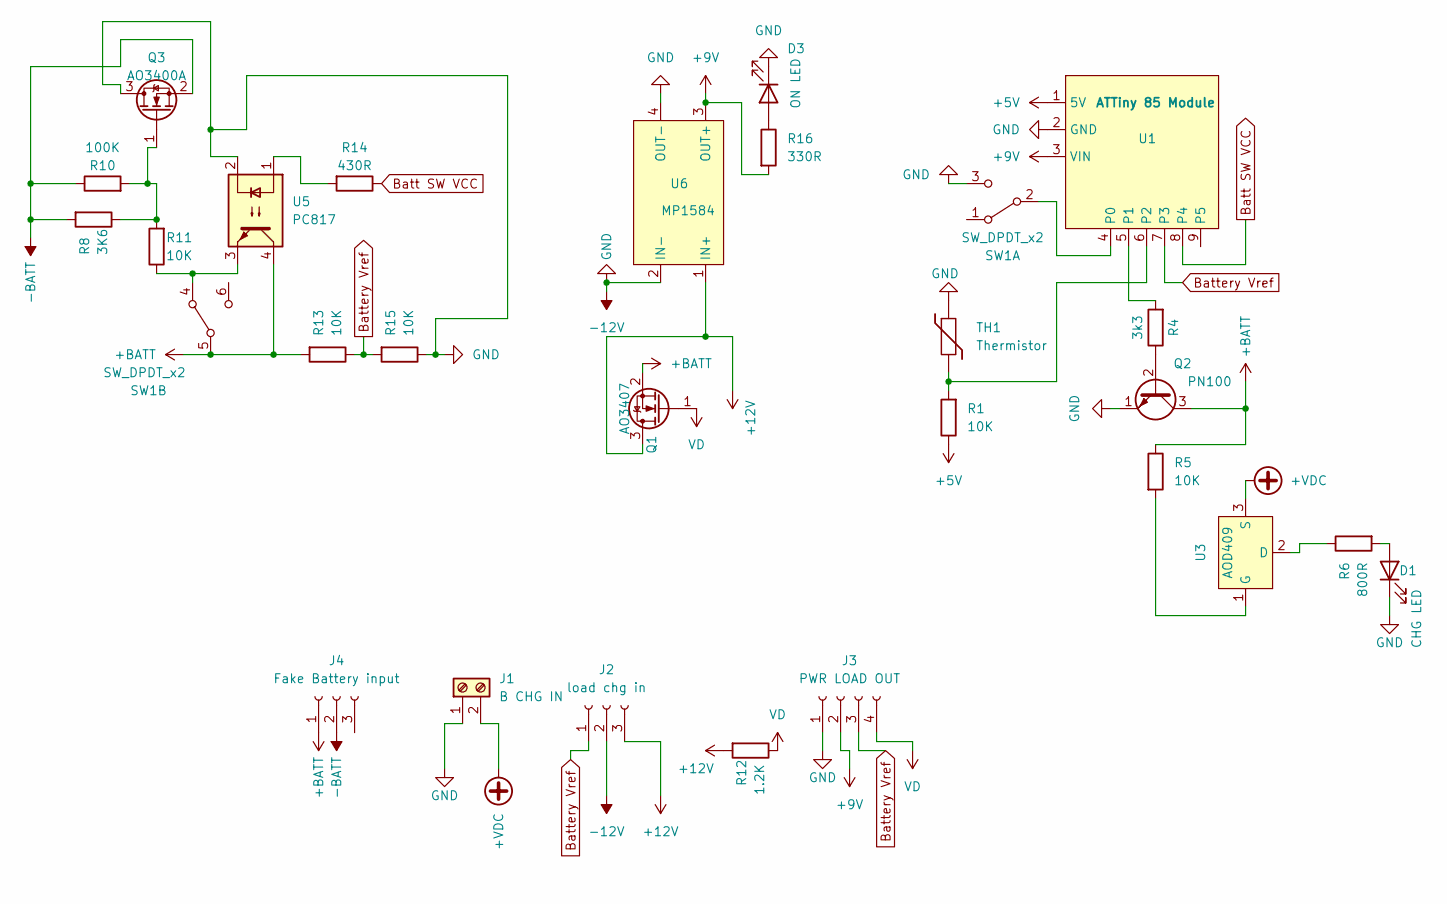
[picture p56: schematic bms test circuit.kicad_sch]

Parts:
D1: CHG LED; LED_1206_3216Metric
D3: ON LED; LED_1206_3216Metric
J1: B CHG IN; kf1000 screw terminal
J2: load chg in; XH 2.54mm 3p smd vertical header
J3: PWR LOAD OUT; XH 2.54mm 4p vertical header
J4: Fake Battery input; XH 2.54mm 3p smd vertical header
Q1: AO3407; SOT-23
Q2: PN100; SOT-23
Q3: AO3400A; SOT-23
R1, R5, R11, R13, R15: 10K; R_1206_3216Metric
R4: 3k3; R_1206_3216Metric
R6: 800R; R_1206_3216Metric
R8: 3K6; R_1206_3216Metric
R10: 100K; R_1206_3216Metric
R12: 1.2K; R_1206_3216Metric
R14: 430R; R_1206_3216Metric
R16: 330R; R_1206_3216Metric
SW1: SW_DPDT_x2; SW_CuK_JS202011CQN_DPDT_Straight
TH1: Thermistor; R_Axial_DIN0204_L3.6mm_D1.6mm_P7.62mm_Horizontal
U1: ATTiny 85 Module; Digispark attiny85 board
U3: AOD409; TO-252-2
U5: PC817; DIP-4_W8.89mm_SMDSocket_LongPads
U6: MP1584; SRT_MPT1584EN_Module

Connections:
+5V: R1.1, U1.1 (5V)
+9V: J3.2, R16.2, U1.3 (VIN), U6.3 (OUT+)
+12V: J2.3, Q1.3 (D), R12.2, U6.1 (IN+)
+BATT: J4.1, Q1.2 (S), Q2.3 (C), R5.1, R13.2, SW1.5 (B), U5.4
+VDC: J1.2, U3.3 (S)
-12V: D1.1 (K), D3.1 (K), J1.1, J2.2, J3.1, Q2.1 (E), Q3.3 (D), R15.1, SW1.3 (C), TH1.1, U1.2 (GND), U5.2, U6.2 (IN-), U6.4 (OUT-)
-BATT: J4.2, Q3.2 (S), R8.2, R10.1
Batt SW VCC: R14.1, U1.8 (P4)
Battery Vref: J2.1, J3.3, R13.1, R15.2, U1.7 (P3)
unnamed: D1.2 (A), R6.2
unnamed: D3.2 (A), R16.1
unnamed: Q2.2 (B), R4.1
unnamed: Q3.1 (G), R8.1, R10.2, R11.2
unnamed: R14.2, U5.1
unnamed: SW1.2 (B), U1.4 (P0)
unnamed: R11.1, SW1.4 (A), U5.3
unnamed: R4.2, U1.5 (P1)
unnamed: R1.2, TH1.2, U1.6 (P2)
unnamed: R6.1, U3.2 (D)
unnamed: R5.2, U3.1 (G)
VD: J3.4, Q1.1 (G), R12.1

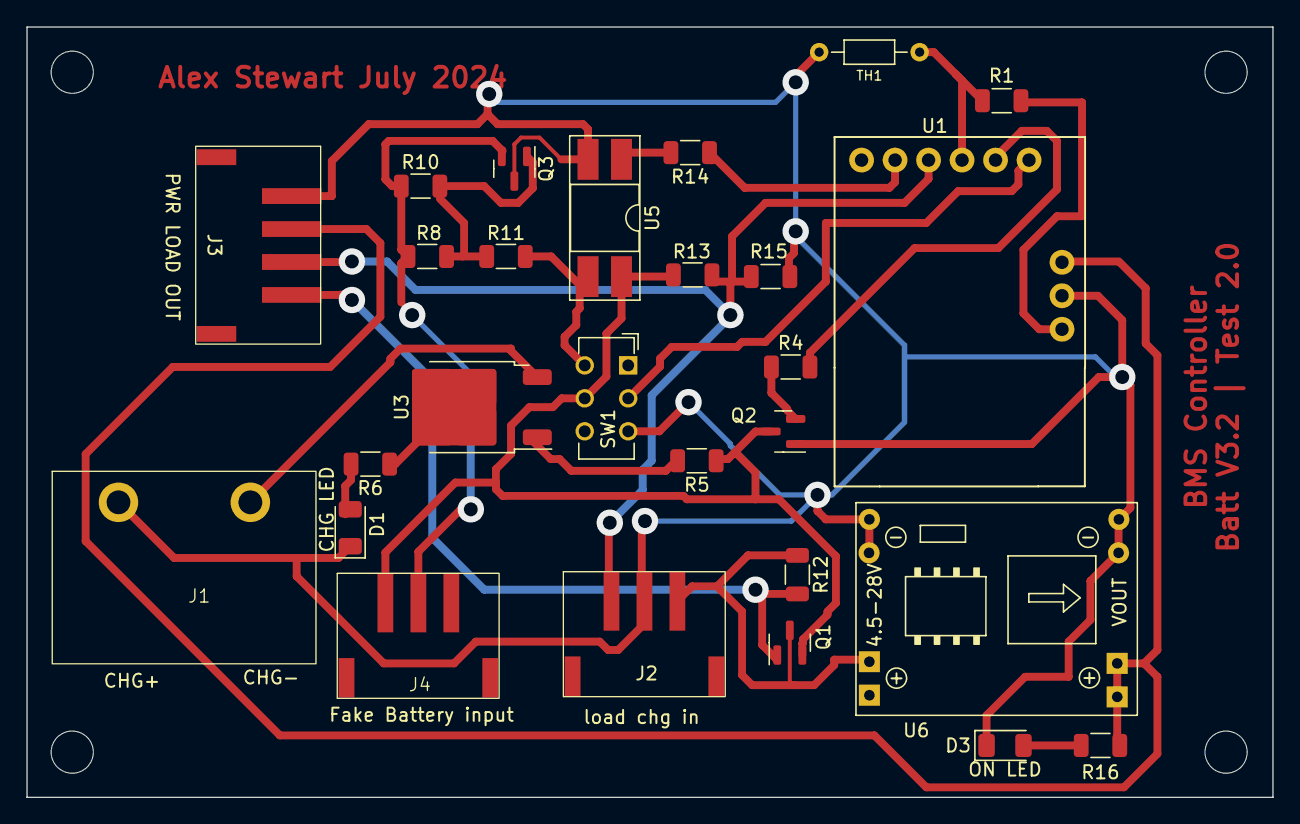
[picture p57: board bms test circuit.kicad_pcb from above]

Board: 2 copper layers, 94.5 x 58.4 mm, 27 parts (0 on the bottom side), 21 nets.

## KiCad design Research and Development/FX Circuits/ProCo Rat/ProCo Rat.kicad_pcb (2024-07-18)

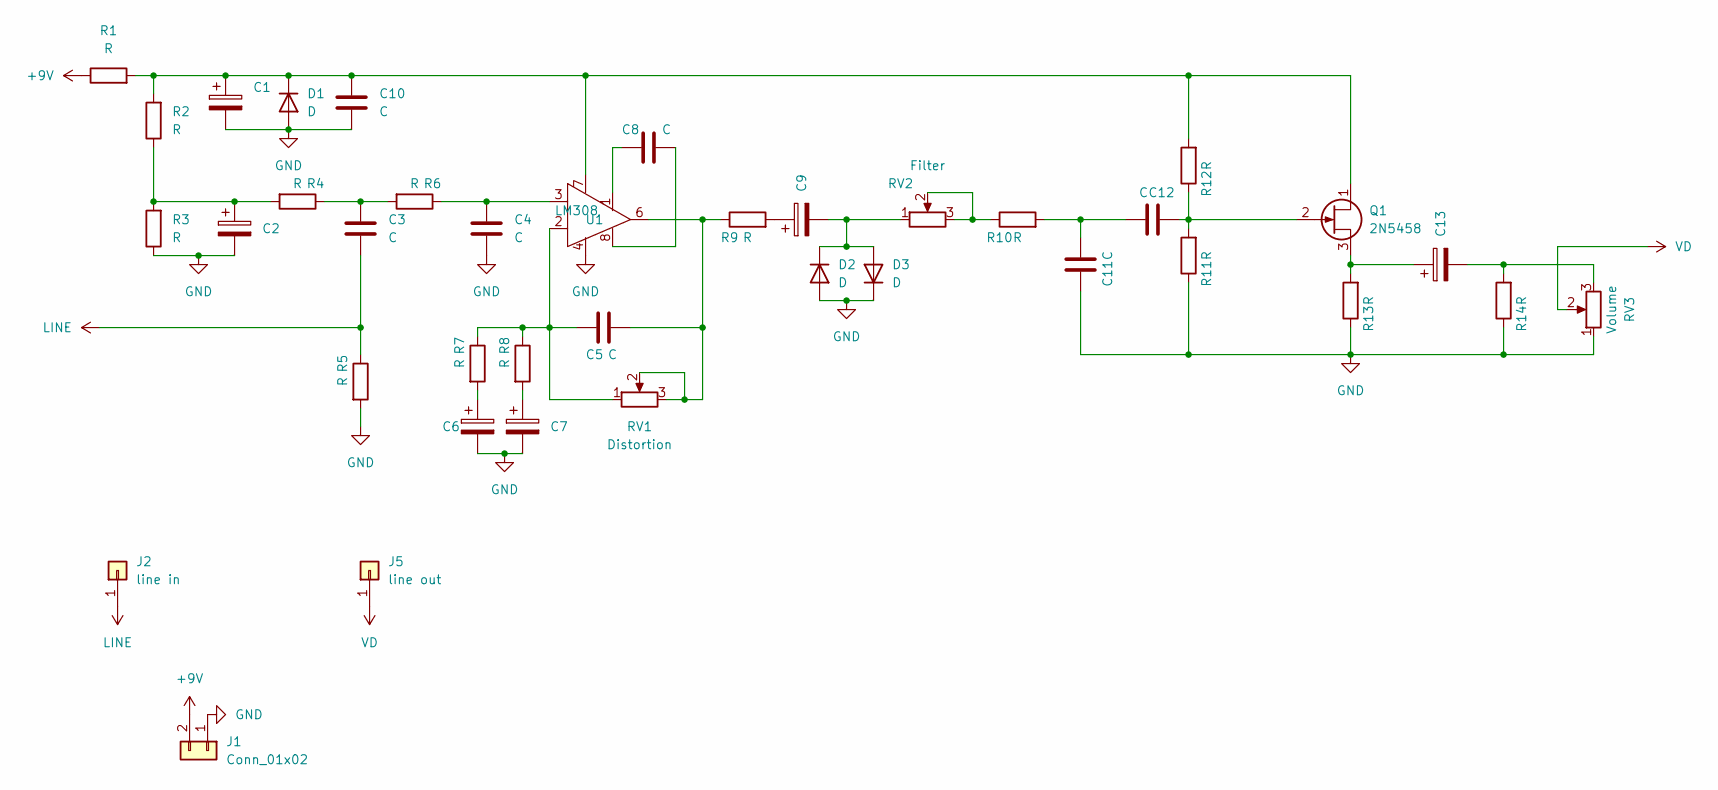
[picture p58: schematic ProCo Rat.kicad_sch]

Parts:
C1: C_Polarized; CP_Elec_6.3x5.4
C2, C6, C7, C9, C13: C_Polarized; CP_Elec_4x5.4
C3, C4, C5, C8, C10, C11, C12: C; C_1206_3216Metric
D1, D2, D3: D; D_1206_3216Metric
J1: Conn_01x02; PinHeader_1x02_P2.54mm_Vertical_SMD_Pin1Left
J2: line in; PinHeader_1x01_P2.54mm_Vertical
J5: line out; PinHeader_1x01_P2.54mm_Vertical
Q1: 2N5458; TO-92
R1, R2, R3, R4, R5, R6, R7, R8, R9, R10, R11, R12, R13, R14: R; R_1206_3216Metric
RV1: Distortion; XH 2.54mm 3p smd vertical header
RV2: Filter; XH 2.54mm 3p smd vertical header
RV3: Volume; XH 2.54mm 3p smd vertical header
U1: LM308; DIP-8_W7.62mm

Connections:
+9V: J1.2, R1.1
GND: C1.2, C2.2, C4.2, C6.2, C7.2, C10.2, C11.1, D1.2 (A), D2.2 (A), D3.1 (K), J1.1, R3.1, R5.2, R11.1, R13.1, R14.1, RV3.1, U1.4
LINE: C3.2, J2.1, R5.1
unnamed: C2.1, R2.1, R3.2, R4.2
unnamed: C3.1, R4.1, R6.2
unnamed: C4.1, R6.1, U1.3
unnamed: C5.1, R7.1, R8.1, RV1.1, U1.2
unnamed: C5.2, R9.1, RV1.2, RV1.3, U1.6
unnamed: C6.1, R7.2
unnamed: C7.1, R8.2
unnamed: C8.1, U1.1
unnamed: C8.2, U1.8
unnamed: C9.1, R9.2
unnamed: C11.2, C12.2, R10.2
unnamed: C13.2, R14.2, RV3.3
unnamed: C1.1, C10.1, D1.1 (K), Q1.1 (D), R1.2, R2.2, R12.2, U1.7
unnamed: C9.2, D2.1 (K), D3.2 (A), RV2.1
unnamed: C12.1, Q1.2 (G), R11.2, R12.1
unnamed: C13.1, Q1.3 (S), R13.2
unnamed: R10.1, RV2.2, RV2.3
VD: J5.1, RV3.2

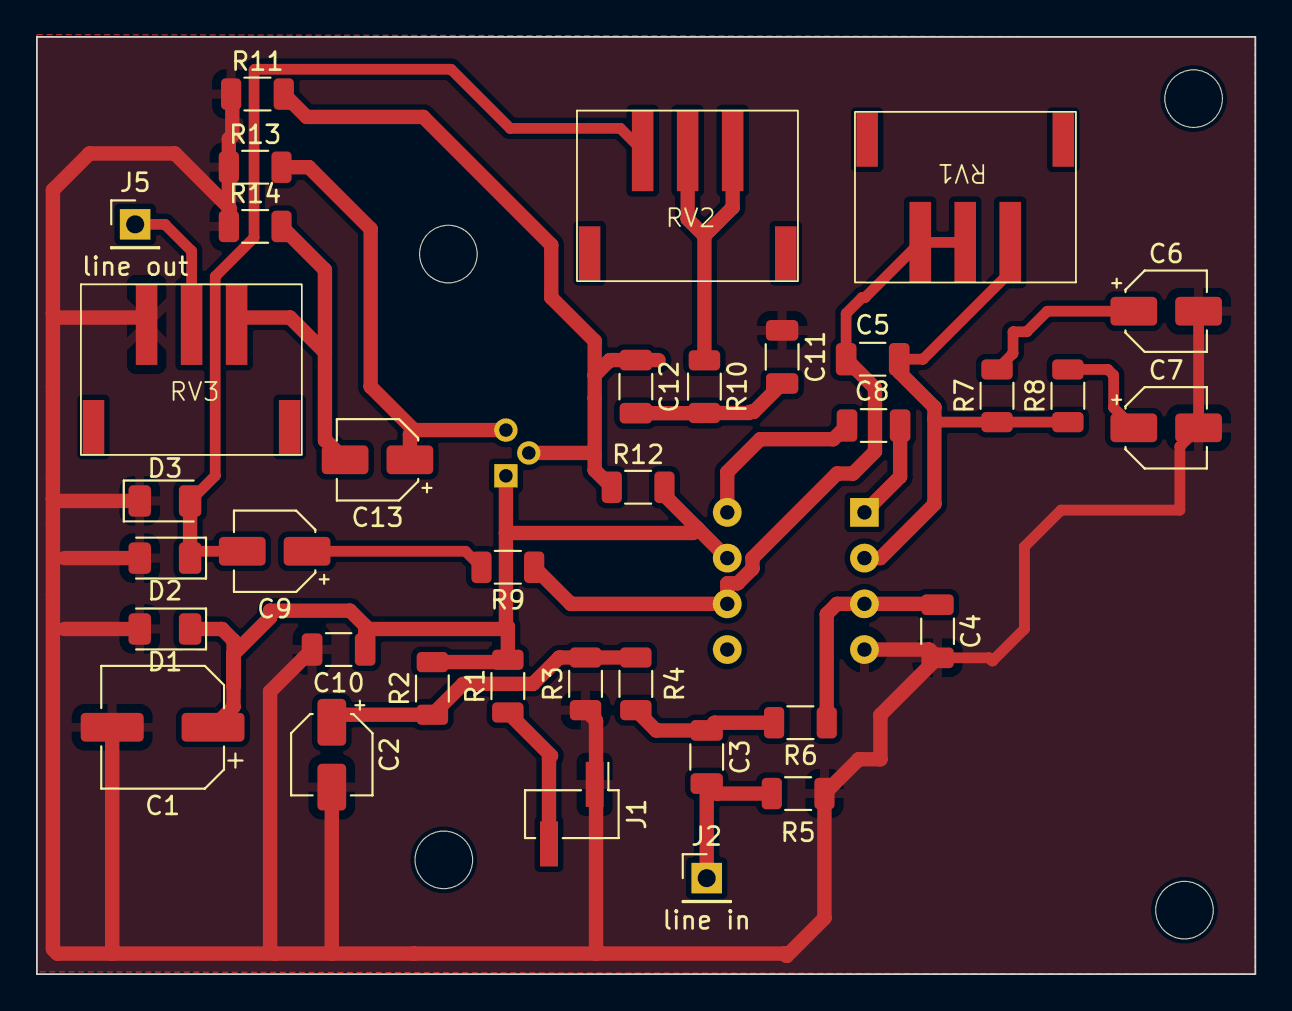
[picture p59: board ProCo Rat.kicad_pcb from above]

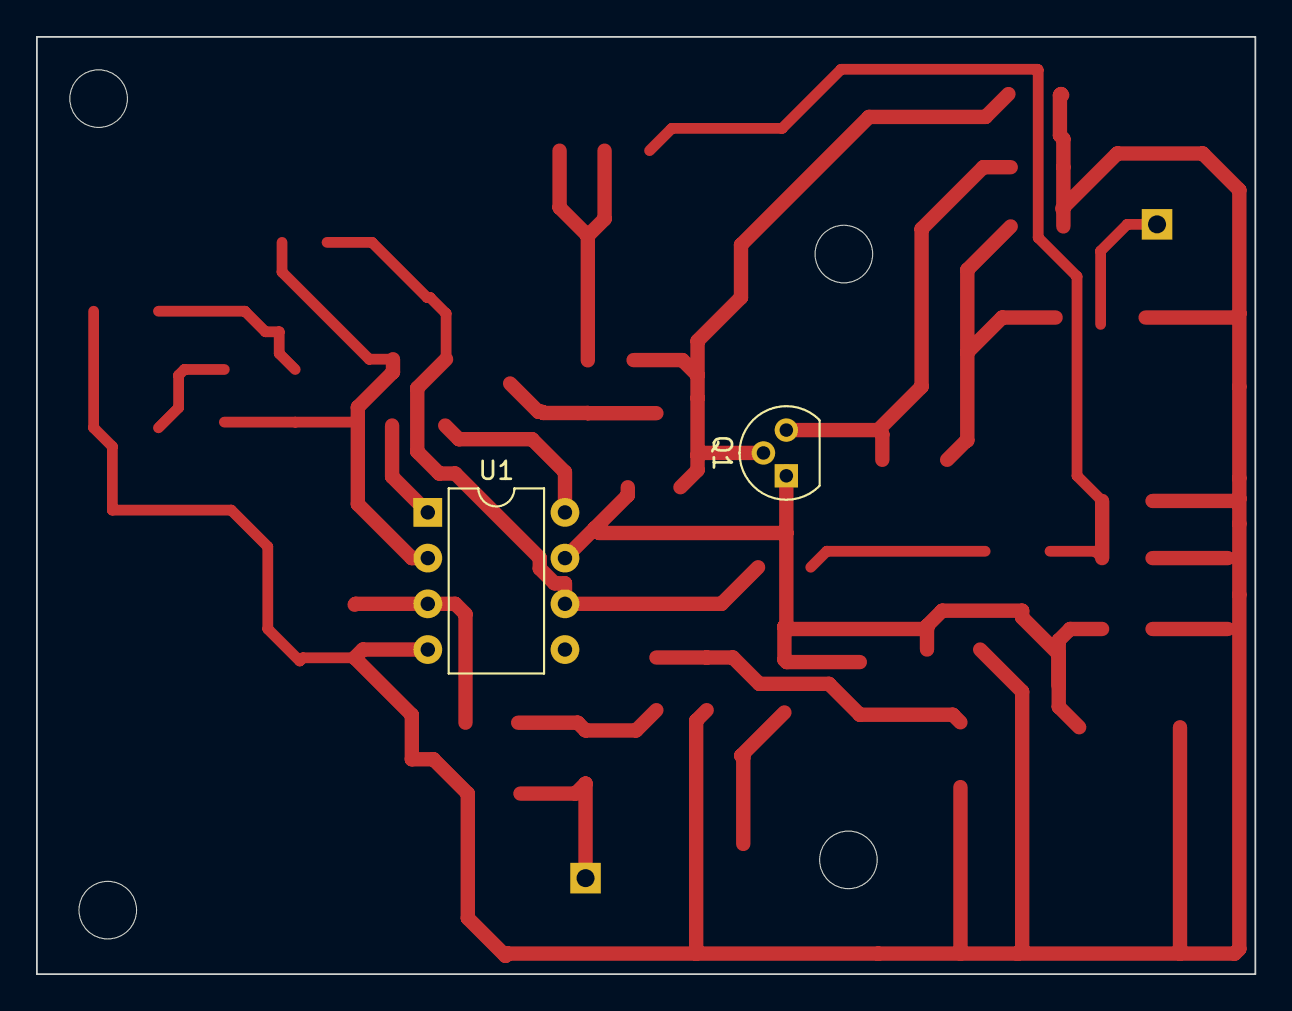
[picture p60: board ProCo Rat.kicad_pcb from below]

Board: 2 copper layers, 67.7 x 52.1 mm, 38 parts (2 on the bottom side), 21 nets.

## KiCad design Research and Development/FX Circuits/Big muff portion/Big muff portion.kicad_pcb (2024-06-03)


Board: 2 copper layers, 31.0 x 37.0 mm, 11 parts (0 on the bottom side), 4 nets.

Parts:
D1, D2, D3, D4: 1N62xxA; D_DO-201AE_P15.24mm_Horizontal
D5: 1N4001; D_DO-41_SOD81_P10.16mm_Horizontal
J1: IN; PinHeader_1x01_P1.00mm_Vertical
J2: OUT; PinHeader_1x01_P1.00mm_Vertical
Q1, Q2, Q3, Q4: TO-92_Inline

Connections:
unnamed: D1.1 (A1), D2.2 (A2)
unnamed: D1.2 (A2), D2.1 (A1), Q2.3 (C)
unnamed: D3.1 (A1), D4.1 (A1)
unnamed: D3.2 (A2), D4.2 (A2), Q3.3 (C)

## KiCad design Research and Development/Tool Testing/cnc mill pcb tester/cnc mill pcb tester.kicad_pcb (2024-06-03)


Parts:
D1: LED_RGAB; LED_D5.0mm-4_RGB
J1: Screw_Terminal_01x02; TerminalBlock_Altech_AK300-2_P5.00mm
R1: RED; R_Axial_DIN0207_L6.3mm_D2.5mm_P10.16mm_Horizontal
R2: GREEN; R_Axial_DIN0207_L6.3mm_D2.5mm_P10.16mm_Horizontal
R3: B; R_Axial_DIN0207_L6.3mm_D2.5mm_P10.16mm_Horizontal
U2: LM339; SOIC-14_3.9x8.7mm_P1.27mm

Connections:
DATA1: U2.5 (+); also elsewhere on the board
unnamed: D1.3 (A), J1.1
unnamed: D1.4 (BK), R3.2
unnamed: D1.2 (GK), R2.2
unnamed: D1.1 (RK), R1.2
unnamed: J1.2, R1.1, R2.1, R3.1


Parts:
U1: LM339; SOIC-14_3.9x8.7mm_P1.27mm

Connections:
DATA1: U1.5 (+); also elsewhere on the board


Board: 2 copper layers, 47.0 x 25.4 mm, 7 parts (0 on the bottom side), 6 nets.

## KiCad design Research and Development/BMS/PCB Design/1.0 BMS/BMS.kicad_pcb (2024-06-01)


Board: 2 copper layers, 179.0 x 88.4 mm, 64 parts (0 on the bottom side), 63 nets, no tracks yet.

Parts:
C2: 2nf; C_Rect_L9.0mm_W3.3mm_P7.50mm_MKT
C3: 220uf; CP_Radial_D8.0mm_P5.00mm
D2: LED_KGRB; LED_D5.0mm-4_RGB
J1, J14, J16: Conn_01x04_Pin; PinHeader_2x02_P1.00mm_Vertical
J3: Batt 1 Conn; PinHeader_1x02_P1.00mm_Vertical
J5: Batt 2 Conn; PinHeader_1x02_P1.00mm_Vertical
J6: Batt 3 Conn; PinHeader_1x02_P1.00mm_Vertical
J7: Batt 4 Conn; PinHeader_1x02_P1.00mm_Vertical
J9: Batt 5 Conn; PinHeader_1x02_P1.00mm_Vertical
J10: Batt 6 Conn; PinHeader_1x02_P1.00mm_Vertical
J11: Batt 7 Conn; PinHeader_1x02_P1.00mm_Vertical
J12: Batt 8 Conn; PinHeader_1x02_P1.00mm_Vertical
J13: Conn_01x06_Pin; PinHeader_2x03_P1.00mm_Vertical
J17: Moment ON B; PinHeader_1x02_P1.00mm_Vertical
Q1, Q12, Q14, Q15: IRL540; TO-220-3_Horizontal_TabDown
Q10, Q11, Q13, Q17, Q18: PN2222A; TO-92_Inline
Q16: ZVP2106A; TO-92_Inline
R1, R2, R3, R4, R5, R7, R11, R16: 10K; R_1206_3216Metric
R6, R8, R12, R13, R14, R15: R; R_1206_3216Metric
R9: 30K; R_1206_3216Metric
R10: 7.5K; R_1206_3216Metric
R17: 150R; R_1206_3216Metric
R18: 90R; R_1206_3216Metric
R19: 100R; R_1206_3216Metric
TH1, TH2, TH3, TH4: Thermistor_NTC; R_Axial_DIN0204_L3.6mm_D1.6mm_P5.08mm_Vertical
U2: 78L05; TO-92_Inline
U4: MP1584 Module; SRT_MPT1584EN_Module
U5, U6, U7, U8, U9, U10, U11, U12: TP4056 Charging Module; TP4056-18650
U14, U15: LM339; lm339n THT
U16: 74HC02; DIP-14_W7.62mm
U17: LM393; DIP-8_W7.62mm
U18: LMC555xN; DIP-8_W7.62mm

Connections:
BMS VCC 5V+: Q10.3 (C), R6.2, R8.2, R12.2, R16.2, TH1.2, TH2.2, TH3.2, TH4.2, U2.1 (VO), U14.3 (V+), U15.3 (V+), U16.14 (VCC), U17.8 (V+), U18.4 (R), U18.8 (VCC)
Batt Cuttoff Logic: Q1.1 (G), U17.1
Batt V: J1.2, J13.2, R9.1, R10.2, U17.3 (+)
Charge VCC: Q14.3 (S), U5.1 (IN+), U6.1 (IN+), U7.1 (IN+), U8.1 (IN+), U9.1 (IN+), U10.1 (IN+), U11.1 (IN+), U12.1 (IN+)
Charger Digital Signal: J13.4, Q12.1 (G), Q13.2 (B)
Charger In 5v+: J13.6, Q14.2 (D)
GND: C2.1, C3.2, D2.1 (K), J1.3, J13.3, J17.2, R1.1, R2.1, R3.1, R4.1, R5.1, R7.1, R10.1, R11.1, R15.2, U2.2 (GND), U4.1 (IN+), U4.4 (OUT-), U5.2 (IN-), U6.2 (IN-), U7.2 (IN-), U8.2 (IN-), U8.4 (OUT-), U9.2 (IN-), U10.2 (IN-), U11.2 (IN-), U12.2 (IN-), U12.4 (OUT-), U14.12 (V-), U15.12 (V-), U16.7 (GND), U17.4 (V-), U18.1 (GND), U18.5 (CV)
Guitar VCC 9v+: J1.4, Q12.3 (S), Q15.3 (S)
Hi T Comp Out: J1.1, R13.1, U14.1, U14.2, U14.13, U14.14, U16.2
Hi T Vref: R5.2, R6.1, U14.5 (+), U14.7 (+), U14.9 (+), U14.11 (+)
LED VCC: Q16.3 (C), Q17.3 (C), Q18.3 (C), U18.3 (Q)
Lo T Comp Out: J13.1, R14.1, U15.1, U15.2, U15.13, U15.14, U16.3
Lo T Vref: R7.2, R8.1, U15.5 (+), U15.7 (+), U15.9 (+), U15.11 (+)
unnamed: D2.4 (BA), R18.1
unnamed: D2.2 (GA), R19.1
unnamed: D2.3 (RA), R17.2
unnamed: J3.1, U5.6 (B-)
unnamed: J3.2, U5.5 (B+)
unnamed: J5.1, U6.6 (B-)
unnamed: J5.2, U6.5 (B+)
unnamed: J6.1, U7.6 (B-)
unnamed: J6.2, U7.5 (B+)
unnamed: J7.1, U8.6 (B-)
unnamed: J7.2, U8.5 (B+)
unnamed: J9.1, U9.6 (B-)
unnamed: J9.2, U9.5 (B+)
unnamed: J10.1, U10.6 (B-)
unnamed: J10.2, U10.5 (B+)
unnamed: J11.1, U11.6 (B-)
unnamed: J11.2, U11.5 (B+)
unnamed: J12.1, U12.6 (B-)
unnamed: J12.2, U12.5 (B+)
unnamed: J14.1, J16.1
unnamed: J14.2, J16.2
unnamed: J14.3, J16.3
unnamed: J14.4, J16.4
unnamed: J17.1, U18.2 (TR)
unnamed: Q10.2 (B), R13.2
unnamed: Q10.1 (E), Q11.3 (C)
unnamed: Q11.2 (B), R14.2
unnamed: Q11.1 (E), R15.1, U16.5, U16.6, U16.10
unnamed: Q13.1 (E), Q15.1 (G), Q17.2 (B), Q18.2 (B)
unnamed: Q16.1 (E), R17.1
unnamed: Q17.1 (E), R18.2
unnamed: Q18.1 (E), R19.2
unnamed: U5.4 (OUT-), U6.3 (OUT+)
unnamed: U6.4 (OUT-), U7.3 (OUT+)
unnamed: U7.4 (OUT-), U8.3 (OUT+)
unnamed: U9.4 (OUT-), U10.3 (OUT+)
unnamed: U10.4 (OUT-), U11.3 (OUT+)
unnamed: U11.4 (OUT-), U12.3 (OUT+)
unnamed: U16.1, U16.9
unnamed: R11.2, R12.1, U17.2 (-)
unnamed: R16.1, U18.7 (DIS)
unnamed: C3.1, U18.6 (THR)
Reg Batt 9v: C2.2, Q15.2 (D), U2.3 (VI), U4.3 (OUT+)
Temp 1: R1.2, TH1.1, U14.4 (-), U15.4 (-)
Temp 2: R2.2, TH2.1, U14.6 (-), U15.6 (-)
Temp 3: R3.2, TH3.1, U14.10 (-), U15.10 (-)
Temp 4: R4.2, TH4.1, U14.8 (-), U15.8 (-)
Temp Logic Output: Q13.3 (C), Q14.1 (G), Q16.2 (B), U16.4, U16.8
Unreg Batt Out: R9.2, U4.2 (IN-), U5.3 (OUT+), U9.3 (OUT+)
charger Takeover VCC 9v+: J13.5, Q12.2 (D)

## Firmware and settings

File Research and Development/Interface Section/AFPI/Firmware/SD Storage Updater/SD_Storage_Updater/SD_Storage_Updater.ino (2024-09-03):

#include <SD.h>
#include <SPI.h>

#define SD_CS_PIN 10  // CS pin for Teensy Audio Shield SD card reader

// Embedded content of data.txt as a string. Ensure this matches exactly what you want to write to the SD card.
const char *dataContent = R"(
//Audio Processing
lineMix=0.0
backingMix=0.0
backingActive=false
currentAudioOutput=0
HPVol=0.0
HPGainOut=13
SPVol=0.0
SPGainOut=13
AUXVol=0.0
AuxGainOut=13

//Equaliser
EQActive=false
bassBand=0.0
midBassBand=0.0
midRangeBand=0.0
midTrebleBand=0.0
trebleBand=0.0

//EQ bass values
bassBoostActive=false
lr_lev=0.0
bass_lev=0.5
hpf_bypass=0
cutoff=6

//Current Page Sections
currentEQPage=0
currentAuxPage=0
currentHoverOption=0
currentEffect=2

//FX Sections

//distortion values
distortActive=false

//flange values
flangeActive=true
s_freq=0.5

//chorus values
chorusActive=true
n_chorus=2

//reverb values
reverbActive=true
revRoomsize=0.0
revDamping=0.0

//delay values
delayActive=true
delayTime=200

//rgb values
rgbActive=false
rgbBrightness=0.0
rgbColour=0
rgbEffect=0

//settings values
oledContrast=255
lowPwrMode=false
)";

void setup() {
  Serial.begin(9600);
  while (!Serial) {
    // Wait for Serial to initialize
  }

  // Initialize SD card
  if (!SD.begin(SD_CS_PIN)) {
    Serial.println("Failed to initialize SD card");
    return;
  }

  // Attempt to update the file on the SD card
  if (updateSDCardFile()) {
    Serial.println("File updated successfully on SD card!");
  } else {
    Serial.println("Failed to update the file on the SD card.");
  }
}

void loop() {
  // Main loop does nothing
}

// Function to update the SD card file with the embedded data content
bool updateSDCardFile() {
  // Open the target file on the SD card, create or truncate the existing file
  File targetFile = SD.open("/data.txt", FILE_WRITE);
  if (!targetFile) {
    Serial.println("Failed to open data.txt on SD card for writing.");
    return false;
  }

  // Write the embedded data content to the target file
  targetFile.print(dataContent);

  // Close the file
  targetFile.close();

  // Check if the file was written successfully
  return true;
}

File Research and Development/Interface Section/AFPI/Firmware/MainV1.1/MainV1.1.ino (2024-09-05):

#include "config.h"

#include "SD_card.h"
#include "audio_processing.h"
#include "display.h"
#include "rotary_encoder_ctrl.h"
#include "home_button.h"
#include "RGB_processing.h"
#include "low_pwr_mode.h"

#include "landing_page.h"
#include "settings_page.h"
#include "RGB_page.h"
#include "aux_pages.h"
#include "FX_pages.h"
#include "EQ_page.h"

void setup() {
  //Serial.begin(115200);
  //while (!Serial) delay(10);
  initializeDisplay();
  initialiseSDCard();
  initialiseAudio();
  //initialiseDistortion();
  pinMode(buttonPin, INPUT_PULLUP);
  Wire1.begin();
  initializeEncoders();
  initialiseRGB();
  lowPwrModeHandle();
}

void loop() {
  landingPage();
}

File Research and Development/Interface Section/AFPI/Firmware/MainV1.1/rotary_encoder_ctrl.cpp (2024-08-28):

#include "rotary_encoder_ctrl.h"

#include "config.h"
#include "display.h"

// Object definitions
Adafruit_seesaw ss = Adafruit_seesaw(&Wire1);
seesaw_NeoPixel pixels = seesaw_NeoPixel(4, SS_NEO_PIN, NEO_GRB + NEO_KHZ800, &Wire1);

// Encoder positions array
int32_t enc_positions[4] = {0, 0, 0, 0};

void initializeEncoders() {
    // Initialize the seesaw and NeoPixel
    if (!ss.begin(SEESAW_ADDR) || !pixels.begin(SEESAW_ADDR)) {
        while (1) delay(10); // Halt if initialization fails
    }

    // Verify the firmware version
    uint32_t version = ((ss.getVersion() >> 16) & 0xFFFF);
    if (version != 5752) {
        while (1) delay(10); // Halt if the wrong firmware is loaded
    }

    // Configure encoder switch pins with pull-up resistors
    ss.pinMode(SS_ENC0_SWITCH, INPUT_PULLUP);
    ss.pinMode(SS_ENC1_SWITCH, INPUT_PULLUP);
    ss.pinMode(SS_ENC2_SWITCH, INPUT_PULLUP);
    ss.pinMode(SS_ENC3_SWITCH, INPUT_PULLUP);
    
    // Enable GPIO interrupts for the encoder switch pins
    ss.setGPIOInterrupts(1UL << SS_ENC0_SWITCH | 1UL << SS_ENC1_SWITCH | 
                         1UL << SS_ENC2_SWITCH | 1UL << SS_ENC3_SWITCH, 1);

    // Initialize encoder positions and enable encoder interrupts
    for (int e = 0; e < 4; e++) {
        enc_positions[e] = ss.getEncoderPosition(e);
        ss.enableEncoderInterrupt(e);
    }

    // Configure and initialize NeoPixel
    pixels.setBrightness(255);
    pixels.show();
}

uint32_t Wheel(byte WheelPos) {
  WheelPos = 255 - WheelPos;
  if (WheelPos < 85) {
    return seesaw_NeoPixel::Color(255 - WheelPos * 3, 0, WheelPos * 3);
  }
  if (WheelPos < 170) {
    WheelPos -= 85;
    return seesaw_NeoPixel::Color(0, WheelPos * 3, 255 - WheelPos * 3);
  }
  WheelPos -= 170;
  return seesaw_NeoPixel::Color(WheelPos * 3, 255 - WheelPos * 3, 0);
}

int EncDialCheck(int encNo, float paramValue, float maxRange, float minRange) {
    int32_t enc_pos = ss.getEncoderPosition(encNo);
    if (enc_positions[encNo] != enc_pos) {
        int change = enc_pos - enc_positions[encNo];
        enc_positions[encNo] = enc_pos;

        

        if (change < 0 && paramValue < maxRange) {
            resetScreenSaver();
            return 2;
        } else if (change > 0 && paramValue > minRange) {
            resetScreenSaver();
            return 1;
        }
    }
    return 0;
}

void EncToggleCheck(bool& FXActive, AudioMixer4& mixer_sw) {
    if (!ss.digitalRead(SS_ENC3_SWITCH)) {

      resetScreenSaver();

      if (FXActive == false){
          FXActive = true;
          mixer_sw.gain(0, 0);
          mixer_sw.gain(1, 1);
      }
      else {
          FXActive = false;
          mixer_sw.gain(0, 1);
          mixer_sw.gain(1, 0);
      }         
    }

    while (!ss.digitalRead(SS_ENC3_SWITCH)) {
    delay(50);
    }
}

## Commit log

2024-06-01 Added pre existing ki kad files
    [AFR Board V1.kicad_pcb, AFR Board V1.kicad_sch, BMS MK2 attempt 1-using-Tp4506.kicad_pcb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]
2024-06-03 Finalised BMS schematic befeore testing PCB
    is rough design without considering guitar dimension, little EMI considerations. not all concepts in design have been ensured to work properly. will test each sections viability before testing entire Circuit.
    first design with the batterys and the circuit on the same board. initially had the idea of a 3d printed holder for the cells and a board on top.
    then 3 layers of single sided pcbs triple deckered with smd battery mounts. finally to this style.
    although the board is larger in width and length, the height is reduced which should permit a slot in battery design for the guitar rather than a large module with a rail on the side of the guitar fo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
    [BMS MK2.kicad_pcb, BMS MK2.kicad_sch, net report of v1 board.csv]
2024-06-03 transfering from pc to git
    [AFR Board V1.kicad_pcb, AFR Board V1.kicad_sch]
2024-06-03 Transfered more scripts, models, pcb files and docs over from PC
    [15watt amp circuit.kicad_pcb, 15watt amp circuit.kicad_sch, 2_Batterie_2.0.stl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]
2024-06-05 updated PCB and tidied up schematic BMS
    Not final version. will revamp the charger in with 5 pins, 1 power for charging and powering load.
    so charging section will be re implemented.
    more 3d models added to board, bms etc
    [BMS MK2.kicad_pcb]
2024-06-09 updated bms schem and pcb and added initial schem for charger
    fixed charging switch logic for bms board, updated jst conns and now instead uses the supply v as the sw V+ to turn off the mosfet to then charge. should work considering it takes 100ns ~ to switch. added caps in schem but still havent calculated their values, nor are they on the pcb.
    created the initial schematic from my notes for a charger that works in respect to the BMS board, is in the same cad file but different sheet to bms and is a seperate pcb.
    still need to finalise the caps and also determine pcb via diameters with what i have available and the size requirements. will follow the suggestion for via size from kicad foru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
    [BMS MK2.kicad_pcb, BMS MK2.kicad_sch, untitled.kicad_sch]
2024-06-09 updated trace constraints and updated existing traces on board to suit their current
    [BMS MK2.kicad_pcb]
2024-06-17 updated bms schem
    fixed polarity on batteries, updated jst conns to XH, created footprints for them, tidied up and shrunk the board size, changed from using the ds18d20b to a 10k ntc thermistor for temperature control protection
    [BMS MK2.kicad_pcb, BMS MK2.kicad_sch, battery power rocker switch head.FCStd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]
2024-07-18 redone bms board and added test bms schem and board to test functionality without the batteries
    added:
    - bms test schem and layout
    - updated bms
    - testing of quad rotary encoder breakout board
    - testing of teensy audio board
    - combining the encoders and audio board in 1 circuit with limited control of chorus fx with encoders
    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
    [BMS MK2.kicad_pcb, BMS MK2.kicad_sch, ProCo Rat.kicad_pcb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]
2024-07-24 V1 of interface program
    added home button, quad rotary encoders, oled screen and audio in infrastructure with basic code for loading screen, landing page with screen animations and toggling/ manipulating chorus, reverb and 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
    mix of serial print and oled screen for information for now. very messy code
    unrevised as of yet. will be utilising librarys to simplify source code
2024-07-24 failed custom library testing
    pushing to git for records and calling back for use one library usage is tackled properly
    [MainV1.ino]
2024-07-25 revised mainV1 interface 2.0
    revised fx screen layout. touched up some user experience parts such as remembering the last fx the user was on before returning home and highlighting the landing page cursor on loading. tidied up co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
    next revisions will be for the landing page to reuse some functions designed for the fx page for reading the encoders.
    next section of functionality to be added next will be the audio page to control the master volume, gain and switching of output between headphones and line out for speaker as base functions of secti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
2024-07-29 upgraded interface software
    improved controls of audio pages. streamlined more page processes for less code
    added SD card utilisation which reads a txt file on the card and sets all initial variables there stored values. continuing to work through updating values in the txt file and experementing with the method for uploading the data.
    currently the delay fx updates the file every time the delay time is increased which causes a delay (pun not intended) in the changing of the value.
    the other 3 FX use a still not working method that stores up to 3 different variables changed and their new values. if its changed again the same variable will be changed. once 3 is reached each of them are add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
    [bettie body design 1.FCStd]
2024-08-04 Updated SD Card Usage and designed PCB for AFPI Device
    Created a new method that reads all existing variables and updates all existing variables instead of only the ones that are updated to update all variables in the file. currently this is only actioned when the home button is pressed, however a regular interval update will be put in place to have the best chance of saving the values.
    the next thing to implement for the sd card is to create a temporary file to store the variables while writing it so that it can prevent corruption causing a loss of data so that there will always be a backup file.
    the AFPI Device V1.0 PCB is introduced as well to incorperate all the hardware into one circu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
    [AFPI Device V1.0.kicad_pcb, AFPI Device V1.0.kicad_sch]
2024-08-05 completed AFPI V1.1 Design
    Finished Design and ordered AFPI V1.1 Board
    tided up interface section on repository
    [AFPI Device V1.0.kicad_pcb, AFPI Device V1.0.kicad_sch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]
2024-08-15 Completed First Revision of AFPI design and Assembly
    Finished the initial design and g code generation of the top and bottom plates of the AFPI as well as the central enclosure. couldnt make gcode to fillet the exterior and interior edges as seen on th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
    Currently all packages for the AFPI have arrived and ive already produced the Top and Bottom plates. i took 2 takes fo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
    [2.42 OLED Display.step, 6mm SPDT Mini Toggle Switch.step, AFPI Device V1.1 BOM 2.csv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]
2024-08-25 restarted AFPI code development
    now with the device built, most of the features need their code written to test.
    have commented all serial comms to work without the connection and added the ability to take the line in input and mix it with a aux input, however the aux input audio quality is wierdly scrambled an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
    have begun testing an audio output switch to switch between the speaker amp, headphone out or aux out, and while the headphone and i believe the aux out will mute and unmute when not in use, the spea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
    testing the circuit the op amp recieves the 9 volts and when turning the gain and volume trim pots to the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
    [Expeditioner Model.FCStd]
2024-08-26 Solved Speaker Issue
    After reviewing the pcb layout and the schematic, and reviewing each component, i noticed that the pin outs on the symbol for the MPF102 on the schem didnt number the pins correctly to their functions. while the drain pin was wired correctly, the gate and source pins were reversed, causing it to not work properly. this mistake occured because i used a standard n channel JFET symbol and a generic TO-92 package during the design phase as kikad didnt have the MPF102 in its libraries, sourcing one was challenging and i just decided to use the generic symbol as it was the same.
    While i did check for the different pinouts as i was aware they vary from models, with the symbol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
    [AFPI Device V1.1.kicad_pcb]
2024-08-27 First round of modularisation of interface code.
    successfully incorperated the use of librarys in program to sperate different sections of the code, readability and will inevitably efficiency as the code was too long and complicated for one page. for now only the global variables and definitions, intitial setting up of program and the setup functions code have been removed, the loading screen display and sd card functionality with the sd card section being the only system to be fully modularised.
    for now there is still an over use of global variables and when each section is fully and properly seperated i can then start encapsulating the sections in classes etc. All in all good progress con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
    [MainV1.1.ino, display.cpp]
2024-08-28 second round of improving current interface code
    i have created all libraries neccesary for seperating sections of the program into their respective sections, for each of the page sections aswell as the peripherals code for initialising and sending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
2024-08-28 incorperation of new features to interface code
    added the following new features:
    - able to manipulate the OLED contrast to set the brightness of the screen in the settings section, currently between 0-255 in steps of 5 but will make it smaller in future for easier use
    - added screen saver functionality to count 10 seconds and if 10 seconds is reached, the screen is cleared and the program waits in pergatory for a interaction with the buttons/encoders. if one is pressed the the timer is reset and the code is returned the previously used function. whenever an encoder is turned or pushed or the home button is pushed the timer resets to 0 and starts counting again. currently works mostly althou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
    [FX_pages.cpp, MainV1.1.ino, RGB_page.cpp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]
2024-08-31 Completed Audio Output Control and updated SD card storage system
    Fixed all known bugs in audio output section, while the code for determining the current audio output and directing variable setting/carrying out gain/volume update is somewhat improper and isnt an elagent solution, it works as intended and correctly initialises the output and updates the correct values while seamlessly switching outputs.
    the sd card variables were also updated for not only the audio output section but also any other new features that hadnt had their variables added. this was done by also using AI to create for me a program that when run, rewrites over the data file on the sd card with content stored in the c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
    [SD_Storage_Updater.ino, aux_pages.cpp]
2024-09-03 introduced RGB control
    I soldered together 6 ws2812 LED's and fixed up the rgb connector wiring so that it wasnt in the way of the usb programming cable. i then programmed the interval timer to check when 20ms has passed during the normal operation of the program and if so then the lights are set to their appropriate values and effects. this allows the lighting to be dynamic during other processes, meaning it doesnt have be 1 solid colour and instead we can have many different styles of lighting.
    the initialisation of the leds was set up and incorperated as well as the neccesary variables added to the sd card storage system. from there i added a simple on off of a basic flowing effect that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
    [FX_pages.cpp, MainV1.1.ino, RGB_page.cpp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]
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2024-09-08 Completed Lighting Board and 3d Model of lighting assembly
    After finishing the minimum requirement code for the RGB lighting to function i have now designed the 2 PCBs that will house the LEDS as well as designed the mounting of these board for to the guitar along with its top plate.
    the PCBS are numbered 1 and 2, 1 being placed between the neck and middle single coil pickups and 2 being mounted between the middle and bridge pickups. board one is the main PCB as the output from the AFPI will be connected into that board via a JST connector, then through a capacitor to smooth power fluctuations and a resistor to limit the strength and noise of the data signal to the leds. for testing the led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
    [Lighting board and cover Plate assembly.FCStd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]
2024-09-18 designed and awaiting testing of Battery Circuit Design and Enclosure functionality
    i have fully simplified the batterys circuitry down to reduce the amount of time spent on the battery to be a little as possible to ensure the minimum requirements are met and that i ensure i meet th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
    [Battery final Rev.kicad_pcb, Battery final Rev.kicad_sch, Final Battery Design.FCStd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]
2024-09-23 updated battery enclosure design to v1.1
    after printing and testing the battery design i found multiple flaws in the design:
    - the pockets for the spring bolt, handle insert to bolt and bolt hole on top plate were too small and needed to be widened with files and a dremel.
    - the sleeve wasnt made big enough for a smooth slide and had to be 'broken in' and would get stuck and had to hammer out the battery.
    - the battery wasnt easy to remove as there was no proper grip to pull it out with.
    to fix these issues i resized the sleeve 0.7mm bigger on the sides and 0.5mm on the top for a smoother slide and the bolt was redesigned to more easily fit the handle into. 2 holes on either side of the sp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
    [Final Battery Design v1.1-Batterymain enclosure.stl, Final Battery Design v1.1.FCStd, Final Battery Design.FCStd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]
2025-05-16 Belated Commit of final Files after completed
    I actually completed this on the 31/12/2025 however due to busy new year it was forgotten to commit after the Guitar was completed. Very happy with how it turned out and have many future ideas to inc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
    [AFPI Mounts.FCStd, AFPI V2.kicad_pcb, AFPI V2.kicad_sch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]
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2025-07-03 Tidy up Repo
    [AFPI V2.kicad_pcb, AFPI V2.kicad_sch, Amp.kicad_sch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]
